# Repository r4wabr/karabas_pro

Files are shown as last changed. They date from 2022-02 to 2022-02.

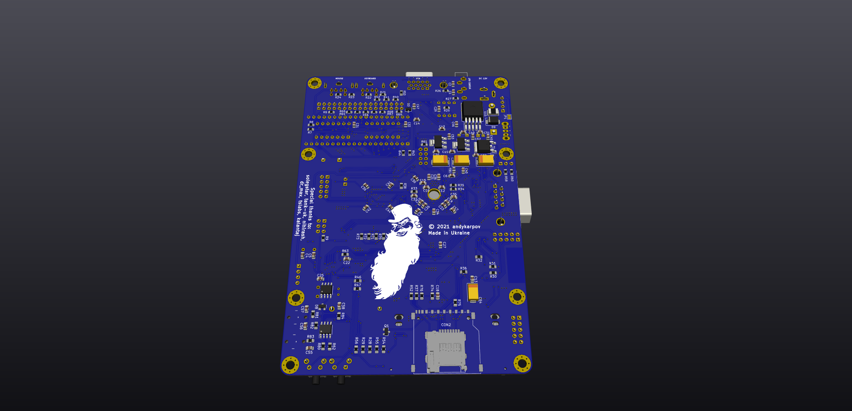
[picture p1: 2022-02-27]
docs/photos/karabas-pro-revDS-bot.png

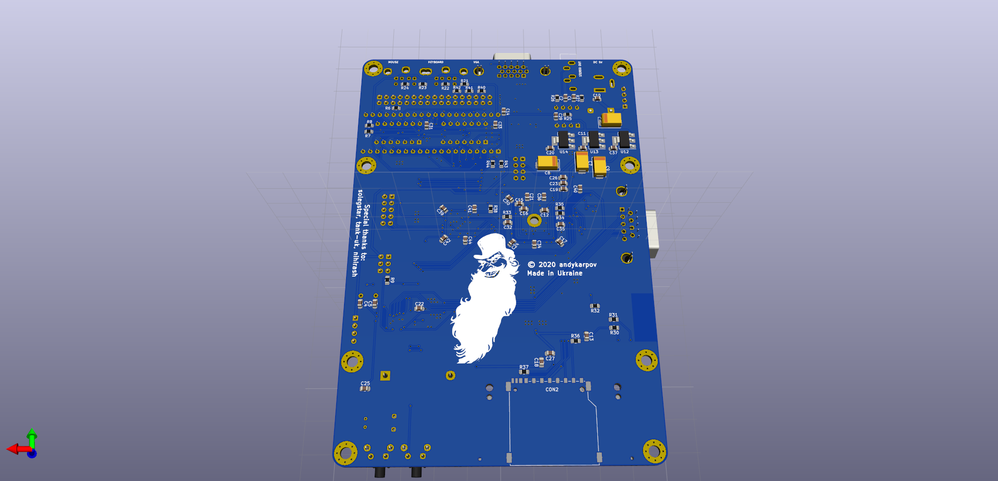
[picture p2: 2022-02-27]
docs/photos/karabas-pro-revB-bot.png

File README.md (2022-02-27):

# Karabas-Pro

**Yet another FPGA ZX Spectrum clone ;)**

## Intro

ZX Spectrum compatible machine with a soft CPU, FDD and HDD (CF card) controllers, PS/2 keyboard/mouse, ESP8266 UART, RTC, VGA output and all logic inside the Altera FPGA **EP4CE6**.

## The idea

The idea was to make a smaller Profi (Профи) ZX Spectrum clone, with real FDD and HDD controllers. The board size fits the dimensions of the real 3.5" floppy drive. 

## Firmwares

**The main firmware is finished and currently it implements:**

1) ZX Spectrum classic and profi hi-res hi-color mode (with palette) (512x240)
2) ZX Profi CMR ports for extended peripherial
3) FDD controller that works both in CP/M and classic modes
4) HDD controller (works in Profi CP/M mode and PQ-DOS mode)
5) PS/2 keyboard (XT keyboard emulation)
6) PS/2 mouse (kempston mouse and serial MS mouse emulation)
7) VGA output (requires a monitor with 50Hz support)
8) Turbosound (2 x AY-3-8912), Soundrive and SAA1099 (SAA will work only on EP4CE10 due to lack of free LEs in EP4CE6)
9) Kempston joystick support
10) SEGA joystick support
11) RTC (profi), emulated read/write support
12) SD card access via Z-Controller emulation
13) Turbo 7 MHz (and Turbo 14 Mhz on EP4CE10)
14) ZX UNO simple UART @115200 for ESP8266 module (a secondary ZX UNO UART available on uBus connector for EP4CE10)
15) An additional ROM bank with **PQ-DOS BIOS**
16) An additional ROM bank with **Flash Tool** by **Doctor Max** to upgrade the FGPA firmware and ROM banks without programmer
17) An additional ROM bank with **FDImage Tool** by **Doctor Max** to extract TRD, SCL, PRO, TD0 and FDI images on real floppies
18) OSD menu
19) OSD full-screen overlay with easy-to-change options, RTC setup, etc.

## More info

**ERRATA for PCB rev.A:** [See ERRATA Rev.A](https://github.com/r4wabr/karabas_pro/blob/master/ERRATA-REVA.md).

**ERRATA for PCB rev.B:** [See ERRATA Rev.B](https://github.com/r4wabr/karabas_pro/blob/master/ERRATA-REVB.md).

**ERRATA for PCB rev.С:** [See ERRATA Rev.С](https://github.com/r4wabr/karabas_pro/blob/master/ERRATA-REVC.md).

**Latest stable revision:** rev.DS'.

**Latest development revision:** rev.E.

**PCB changelog:** [PCB changelog](https://github.com/r4wabr/karabas_pro/blob/master/CHANGELOG-PCB.md).

**Profi firmware** [Download a Profi firmware](https://github.com/r4wabr/karabas_pro/tree/master/firmware/releases/profi).

### Pre-production renders:





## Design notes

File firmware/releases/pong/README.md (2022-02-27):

# Karabas-Pro Pong firmware

## A simple Pong game (backport from ZX EVO)

### Keyboard controls:

**Left player:**
- Q - move up
- A - move down 

**Right player:**
- P or joystick up - move up
- L or joystick down - move down

**Global keys:**
- Space or Ctrl+Alt+Del - restart game
- Menu+F11 - toggle the scanlines effect

## How to flash FPGA and CPLD things

1) Open Quartus Programmer file karabas_pro_pong.cdf
2) Check all chips you want to flash (EPM3128, EP4CE6 and it's configuration device EPCS16), then click Program button

## How to flash the AVR microcontroller:

Use any available programmer, like avrdude.

**Fusebits**

- Low: 0xFF
- High: 0xD7
- Extended: 0xFF

### Example usage:

`avrdude -c usbasp -p m328p -U flash:w:karabas_pro.hex -U lfuse:w:0xFF:m -U hfuse:w:0xD7:m`

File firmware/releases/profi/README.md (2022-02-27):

# Karabas-Pro Profi firmware

## How to flash FPGA and CPLD things

1) Open Quartus Programmer file target/karabas_pro_target_tda1543.cdf or target/karabas_pro_target_tda1543a.cdf (depends of the DAC model on your board)
2) Check all chips you want to flash (EPM3128, EP4CEXX and it's configuration device EPCS16), then click Program button

## How to flash the AVR microcontroller:

Use any available programmer, like avrdude.

Please flash the karabas_pro_revD.hex for PCB rev.D and higher, karabas_pro.hex only on PCBs rev.C or rev.A/rev.B with additional pullup resistors on SW1, SW2 buttons.
Otherwise please flash karabas_pro_revA.hex with hardware buttons disabled.

**Fusebits**

- Low: 0xFF
- High: 0xD7
- Extended: 0xFF

### Example usage:

`avrdude -c usbasp -p m328p -U flash:w:karabas_pro_revD.hex -U lfuse:w:0xFF:m -U hfuse:w:0xD7:m`

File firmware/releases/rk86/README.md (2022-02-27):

# Karabas-Pro Radio-86RK firmware

## How to flash FPGA and CPLD things

### For PCB rev.A and rev.B:

1) Open Quartus Programmer file karabas_pro_rk86_revA_tda1543.cdf or karabas_pro_rk86_revA_tda1543a.cdf (depends on the DAC model on your board)
2) Check all chips you want to flash (EPM3128, EP4CE6 and it's configuration device EPCS16), then click Program button

### For PCB rev.C and up:

1) Open Quartus Programmer file karabas_pro_rk86.cdf
2) Check all chips you want to flash (EPM3128, EP4CE6 and it's configuration device EPCS16), then click Program butt

## How to flash the AVR microcontroller:

Use any available programmer, like avrdude.

**Fusebits**

- Low: 0xFF
- High: 0xD7
- Extended: 0xFF

### Example usage:

`avrdude -c usbasp -p m328p -U flash:w:karabas_pro.hex -U lfuse:w:0xFF:m -U hfuse:w:0xD7:m`

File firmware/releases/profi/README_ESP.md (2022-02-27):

# Updating ESP8266 stock firmware

## How to update ESP8266 stock AT firmware

For some reason, a stock firmware may be outdated and incompatible with the uGoph browser by nihirash.
So, it's easy to update that module without desoldering.

### What you'll need

- The latest release of the AT firmware, better to grab it from the official espressif github repo, like https://github.com/espressif/ESP8266_NONOS_SDK/releases/tag/v3.0.4. Then download and unpack it. The desired AT firmware is under the `bin` folder
- esptool script or other esp8266 flash tool
- An USB-UART module with 3.3v levels

### Step-by-step instruction

1) Open Quartus Programmer file `karabas_pro_esp_bridge.cdf` and flash a service firmware into FPGA, power off the board
2) Connect your USB-UART module: RX pin to PIN_121, TX pin to PIN_141, GND to GND
3) Solder a bridge between GND and the esp8266 GPIO0 pin, restart the board
4) detect a flash chip size by calling the esptool like this: `esptool --port /dev/ttyUSB0 flash_id`
5) For 32Mbit flash use the following command: `esptool --port /dev/ttyUSB0 --baud 115200 write_flash -fm qio -ff 40m -fs 16m-c1 0x00000 boot_v1.7.bin 0x01000 at/1024+1024/user1.2048.new.5.bin 0x1fc000 esp_init_data_default_v08.bin 0xfe000 blank.bin 0x1fe000 blank.bin`
6) You're done. Disconnect the power, desolder a solder bridge, flash a normal karabas_pro firmware (depends on your board revision) into the FPGA
7) Now follow the instructions how to use your ESP8266 module ;)

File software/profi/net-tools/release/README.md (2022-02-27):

Сетевые утилиты для Karabas PRO
===============================

На данный момент они работают только с SD-картой, и им критично расположение в каталоге Wifi(т.е. необходимо скопировать netman.$c, ugophy.$c и player.bin в каталог wifi, находящийся в корне SD-карты).

У утилит нет зависимости от CP/M или PQ-DOS - используется загружаемый FatFS. 

Запускаются утилиты сразу из fatall'а.

Для настройки ESP и подключения к точке доступа используется netman - он проведет инициализацию чипа, получит список сетей и предложит вам выбрать нужную. 

Если там пролетит сообщение ERROR - это нормально. 

После настройки уже можно запускать ugophy и пользоваться им. Как только на экране появится приветственная страница - это означает, что вы уже онлайн(она грузится по сети).

Возможность скачивания файлов присутствует - пользуйтесь ей на здоровье.

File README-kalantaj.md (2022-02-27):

# Инструкция по прошивке Karabas-Pro для Kalantaj

## Как прошить FPGA и CPLD в карабас-про

0) Воткни USB Blaster в 10-контактный разъем
1) Открой в Quartus Programmer файл karabas_pro_tda1543.cdf или karabas_pro_tda1543a.cdf (зависит от того, какой у тебя ЦАП на плате)
2) Отметь галочками, какие чипы (все) шьешь (EPM3128, EP4CE6, EPCS16 итп), затем жмякай на Program button

## Как прошить мегу:

Воткни свой программатор в 6-контактный разъем

Шей файл karabas_pro.hex, если у тебя ревизия платы C.
Шей файл karabas_pro_revA.hex, если у тебя старая revA без доделок.
Шей файл karabas_pro_revD.hex, если у тебя новая rev.D с кучей светиков.

**Фьюзы**

(Если у тебя не дудка, а другой софт - просто выставляй фьюзы)

- Low: 0xFF
- High: 0xD7
- Extended: 0xFF

### Пример вызова дудки:

`avrdude -c usbasp -p m328p -U flash:w:karabas_pro.hex -U lfuse:w:0xFF:m -U hfuse:w:0xD7:m`

Важно: efuse можно не шить, с ним бывают траблы.
Тогда так: `avrdude -c usbasp -p m328p -U flash:w:karabas_pro.hex -U lfuse:w:0xFF:m -U hfuse:w:0xD7:m`

После шитья - передерни. питание.

Все :)

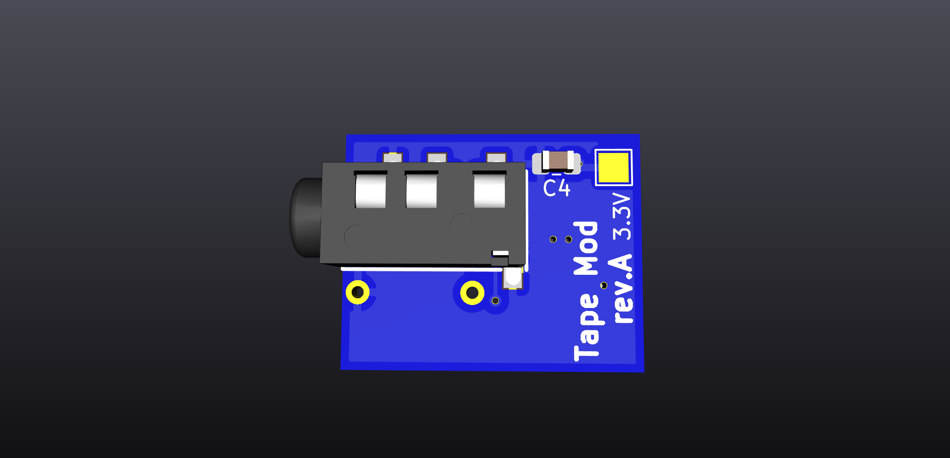
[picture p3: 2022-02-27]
docs/photos/karabas-pro-tapeMod_revA-top-3d.png

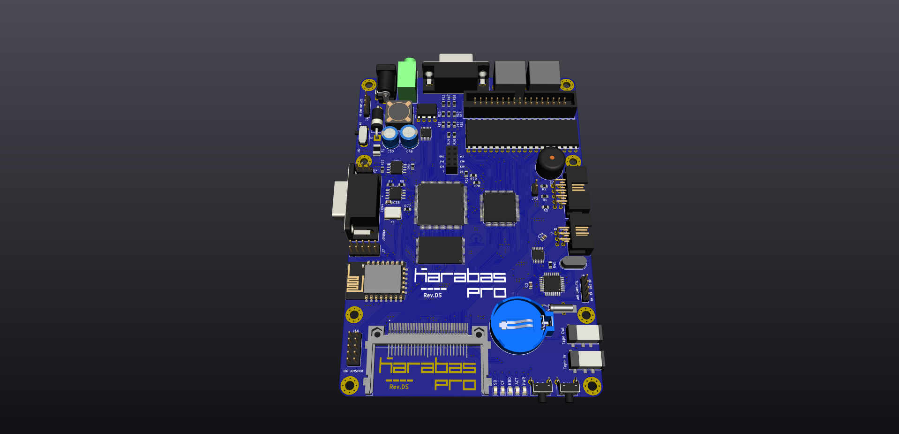
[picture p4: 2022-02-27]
docs/photos/karabas-pro-revDS-top.png

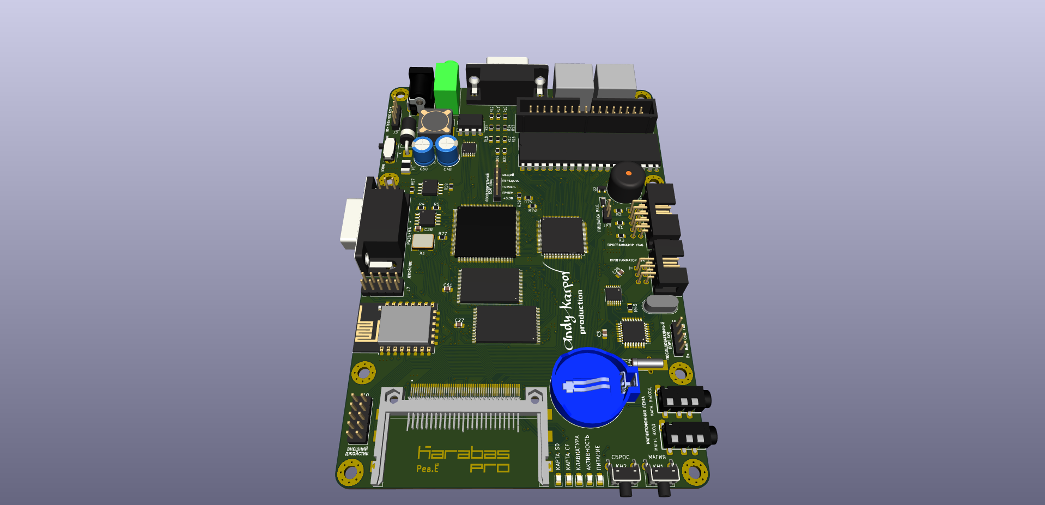
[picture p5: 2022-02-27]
docs/photos/karabas-pro-revER-top.png

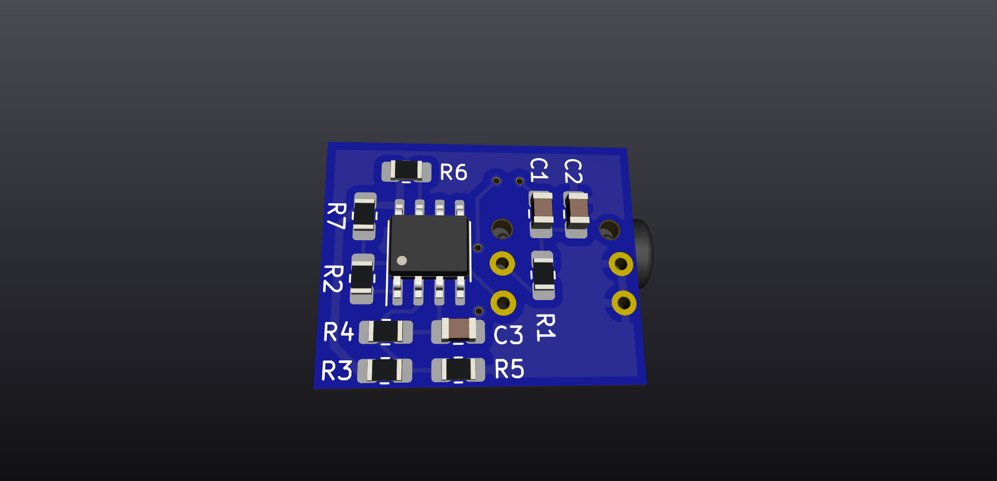
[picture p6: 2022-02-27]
docs/photos/karabas-pro-tapeMod_revA-bottom-3d.png

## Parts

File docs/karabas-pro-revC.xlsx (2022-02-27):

Ref | Q-ty | Value | Footprint
BT1, | 1 | 3V | CR2032 Battery holder
C10, C11, C12, C13, C14, C15, C16, C17, C18, C19, C20, C21, C22, C23, C24, C25, C26, C27, C28, C29, C30, C31, C32, C33, C34, C35, C36, C37, C38, C39, C40, C41, C42, C43, C44, C46, C47, | 37 | 100n | C0805
C1, C2 | 2 | 10uF | C0805
C3, | 1 | 1uF | C0805
C4, C5, | 2 | 22p | C0805
C6, C7, C8, C9, | 4 | 10uF | Tantalum D
C45, | 1 | 470uF | CP_D12.5mm_P7.50mm
CON1, | 1 | CF-CARD | TE_1734451-1
CON2, | 1 | SD | SD_TE_2041021
CON3, | 1 | VGA | DSUB-15-HD_Female
CON4, | 1 | Joystick | DSUB-9_Male
CON5, | 1 | Keyboard | MDIN06SS
CON6, | 1 | Mouse | MDIN06SS
CON7, | 1 | Audio | Jack_3.5mm_CUI_SJ1-3535NG
CON8, | 1 | 5V DC | BarrelJack_Wuerth_6941xx301002
CON9, | 1 | Micro-SD | Molex MicroSD (mirrored)
D1, | 1 | LED1 | L0805
D2, | 1 | LED2 | L0805
D3 | 1 | BAT54C | SOT-23
J1, | 1 | Floppy | IDC-Header_2x17
J2, | 1 | FPGA JTAG | IDC-Header_2x05, angled
J3, | 1 | Floppy 5V | PinHeader_1x04
J4, | 1 | uBus | PinHeader_2x04
J5, | 1 | AVR JTAG | IDC-Header_2x03, angled
J6, | 1 | AVR UART | PinHeader_1x04
R1, R2, R3, | 3 | 2k4 | R0805
R4, | 1 | 27 | R0805
R5, R9, R30, R31, R32, R33, R34, R35, R36, R37, R38, R39, R40, R41, R42, R43, R44, R45, R46, R47, R48, R49, R50, R51, R52, | 25 | 10k | R0805
R6, R11, R14, R17, | 4 | 1k | R0805
R7, R8, R21, R22, R23, R24, | 6 | 4k7 | R0805
R10, R13, R16, | 3 | 1k8 (2k) | R0805
R12, R15, R18, R28, R29, | 5 | '470 (510) | R0805
R19, R20, | 2 | 75 | R0805
R25, | 1 | 820 | R0805
R26, R27, | 2 | 750 | R0805
SW1, SW2, | 2 | SW_Push | SPST_Angled_PTS645Vx58-2LFS
SW3 | 1 | SW_DIP_x04 | SPSTx04_Piano_CTS_Series
U1, | 1 | EP4CE6E22C8N | QFP-144
U2, | 1 | CY62167EV30 (ELL) | TSOP-I-48_18.4x12mm_P0.5mm
U3, | 1 | EPCS16 | M25P16 | SOIC-8_5.23x5.23mm_P1.27mm
U4, | 1 | EPM3128ATC100 | LQFP-100_14x14mm_P0.5mm
U5, | 1 | ATMEGA328-AU | TQFP-32_7x7mm_P0.8mm
U6, | 1 | MB8877A | DIP-40_W15.24mm
U7, U8, | 2 | TXB0104PW | TSSOP-14_4.4x5mm_P0.65mm
U9, | 1 | DS1307Z+ | SOIC-8_3.9x4.9mm_P1.27mm
U10, | 1 | ESP-12E | ESP-12E
U11, | 1 | TDA1543 | DIP-8_W7.62mm
U12, | 1 | AMS1117-3.3 | SOT-223-3
U13, | 1 | AMS1117-2.5 | SOT-223-3
U14, | 1 | AMS1117-1.2 | SOT-223-3
U17, | 1 | 74LS06 | DIP-14_W7.62mm
U18, | 1 | 74LS38 | DIP-14_W7.62mm
X1, | 1 | 50MHz | SG8002CA-4Pin_7.0x5.0mm
Y1, | 1 | 32768Hz | AT310_D3.0mm_L10.0mm
Y2, | 1 | 16MHz | HC49-S

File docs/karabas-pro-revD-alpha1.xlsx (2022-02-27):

Ref | Q-ty | Value | Footprint
BT1, | 1 | 3V | CR2032 Battery holder
C11, C12, C13, C14, C15, C16, C17, C18, C19, C20, C21, C22, C23, C24, C25, C26, C27, C28, C29, C30, C31, C32, C33, C34, C35, C36, C37, C38, C39, C40, C41, C42, C43, C44, C46, C47, C49, C51, | 38 | 100n | C0805
C1, C2 | 2 | 10uF | C0805
C3, | 1 | 1uF | C0805
C4, C5, | 2 | 22p | C0805
C7, C8, C9, | 3 | 10uF | Tantalum D
C48 | 1 | 470uF | CP_Radial_D8.0mm_P3.80mm
C50 | 1 | 220uG | CP_Radial_D7.5mm_P2.50mm
CON1, | 1 | CF-CARD | TE_1734451-1
CON2, | 1 | SD | SD_TE_2041021
CON3, | 1 | VGA | DSUB-15-HD_Female
CON4, | 1 | Joystick | DSUB-9_Male
CON5, | 1 | Keyboard | MDIN06SS
CON6, | 1 | Mouse | MDIN06SS
CON7, | 1 | Audio | Jack_3.5mm_CUI_SJ1-3535NG
CON8, | 1 | 5V DC | BarrelJack_Wuerth_6941xx301002
CON9, | 1 | Micro-SD | Molex MicroSD (mirrored)
D1, D2, D4, D6, D7 | 5 | LED | L0805
D5 | 1 | 1N5820 | D_DO-201AD_P15.24mm_Horizontal
D3 | 1 | BAT54C | SOT-23
J1, | 1 | Floppy | IDC-Header_2x17
J2, | 1 | FPGA JTAG | IDC-Header_2x05, angled
J3, | 1 | Floppy 5V | PinHeader_1x04
J4, | 1 | uBus | PinHeader_2x04
J5, | 1 | AVR JTAG | IDC-Header_2x03, angled
J6, | 1 | AVR UART | PinHeader_1x04
J7, | 1 | ESP-BUS | PinHeader_2x05
JP2 | 1 | Jumper | PinHeader_1x03
L1, | 1 | 68uH | L_12x12mm
R1, R2, R3, | 3 | 2k4 | R0805
R4, R57 | 2 | 27 | R0805
R5, R9, R30, R31, R32, R33, R34, R35, R36, R37, R38, R39, R40, R41, R42, R43, R44, R45, R46, R47, R48, R49, R50, R51, R52, R58, R59, R60, | 28 | 10k | R0805
R6, R11, R14, R17, | 4 | 1k | R0805
R7, R8, R21, R22, R23, R24, | 6 | 4k7 | R0805
R10, R13, R16, | 3 | 2k | R0805
R12, R15, R18, R28, R29, R54, R55, R56, | 8 | '470 (510) | R0805
R53 | 1 | X* (see schematics) | R0805
R19, R20, | 2 | 75 | R0805
R25, | 1 | 820 | R0805
R26, R27, | 2 | 750 | R0805
R61, | 1 | 300 | R0805
SW1, SW2, | 2 | SW_Push | SPST_Angled_PTS645Vx58-2LFS
SW3 | 1 | SW_DIP_x04 | SPSTx04_Piano_CTS_Series
SW4 | 1 | SW_SPST | Slider button switch
U1, | 1 | EP4CE6E22C8N | QFP-144
U2, | 1 | CY62167EV30 (ELL) | TSOP-I-48_18.4x12mm_P0.5mm
U3, U3''1 | 2 | W25Q16 | M25P16 | SOIC-8_5.23x5.23mm_P1.27mm
U4, | 1 | EPM3128ATC100 | LQFP-100_14x14mm_P0.5mm
U5, | 1 | ATMEGA328-AU | TQFP-32_7x7mm_P0.8mm
U6, | 1 | MB8877A | DIP-40_W15.24mm
U7, U8, | 2 | TXB0104PW | TSSOP-14_4.4x5mm_P0.65mm
U9, | 1 | DS1307Z+ | SOIC-8_3.9x4.9mm_P1.27mm
U10, | 1 | ESP-12E | ESP-12E
U11, | 1 | TDA1543 | DIP-8_W7.62mm
U12, | 1 | AMS1117-3.3 | SOT-223-3
U13, | 1 | AMS1117-2.5 | SOT-223-3
U14, | 1 | AMS1117-1.2 | SOT-223-3
U15, | 1 | LM2596S-5.0 | TO-263-5
U17, | 1 | 74LS06 | DIP-14_W7.62mm
U18, | 1 | 74LS38 | DIP-14_W7.62mm
X1, | 1 | 50MHz | SG8002CA-4Pin_7.0x5.0mm
Y1, | 1 | 32768Hz | AT310_D3.0mm_L10.0mm
Y2, | 1 | 16MHz | HC49-S

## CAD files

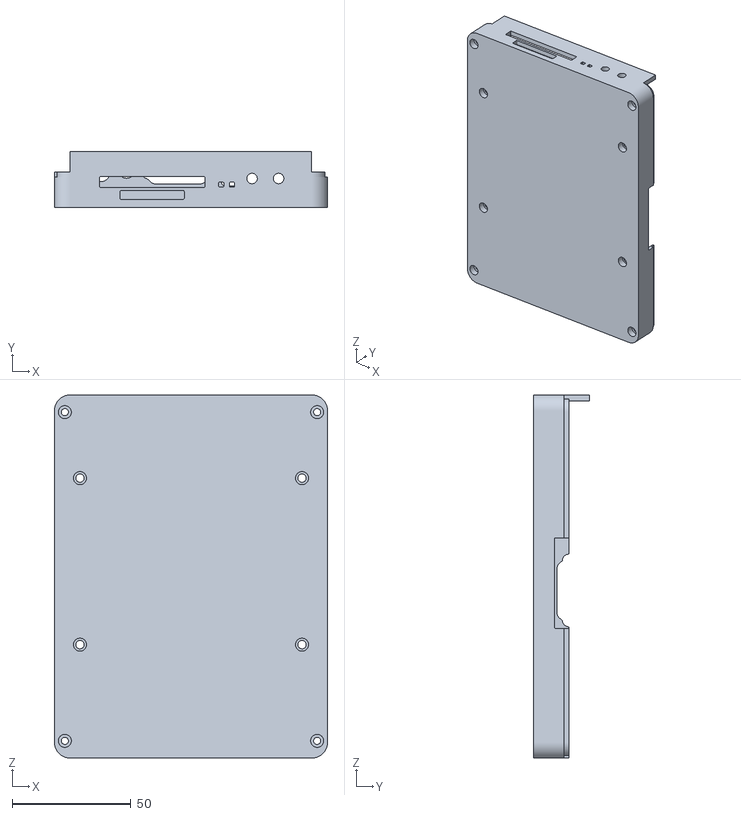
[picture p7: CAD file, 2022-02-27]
cases/revC/Karabas_case_FDD_bottom_v1.stl
115.0 x 23.5 x 152.8

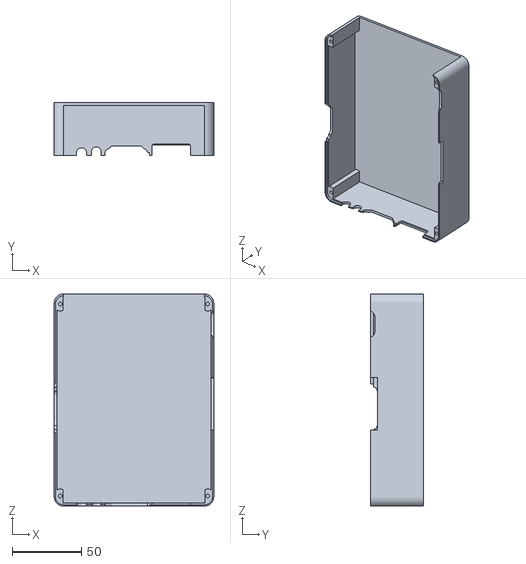
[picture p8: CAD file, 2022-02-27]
cases/revDS/KarabasDS_FDD_Logo_case_top_v1.0.stl
115.0 x 38.1 x 152.8

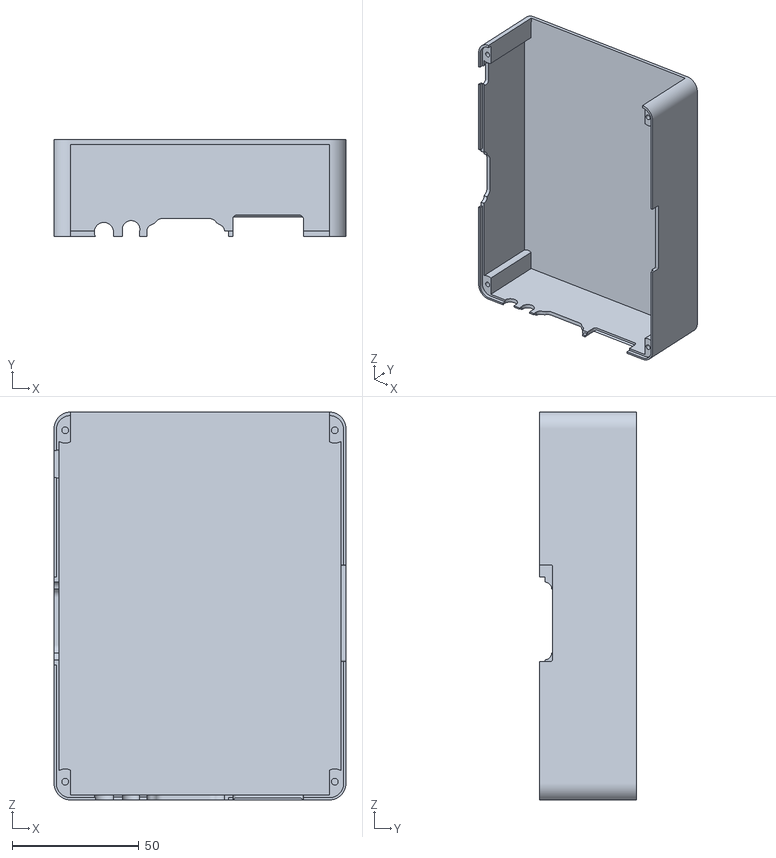
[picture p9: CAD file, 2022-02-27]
cases/revC/Karabas_case_FDD_Logo_top_v1.stl
115.0 x 38.0 x 152.8

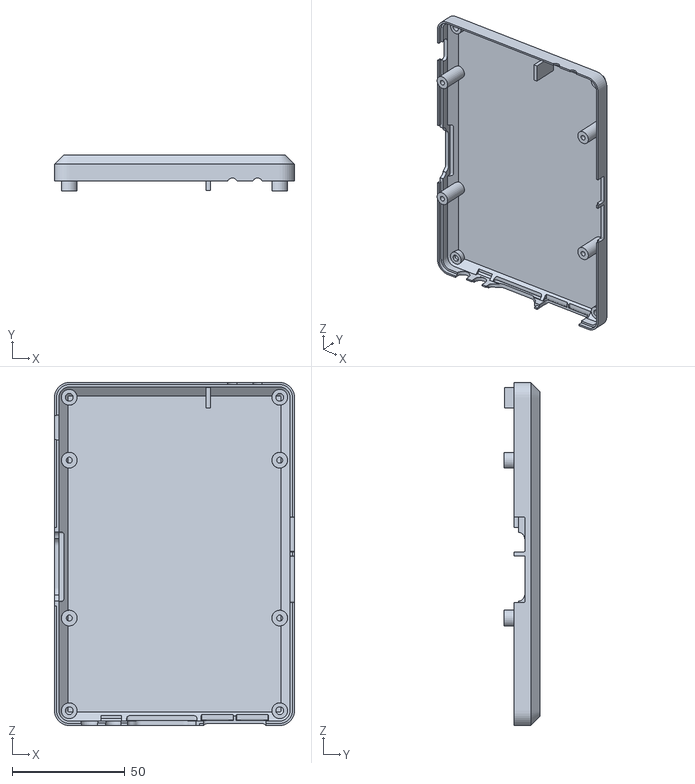
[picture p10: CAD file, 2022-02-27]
cases/revC/Karabas_case_top_v1.2.stl
106.6 x 15.8 x 152.3

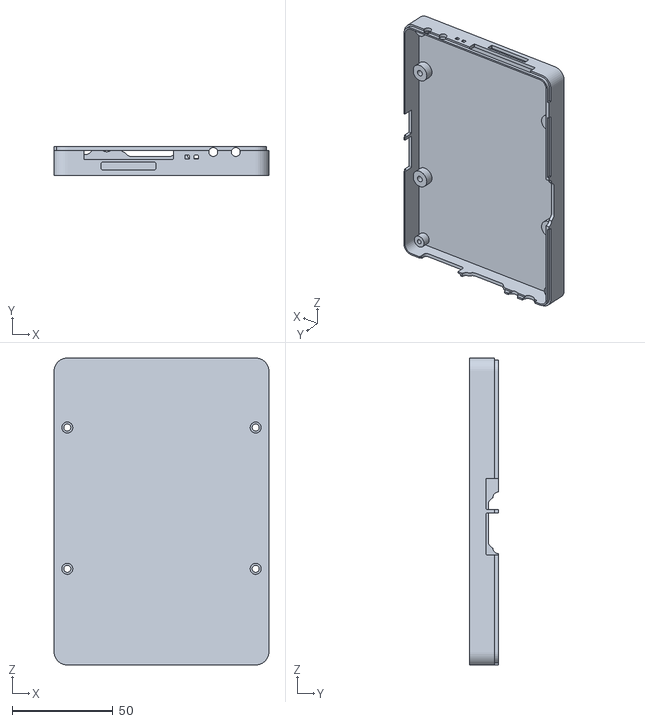
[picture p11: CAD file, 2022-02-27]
cases/revC/Karabas_case_bottom_v1.2.stl
106.6 x 14.4 x 152.3

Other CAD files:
cases/revDS/KarabasDS_FDD_case_bottom_v1.0.stl
cases/revC/Karabas_case_FDD_top_v1.stl
cases/revC/Karabas_case_FDD_bottom_Support_v1.stl

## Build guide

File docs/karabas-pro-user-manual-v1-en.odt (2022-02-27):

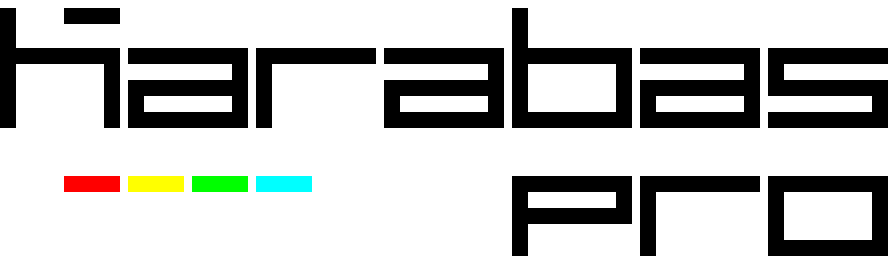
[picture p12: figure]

User’s Manual

v1.0

# Intro

Dear user! Welcome to the retro computers world!

You’re reading a Karabas-Pro development board user’s manual. You’ll be able to recreate one of the famous 8-bit computers from 199x – ZX Spectrum compatible machine named Profi2+.

The following manual will be useful for people who is making the board from scratch or for the already assembled and working board owners.

The project is open-source, licensed by the Open Source Hardware License. All the source code, including the pcb design and firmware are located in git repository - https://github.com/andykarpov/karabas-pro. Feel free to join and collaborate with the project. Let’s make it better ;)

One of the main feature of this project, that highlights it from the others FPGA-based clones is the real floppy disk drive and a hard disk drive (Compact Flash, actually) controllers, so you can use a real floppy disks or Gotek emulator with this board and all the software written for the disked ZX Spectrum and Profi CP/M (Microdos).

To start you’ll need the following:

- VGA compatible monitor with 50Hz support or TV with RGB inputs
- 12V 2A DC power supply for boards starting from Rev.D (center contact – positive) or 5V 2A DC for boards Rev.A...Rev.C.
- PS/2 keyboard and PS/2 mouse
- Sound output device (headphones or active speakers, etc.)
- Mechanical Atari-like joystick or SEGA 3/6 buttons gamepad.
- CF-card (not all vendors are good. Better to choose a Sandisk with 2-8Gb capacity)
- SD-card
- 3.5” spectrum-ready floppy disk drive or Gotek emulator with FlashFloppy firmware
- Some amount of time and patience :)

If the board is not flashed, you’ll also need:

- Altera USB Blaster, byte blaster or other compatible programmer
- AVR programmer (USBasp, TinyISP or other with 6-pin interface)
- Quartus Programmer software to flash the CPLD and FPGA
- avrdude or similar software to flash AVR chip

## Board description

Karabas-Pro PCB fits into the 3.5” floppy drive dimensions. You will be able to mount the floppy disk drive using the board’s mounting holes.

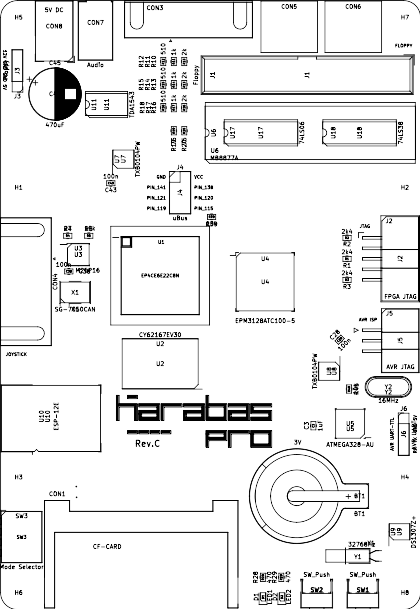
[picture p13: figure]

The PCB contains the following main components:

- FPGA Altera EP4CE10 on the latest revisions, EP4CE6 for older revisions.
- Configuration flash EPCS16 (M25P16, W25Q16, ...)
- CPLD Altera EPM3128
- Static RAM 2MB (6MB on development rev.E)
- FDD conttoller (BDI) based on the MB8877A chip
- PS/2 keyboard, mouse and RTC supported by Atmega 328P controller
- Audio DAC TDA1543 (or TDA1543A)
- SD card connector
- CF card connector
- DB9 connector for the mechanical (Atari) or SEGA joystick

## What’s the current firmware can do

The current firmware is releasing for all pcb revisions (A,B,C,D, DS, E), and is able to recreate the following hardware:

- Profi machine with all specific control ports (CMR0, CMR1)
- T80 soft processor
- 1 MB of RAM by Profi standard (port #dffd)
- RGB 15kHz or VGA 30kHz 50Hz video output
- Pentagon video mode (320 lines, 49 Hz)
- Profi video mode (512x240, 50 Hz)
- Profi 16-color palette
- Turbosound emulation (2x AY-3-8912)
- Profi covox and Soundrive emulation
- SAA1099 sound chip emulation (only available for EP4CE10 FPGA yet)
- XT keyboard emulation (via the 5th bit of the port #FE)
- Kempston mouse and serial mouse implementation (via the COM1 serial port emulation)
- RTC support
- ZXUNO based UART to access ESP8266 at 115200bps
- 4 switchable rom banks
- Turbo mode 7MHz
- Experimental support for 60Hz vertical refresh rate
- TurboWG mode (speed up the FDD head movements)
- New ports decoding scheme to support a modern PQ-DOS operating system
- OSD menu to easy setup a system parameters, including RTC chip

## How it works

After switching on a power to the board, the FPGA will read and start a configuration from the SPI flash device. Then the loader will start a logic to copy the ROMs into the upper area of RAM using a direct access to the RAM. The machine is in the reset state during this operation. After copying all the ROMs into the RAM, a forced reset signal is triggered to start the machine. Now it’s ready to work.

In parallel with the boot process the AVR micro controller initializes the keyboard, mouse and RTC chip. Also the controller will copy the contents of all registers of the RTC chip into FPGA by SPI bus (the controller is always master, FPGA side is a slave). Then the controller sends the keyboard matrix content, mouse and joystick events to the FPGA side in the infinite loop, as well as once per second it sends the RTC time registers.

The external peripherial devices (BDI, HDD) are serviced by the CPLD Altera EPM3128. All required ZX-BUS signals are transferred between FPGA and CPLD by internal parallel 16-bit controlled bus.

# PCB

The PCB is released on the two-sided FR4 1.6mm board. The dimensions are: 147 x 101 mm.

## Connectors

- CON8 – 5 x 2.1 mm DC socket to power the board (5V 2A for revisions A,B,C,C1, 12V 2A for revisions D, DS, E and higher)

- CON7 – 3.5 mm audio jack (TRS)

- CON3 – 15-pin D-SUB to connect VGA monitor or TV (via VGA-to-SCART cable)

- CON5 – Mini Din 6 to connect a PS/2 keyboard

- CON6 – Mini Din 6 to connect a PS/2 mouse

- CON4 – 9-pin D-SUB to connect a machanical Atari-like joystick

- CON1 – 50-pin slot to connect a Compact Flash memory card as HDD storage

- CON2 – an SD card slot

- J6 – 4-pin header AVR UART (5V TTL)

- J5 – 6-pin shrouded header for AVR ISP

- J2 – 10-pin shrouded header for JTAG (both FPGA and CPLD, they are chained)

- J4 – 8-pin general purpose connector (free pins from the FPGA)

- J3 – 4-pin header to power the FDD from the board

## Buttons and switches

- SW1, SW2 – general purpose tact buttons. Currently – unused for rev.A, B. For rev.C and higher – it’s a hard reset and hard reset + S buttons (to enter the internal keyboard port test).

- SW3 – debug dip switches (deprecated, on the latest revision, starting from rev.DS a tape in/out is implemented on those pins)

# Keyboard

The keyboard can work in 2 modes:

- Extended PC XT keyboard

- Classic ZX Spectrum 40-pin keyboard

The extended mode uses an additional bit of port #FE to transfer a functional and extended keys.

## Hotkeys

- Menu + F1 – switch to ROMSET 0 – a standard Profi ROM with Service 2.3 and embedded FatAll software by Savelij

- Menu + F2 – switch to ROMSET 1 – an alternative Profi ROM with PQ-DOS BIOS

- Menu + F3 – switch to ROMSET 2 - FlashTool by Doctor Max

- Menu + F4 – switch to ROMSET 3 - Diag ROM

- Menu + F5 – toggle the TurboFDC state (for boards rev.D alpha 2 and higher)

- Menu + F7 – toggle the SSG stereo mode (ABC / ACB / mono)

- Menu + F8 – toggle the emulated SSG chip type (AY / YM)

- Menu + F9 – toggle the VGA / TV modes

- Menu +F10 – toggle the vertical refresh rate – 50Hz / 60Hz

- Menu + F11 – toggle the Turbo mode 7MHz / normal 3.5MHz

- Menu + F12 – toggle the NMI event to the CPU

- PrtScr – switch the keyboard mode between a standard 40-key and the extended PC XT mode

- Pause – stops the CPU by /WAIT signal

- Ctrl+Alt+Del – throws a RESET signal

- Ctrl+Alt+Esc – throws a NMI signal

- Ctrl+Alt+Backspace – throws a RESET signal + S button to enter the internal keyboard port test service (available only in ROMSET 0)

- Menu + Tab – swaps the FDC drive letters from A<>B

- Menu + ESC – toggle the OSD menu

# Board assembly guide

In this chapter a community experience to assemble and start the machine is collected. Reading this part of manual is not guaranteed to the success, but will close it as much as possible.

## The components

It’s very important to source the electronic components from the confirmed sellers to avoid non-working or partially-working results. The author had a bad experience with many AliExpress sellers multiple times.

## Assembly

Before starting the assembly process – please carefully inspect the PCB. The factory optical and electric control is not enough. Please doublecheck the traces and pads for unwanted shorts or damages. Also please check the power lines with your multimeter if there is no shorts in between them and ground.

The next step – it’s recommended to solder all big SMD chips, like FPGA, CPLD, AVR, flash, etc. DIP components can be skipped on this step.

Then please place and solder all passive and active 2- and 3-pin SMD components (resistors, capacitors, generator, LEDs, etc).

The next step is to clean your soldering from flux by alcohol (liquid or wipes).

The final step is a soldering of all the through hole components (DIP sockets, ICs, connectors, pin headers, electrolytic capacitors, buttons, etc).

## Smoke test

Before the first run please inspect the assembled board for soldering joints quality, as well as check the power lines for shorts. Then you can power the board with the laboratory power unit with current protection at 200mA. If the protection logic is not triggered – then everything is ok and you can try to run the board from the normal power supply.

## Firmware flashing

Now you can flash the firmware. The order of flashing is not so important, but you can start from flashing an AVR controller, then CPLD with FPGA.

The pre-build releases are published on github repository as git tags (releases), as well as the latest release is always pre-compiled here: https://github.com/andykarpov/karabas-pro/tree/master/firmware/releases/profi

### AVR flashing

To flash the Atmega328P, please connect the programmer to the appropriate socket J5 (AVR ISP). Please do not power the board from the programmer. The board should be powered from the external DC supply when programming.

The example of calling avrdude from the command line to flash the AVR using UsbASP programmer:

avrdude -c usbasp -p m328p -U flash:w:karabas_pro_revD.hex -U lfuse:w:0xFF:m -U hfuse:w:0xD7:m -U efuse:w:0xFF:m

When using other programmers, please flash the karabas_pro.hex (or karabas_pro_revD.hex for rev.D and higher) with the following fuse bits:

- Low: 0xFF
- High: 0xD7
- Extended: 0xFF

P.S. Some users reported about difficults when programming the extended fuse. You can skip flashing the extended fuse at all, leaving a factory value there.

### CPLD EPM3128 and FPGA EP4CE6/EP4CE10/EP3C10 flashing

To flash the CPLD and FLGA chips, it’s enough to donwload and install a standalone version of the Quartus Programmer. It’s small enough and you don’t need to download and install a full release of the Quartus software. Version is not important, but not less than 13.0 will be enough for most cases.

Flashing steps:

Open the karabas_pro_revDS_tda1543.cdf or karabas_pro_revDS_tda1543a.cdf file in Quartus Programmer (it depends on what DAC chip is installed on your board).

Then you’ll have to tick the checkboxes Program/Configure behind the CPLD and FPGA (in all rows) and push the Start button.

After successful flashing you’ll have to re-apply the power to the board to start the core.

Attention: please use a filename karabas_pro_revE_tda1543*.cdf, for boards rev.E and karabas_pro_tda1543*.cdf for boards rev.A,B,C,D.

### First run after flashing the firmware

First, you need to connect the VGA monitor, PS/2 keyboard and mouse to the board. If everything is ok – you’ll have to see a welcome screen of the Profi service menu. Congratulations, now your karabas-pro is ready! :)

### Firmware upgrade using a Flash Tool

To upgrade your FPGA firmware without a USB Blaster – there is a special tool located in the ROMBANK2 – Flash Tool by Doctor Max. With this utility you’ll be able to upgrade your FPGA configuration from SD card (rbf-file), as well as upgrade your ROMBANKs contents.

To enter the Flash Tool please use a hotkey Menu+F3.

Please put the desired FPGA firmware rbf-file and/or bin-files of your ROMBANKs you want to upgrade on SD card.

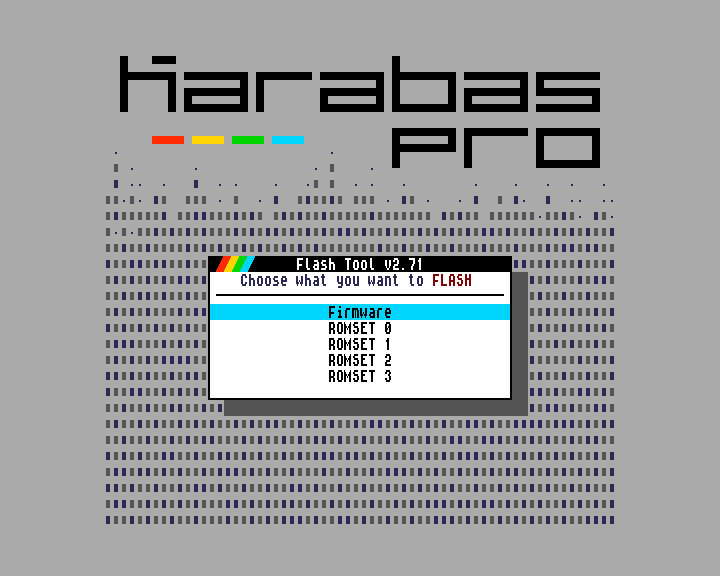
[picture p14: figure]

After choosing an action (Firmware upgrade or ROMSET upgrade), you’ll be asked to confirm the action by accepting an agreement:

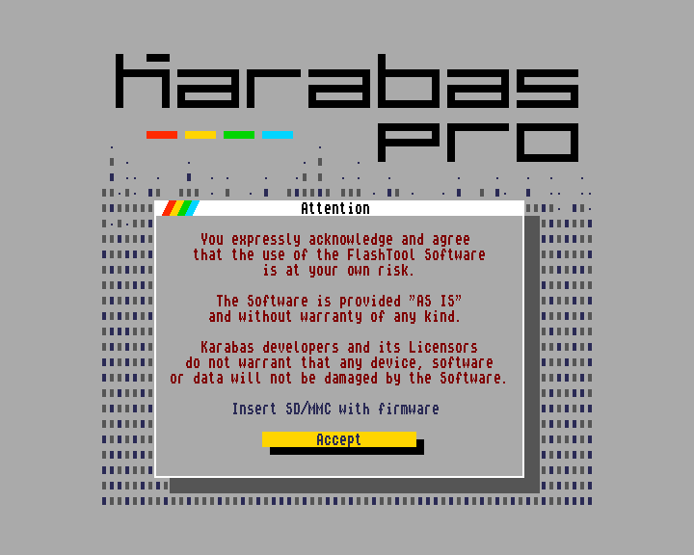
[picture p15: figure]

Then you’ll have to choose a file from SD card and then wait until the writing process is finished:

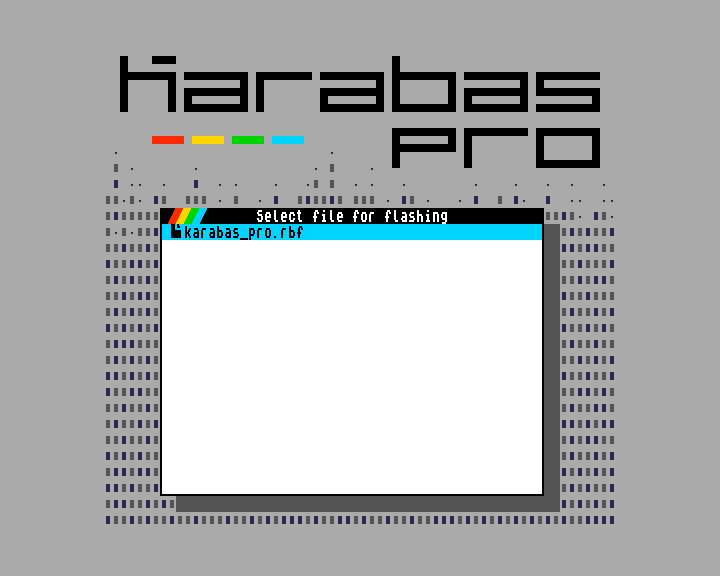
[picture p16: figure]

If you’re finished working with flash tool, please re-apply the power to the board to force the firmware to re-read the new configuration and ROM updates from the flash memory on start.

## FDImage utility

To extract an image (FDI, PRO, TRD, SCL) easily to a real floppy disk, please use a FDImage utility by Dr.Max located in the ROMBANK 3 (by Menu+F4).

With this tool you can select a floppy image from the SD or CF card and extract it on a floppy disk.

A boot screen contains an option to switch a floppy drive (A or B), the source of the file (SD or CF) and jump to a next step – choosing a floppy image. Please select a floppy image file to extract on your floppy:

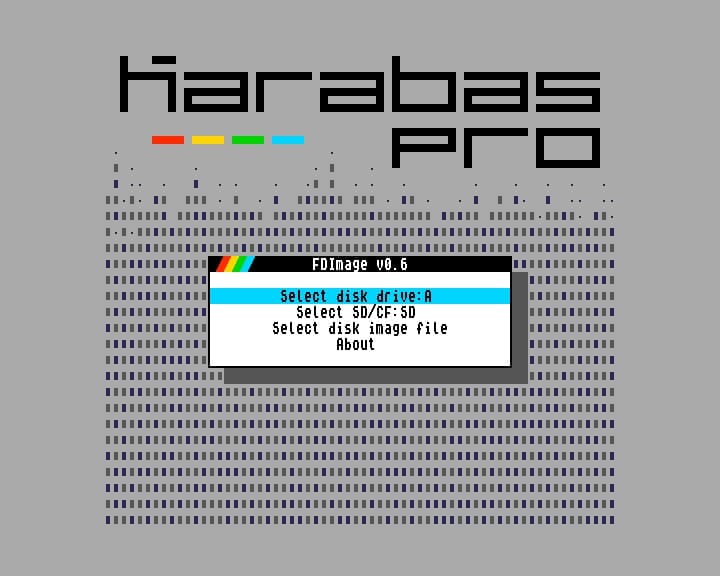
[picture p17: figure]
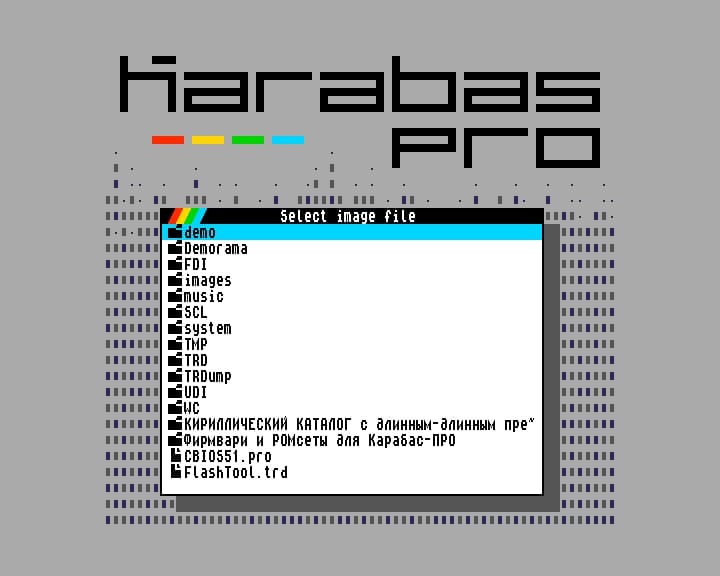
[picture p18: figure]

After that a new progress window will be available. Please do not interrupt the process.

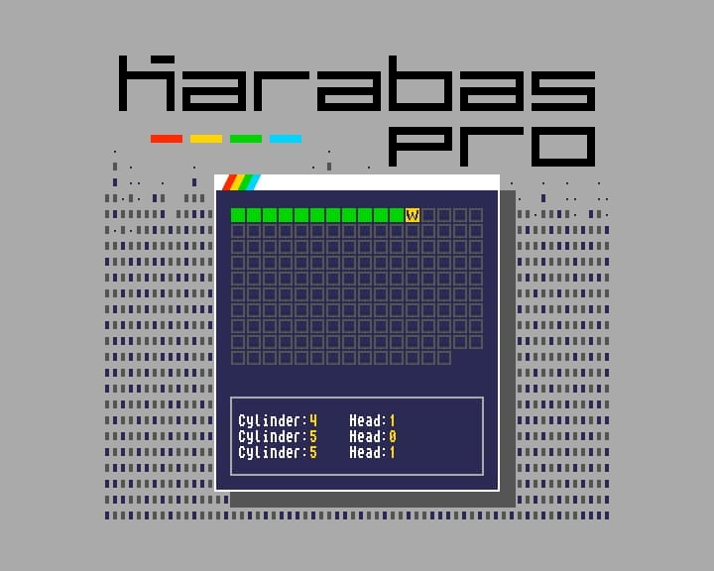
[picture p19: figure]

When the write process is finished, you’re safe to switch back to a rombank 0 or 1 (Menu+F1, Menu+F2) to use your floppy.

If the SCL image has a missing boot-file, and in the root of your SD/CF card a file boot.$B is present, the software will ask you to write that boot-file on your floppy.

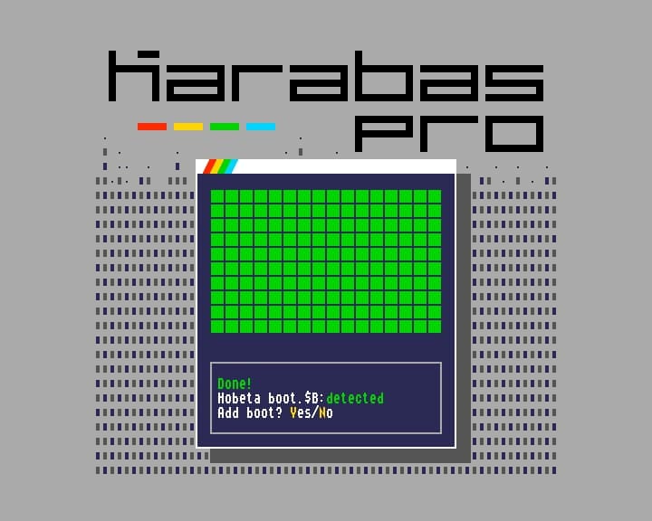
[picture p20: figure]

User’s Manual v1.0

©2021 Andy Karpov. https://github.com/andykarpov/karabas-pro

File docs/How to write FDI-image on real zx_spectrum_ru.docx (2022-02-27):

Методика подходит для записи FDI-образов на реальном ZX-Spectrum, оборудованным одним из таких устройств как - Z-Controller, NeoGS или NemoIDE. На примере компьютера Karabas-Pro.

1. Скачать утилиту Wild Disk Copier со всеми плагинами по ссылке на SD-CARD.

https://github.com/andykarpov/karabas-pro/tree/master/software/profi/tools

2. В Сервисном меню Профи выбрать пункт Fatall 0.26.

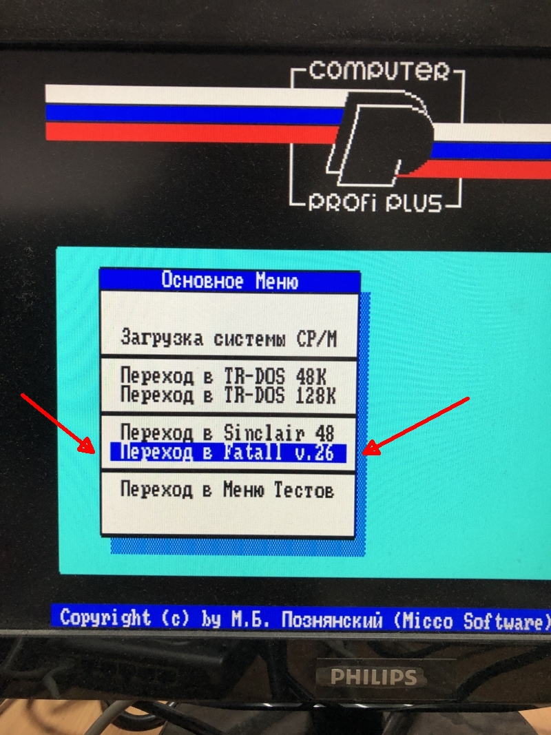
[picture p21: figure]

3. Запустить файл WDC1_26.$C, нажав на нем клавишу Enter.

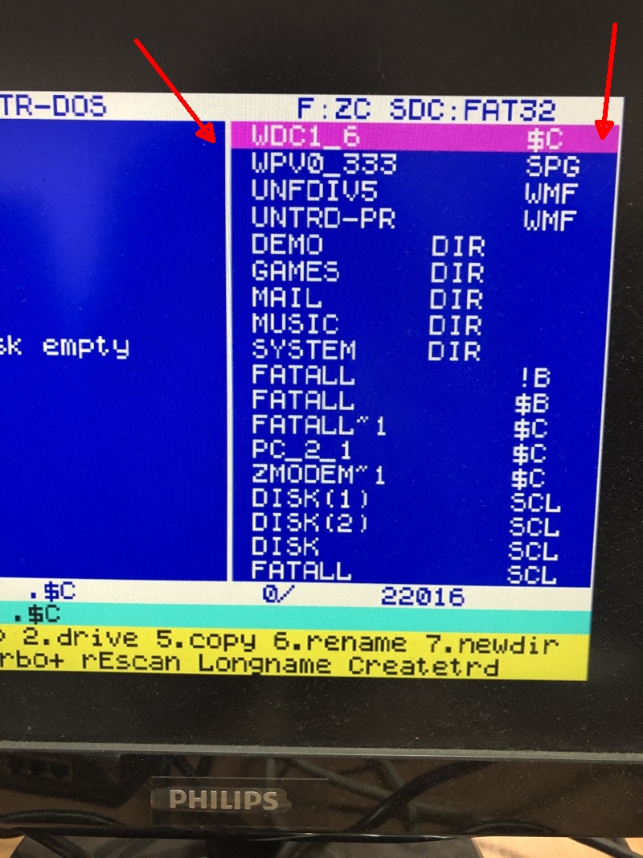
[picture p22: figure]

4. В появившемся меню «Select Driver:» нажать клавишу «3», выбрав драйвер с поддержкой SD-CARD по стандарту ZC (или устройства, которое есть в наличии).

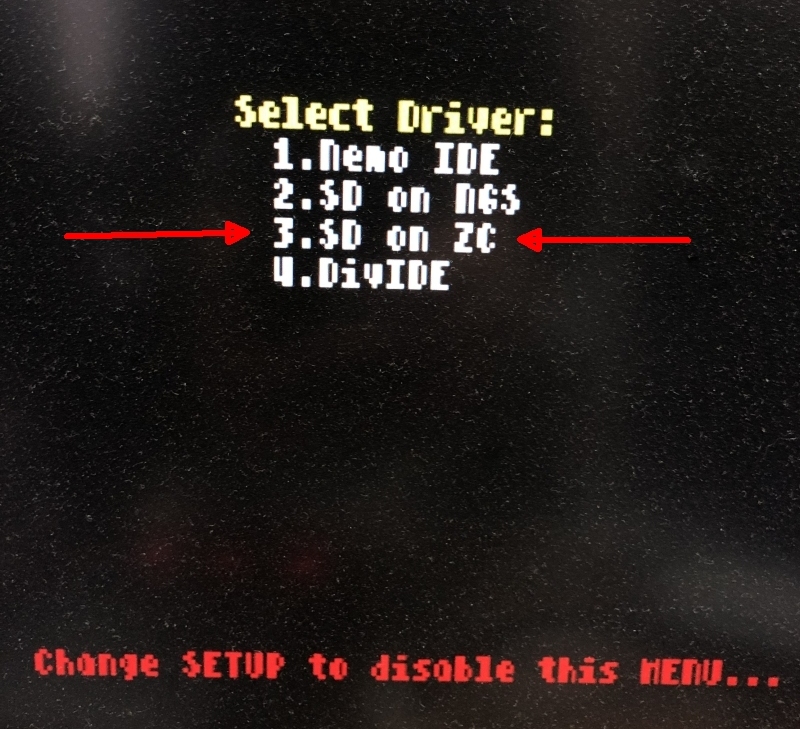
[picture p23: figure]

5. Выделить файл UNFDIV5.WMF и нажать на нем Enter.

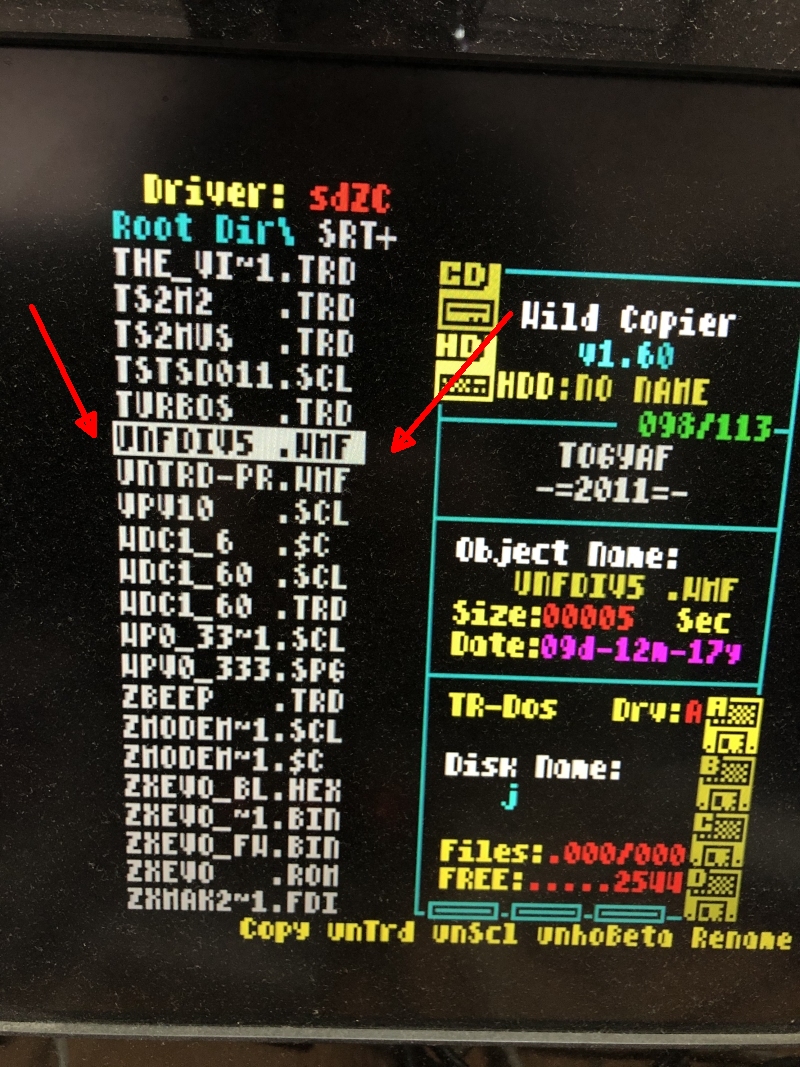
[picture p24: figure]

6. Клавишами 1-4 выбрать дисковод, на который будет записываться образ.
7. Выделить файл с образом *.FDI и нажать клавишу «F».

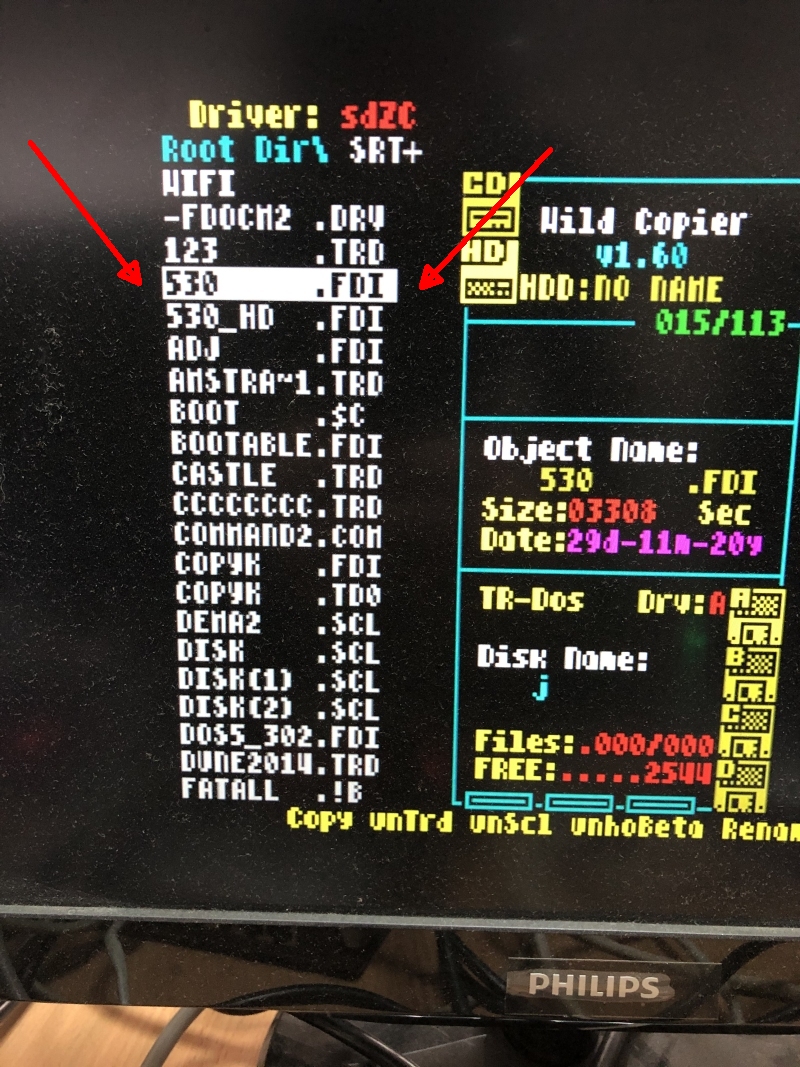
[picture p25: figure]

8. На запрос «Formatting Y/N» нажать клавишу «Y».

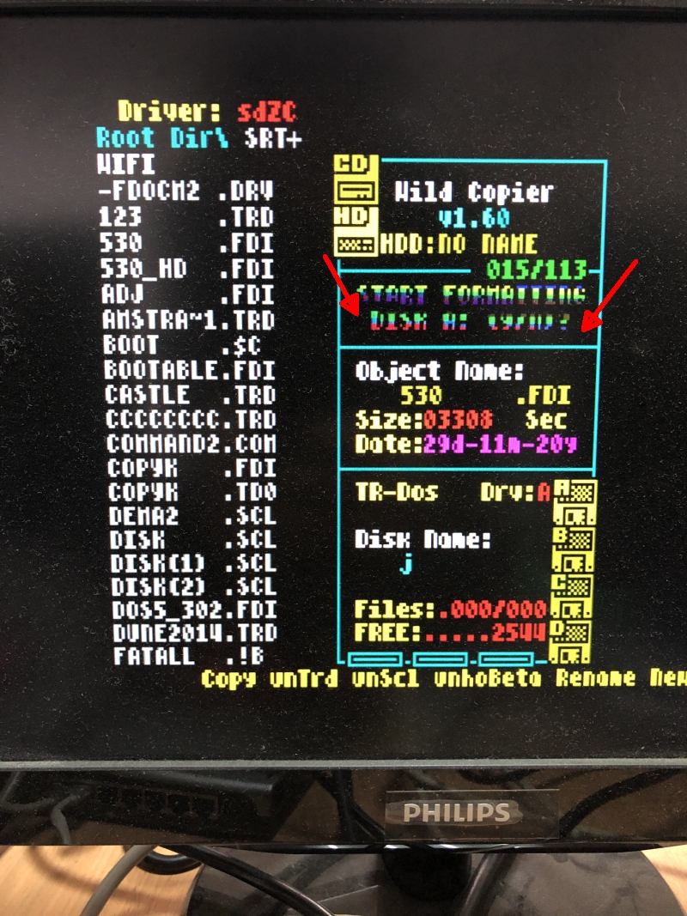
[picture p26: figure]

9. Дождаться записи образа на дискету.

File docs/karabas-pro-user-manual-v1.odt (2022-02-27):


Руководство пользователя

v1.0

# Введение

Уважаемый пользователь! Добро пожаловать в мир ретро-компьютеров!

Перед Вами – руководство по отладочной плате Karabas-Pro, на которой можно воссоздать один из очень крутых 8-битных компьютеров 90-х годов – ZX Spectrum совместимый компьютер Profi2+.

Данное руководство пригодится тем, кто собираем плату с нуля, так и тем, кто имеет уже собранную и запущенную плату.

Проект открытый, распространяется по лицензии Open Source Hardware. Все исходные коды проекта, включая дизайн печатной платы и исходные коды прошивок доступны в git-репозитарии автора – https://github.com/andykarpov/karabas-pro.

Отличительными особенностями данного проекта от других FPGA-проектов являются реальный контроллер дисковода и жесткого диска (Compact Flash), что позволяет безболезненно подключить реальный дисковод либо эмулятор Gotek к плате и пользоваться всем тем софтом, что есть под ZX Spectrum и Profi CP/M, в частности, на реальных дискетах или в виде образов дискет.

Для старта Вам потребуется:

- VGA монитор с поддержкой 50Гц либо телевизор с RGB-входом
- Блок питания 12В 2А (центральный контакт - плюс)
- PS/2 клавиатура и PS/2 мышь
- Устройство вывода звука (наушники либо активные колонки, и тп)
- Механический spectrum (atari)-совместимый либо 3/6 кнопочный SEGA джойстик
- CF-карта
- SD-карта
- 3.5” дисковод или эмулятор Gotek (FlashFloppy)
- Какое-то количество времени и терпения :)

Если плата не прошита, также потребуются:

- Программатор Altera USB Blaster, byte blaster или другой совместимый
- Программатор AVR (USBasp, TinyISP или любой другой с 6-контактным разъемом)
- ПО Quartus Programmer для прошивки CPLD и FPGA
- ПО avrdude или другое ПО для прошивки AVR

## Описание платы

Печатная плата Karabas-Pro имеет геометрические размеры 3.5” дисковода. Монтажные отверстия на плате предполагают крепление реального дисковода к плате с помощью штатных отверстий.


На плате содержится:

- FPGA Altera (EP4CE10 в последних ревизиях, начиная с rev.D, EP4CE6 в предыдущих ревизиях, также возможна установка EP3C10)
- Конфигурационное устройство EPCS16 (M25P16, W25Q16, ...)
- CPLD Altera EPM3128
- Статическая память 2Mb (в ревизии Rev.E - 6Mb)
- Контроллер дисковода (BDI) на базе MB8877A
- Контроллер PS/2 клавиатуры, мыши и часов реального времени на базе Atmega 328P
- ЦАП TDA1543 (или TDA1543A)
- Разъем для карт памяти SD
- Разъем для карт памяти Compact Flash
- Разъем DB9 для подключения механического джойстика ZX Spectrum

## Что умеет прошивка

Текущая прошивка выпускается под все ревизии плат (A,B,C,D,DS,E), и позволяет реализовать такое железо:

- Конфигурация Profi со всеми специфическими портами управления конфигурацией (CMR0, CMR1)
- Софт-процессор T80
- 1 Мб памяти по стандарту Profi
- Режим видео-выхода VGA 50Гц (скандаблер) и режим выхода на ТВ
- Видео-режим ZX Spectrum Pentagon (320 строк, 49 Гц)
- Видео-режим расширенного экрана профи (512x240, 50 Гц)
- Поддержка палитры Profi
- Эмуляция Turbosound (2xAY)
- Эмуляция profi covox
- Эмуляция чипа SAA1099 (только для прошивок EP4CE10, EP3C10)
- Эмуляция XT клавиатуры (через 5й бит порта #FE)
- Эмуляция Kempston мыши и Serial мыши (через эмуляцию штатного порта COM1)
- Эмуляция часов реального времени (ВИ1)
- UART по стандарту ZX UNO для доступа к модулю ESP8266 на скорости 115200bps
- 4 переключаемые банка ПЗУ (для плат rev.C)
- Турбо-режим 7МГц
- Экспериментальный режим развертки 60Гц
- Режим “Туро ВГ”
- Новая дешифрация портов для возможности запуска PQ-DOS
- OSD-меню для удобства настройки параметров и часов реального времени

## Принцип работы

После подачи питания FPGA считывает и стартует конфигурацию из конфигурационной SPI flash-ки. Далее конфигурация FPGA (модуль loader) запускает механизм копирования образов ПЗУ в верхнюю область ОЗУ с помощью прямого обращения к ОЗУ. Компьютер в этот момент находится в сброшенном состоянии. По окончании копирования образов ПЗУ в ОЗУ происходит принудительный сброс конфигурации и компьютер готов к работе.

Параллельно с этим процессом происходит инициализация контроллера клавиатуры, мыши и часов реального времени. В момент старта контроллер также передает состояние всех регистров часов реального времени в FPGA по шине SPI (мастером выступает контроллер). Далее контроллер в бесконечном цикле по SPI передает состояние матрицы клавиатуры ZX Spectrum, раз в секунду передает на сторону FPGA только регистры времени, а по событиям мыши и джойстика – также их состояние.

Внешняя периферия (контроллер BDI, HDD) реализована в CPLD Altera EPM3128, в которую по 8-битной параллельной шине пробрасываются выходные сигналы ZX-шины (ША, ШД, состояние сигналов процессора /WR, /RD, /IORQ, /MREQ, /M1 и другие). В ответ модуль периферии по параллельной 8-битной шине отдает ШД в FPGA.

# Плата

Печатная плата выполнена на фольгированном двустороннем стеклотекстолите марки FR4 толщиной 1.6мм. Геометрические размеры платы: 147 x 101 мм.

## Назначение разъемов

- CON8 – 5 x 2.1 мм разъем для питания платы от БП (5В 2А для ревизий A,B,C,C1, 12В 2А для ревизий D,DS,E и выше)

- CON7 – 3.5 мм аудио разъем (TRS)

- CON3 – 15-контактный D-SUB для подключения VGA монитора или ТВ

- CON5 – Mini Din 6 для подключения PS/2 клавиатуры

- CON6 – Mini Din 6 для подключения PS/2 мыши

- CON4 – 9-контактный D-SUB для подключения механического джойстика

- CON1 – 50-контактный разъем для подключения карт памяти типа Compact Flash

- CON2 – разъем для подключения SD карты

- J6 – 4-контактная гребенка AVR UART (5В TTL)

- J5 – 6-контактный IDC разъем AVR ISP

- J2 – 10-контактный IDC разъем JTAG

- J4 – 8-контактный разъем общего назначения (свободные пины FPGA)

- J3 – 4-контактная гребенка для подачи 5В для питания дисковода

## Кнопки и переключатели

- SW1, SW2 – кнопки общего назначения. На данный момент – незадействованы для ревизий A,B. Для плат ревизии C – это сброс и сброс с зажатой кнопкой S для перехода во встроенное меню тестов порта клавиатуры.

- SW3 – отладочный dip-переключатель (в последних ревизиях отсутствует. Вместо него разведен узел чтения-записи на ленту)

# Клавиатура

Клавиатура умеет работать в 2 режимах:

- Эмуляция расширенной XT клавиатуры

- Эмуляция стандартной 40-кнопочной клавиатуры

В любом из этих режимов от контроллера клавиатуры в FPGA передается матрица состояний ZX-клавиатуры + 5й бит порта #FE для эмуляции расширенной XT клавиатуры.

## Горячие клавиши

- Menu + F1 – переключает ROMSET 0 - стандартная ПЗУ Профи с Service 2.3 и FatAll от Savelij

- Menu + F2 – переключает ROMSET 1 – альтернативная ПЗУ Профи с биосом PQ-DOS

- Menu + F3 – переключает ROMSET 2 - FlashTool by Doctor Max

- Menu + F4 – переключает ROMSET 3 – FDImage by Doctor Max

- Menu + F5 – включает и выключает режим TurboFDC (для ревизий плат D2 и выше, для младших ревизий необходима доработка платы)

- Menu + F7 – переключает режим стерео для SSG звука (ABC / ACB)

- Menu + F8 – переключает режим SSG (AY / YM)

- Menu + F9 – переключает режим VGA / ТВ развертки

- Menu +F10 – переключает режим развертки между стандартным (50Гц) и экспериментальным (60Гц)

- Menu + F11 – переключает Turbo режим 7МГц, 14МГц (для плат с EP4CE10, EP3C10) либо стандартный 3.5МГц

- Menu + F12 – генерирует событие NMI

- PrtScr – переключает режим работы клавиатуры XT / стандартная 40-кнопочная клавиатура

- Pause – останавливает процессор сигналом /WAIT

- Ctrl+Alt+Del – сигнал RESET

- Ctrl+Alt+Esc – сигнал NMI

- Ctrl+Alt+Backspace – сигнал RESET + удерживание кнопки S для попадания во встроенное меню тестов порта клавиатуры (в ROMSET 0)

- Menu + Tab – меняет буквы дисководов A<>B

- Menu + J – переключает режим джойстика Kempston Atari<>SEGA

- Menu + ESC – откроет / спрячет OSD меню

# Порядок сборки и запуска платы

В данном разделе собран коллективный опыт по монтажу и запуску платы. Чтение данной части руководства не гарантирует успех, но приближает его многократно.

## Комплектующие

Очень важно покупать комплектующие у проверенных продавцов, особенно если комплектующие закупаются на сомнительных площадках, типа AliExpress. Автор неоднократно сталкивался с недобросовестными продаванами, которые впаривали перемаркированные и нерабочие детали под видом новых.

## Монтаж

Прежде чем приступать к монтажу – следует внимательно изучить саму печатную плату на предмет заводского брака. Иногда даже известные фабрики допускают брак в виде недотравов или пропущенных переходных отверстий. Важно также проверить с помощью мультиметра, нет ли КЗ по линиям питания (внешним и внутренним).

Далее, автор рекомендует запаять все большие микросхемы поверхностного монтажа – FPGA, CPLD, затем микросхемы поменьше – Atmega328, M25P16 и другие. DIP-компоненты на этом шаге пока не запаиваем.

Далее необходимо запаять все пассивные и актвные 2 и 3-выводные smd-компоненты (резисторы, конденсаторы, генератор, светодиоды).

После того, как все SMD-компоненты запаяны - плату желательно отмыть от остатков флюса. После чего можно приступать к запаиванию выводных компонентов – разъемов, кнопок, штырьков, держателей и тп.

## Первое включение непрошитой платы

Перед первым включением желательно провести оптичкий контроль качества пайки, а также прозвонить линии питания на предмет КЗ. Бывает так, что из-за брака smd-конденсаторов они уже изначально пробиты. Далее желательно подать питание (в зависимости от ревизии платы – 5В либо 12В) от ЛБП с защитой, выставив ток на 200мА. Если защита не сработала – значит можно подключать штатный БП :)

## Прошивка

Теперь можно приступать к прошивке. Порядок прошивки особо не важен, но желательно первым прошить контроллер клавиатуры, а затем CPLD с FPGA.

Для прошивки платы воспользуйтесь заранее собранным релизом, который можно найти на github’е по адресу: https://github.com/andykarpov/karabas-pro/releases

### Прошивка AVR-микроконтроллера

Для прошивки Atmega328, подключите программатор в соответствующий разъем J5 (AVR ISP). Если программатор не обеспечивает подачу 5В собственными средствами, запитайте плату штатным БП.

Пример вызова avrdude из командной строки для прошивки контроллера:

avrdude -c usbasp -p m328p -U flash:w:karabas_pro_revD.hex -U lfuse:w:0xFF:m -U hfuse:w:0xD7:m -U efuse:w:0xFF:m

При использовании других программаторов, прошивайте файл karabas_pro_revD.hex с такими фьюзами:

- Low: 0xFF
- High: 0xD7
- Extended: 0xFF

У некоторых пользователей возникают трудности с прошивкой extended fuse, и его прошивку можно опустить, так как значение efuse влияет только на brown out detection level.

Для более старых плат есть прошивки с именами karabas_pro_revA.hex для плат Rev.A, karabas_pro.hex – для плат до Rev.C включительно (с двумя светодиодами).

### Прошивка CPLD EPM3128 и FPGA EP4CE6

Для прошивки CPLD и FPGA достаточно скачать и установить standalone-версию Quartus Programmer. Она достаточно небольшая и нет необходимости скачивать и устанавливать многогигабайтный дистрибутив Quartus. Версия Quartus Programmer, в принципе, не важна. Можно брать любую последнюю – должно работать.

Порядок прошивки:

Откройте в Quartus Programmer файл karabas_pro_revDS_tda1543.cdf или karabas_pro_revDS_tda1543a.cdf (в зависимости от того, какой тип ЦАП установлен на плате).

Далее необходимо выставить галочки Program/Configure напротив CPLD и FPGA (во всех строчках) и нажать на кнопку Start.

После успешного программирования необходимо отключить от платы питание.

Важно: для плат revE используйте файлы karabas_pro_revE_tda1543*.cdf, для плат ревизий A,B,C,D – используйте файл karabas_pro_tda1543*.cdf.

### Первое включение после прошивки

После того, как плата собрана и прошита – к ней можно подключить клавиатуру, мышь, VGA монитор, блок питания и включить. Если все ок, на плате нет непропаев и залипонов – плата в настройке не нуждается и через 1-2с после подачи питания на экране должна появиться заставка меню тестов Profi.

### Обновление прошивки – Flash Tool

Для обновления прошивки FPGA без использования USB Blaster’а в одном из банков ПЗУ расположена утилита Flash Tool от Doctor Max. С помощью данной утилиты можно обновлять конфигурацию FPGA и заменять содержимое ромсетов с SD-карты, без использования USB Blaster’а.

Для перехода в ромбанк Flash Tool можно воспользоваться комбинацией Menu+F3.

На SD карту неоходимо предварительно положить rbf-файл прошивки FPGA и/или образы ромсетов ПЗУ (rom или bin файлов).


После выбора действия (прошиваем Firmware или один из 4х ROMSET’ов), необходимо подвердить свои намерения принятием соглашения:


Далее необходимо выбрать файл прошивки и дождаться завершения процесса записи:


После того, как все необходимые манипуляции с flash-памятью завершены – необходимо передернуть питание платы, чтобы изменения вступили в силу: данные из flash-памяти считались в ОЗУ при старте.

## Утилита FDImage

Для быстрого и удобного развертывания образов FDI, PRO, TRD, SCL на реальные дискеты по хоткею Menu+F4 доступна утилита FDImage от Doctor Max.

С помощью данной утилиты можно с SD или CF карты выбрать файл образа дискеты и распаковать его на дискету.

На стартовом экране утилита предлагает выбрать дисковод (A или B), источник поиска файлов (SD или CF карта) и перейти на следующий шаг – выбора образа диска.Далее необходимо выбрать нужный образ для распаковки:


После чего откроется диалог записи образа на дискету.


По окончании процесса можно переключиться в нужный (0-й или 1-й) ромсет для использования записанной дискеты.


Однако, если при распаковке SCL образа в нем отсутствовал boot-файл, но в корне карты-источника присутствует boot.$B, то утилита спросит, добавить ли найденный boot на дискету.

Руководство пользователя v1.0

©2021 Andy Karpov. https://github.com/andykarpov/karabas-pro

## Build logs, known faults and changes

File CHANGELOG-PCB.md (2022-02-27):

# Karabas-Pro PCB changelog:

## Rev.ER:
- Added russian labels on the board
- Changed TRRS footprints to a universal SMT/THT
- Added a standalone 3.3V LDO for ESP-8266
- Changed uSD footprint

## Rev.E:
- Added 2 more SRAM chips, up to 6 MB SRAM total, 4 MB available as host RAM, 1-2 MB as host ROM
- Changed uBus with 5-pin header for secondary UART
- Minimum Cyclone chip is EP4CE10 since this revision

## Rev.DS':
- Fixed Q2 footprint 
- Updated R nominals for buzzer and tape in for better compatibility

## Rev.DS:

- Removed DIP switches from the design
- Added an expansion connector for external joystick
- Added support for SEGA 3-button joysticks (mapped vcc and select pins to atmega)
- Added (optional) tape in/out connectors and logic
- Added on-board buzzer with jumper to disable it
- Increased pads length for so-8 flash ics (to support both W25Q16 and M25P16)
- Added free fpga pins 7,25 to the uBus connector
- Increased an fpga pin_145 (thermal pad) diameter from 3mm to 5mm

## Rev.D:

- Added ICs to source the board from 12V power supply instead of 5V
- Added a slide switch to power on/off the board
- Added fuses and supressor to protect the 5V rail from the accidental incorrect power source
- Added more LEDs on the board
- CF card LED mapped to a dedicated CD card "busy" pin
- SD card LED mapped to a /SD_CS signal
- Added a secondary flash chip and jumper
- Added optional 300 Ohm terminators for the FDD
- Added a ferrite filter for the 2.5V rail
- Added more powerful LDO on the 3.3V rail
- Added TurboFDC support
- Added connector with free ESP-12 module pins
- Added a diode assembly to power the RTC chip without battery
- Added a series of additional resistors on CF card /WR, /RD, /CS0, /CS1 pins

## Rev.C1:

- SD CMD pin rerouted to a dedicated FPGA pin 115
- CF card now uses 3.3v rails instead of 5v
- CF card pin 44 (/REG) pulled up to 3.3v

## Rev.C:

- Added 10k pull-up on /AVR_CS line
- Added 10k pull-ups on BTN1, BTN2 lines
- Changed footprint for DB9 connector
- Added DIP-switches on free FPGA lines

## Rev.B:

- Added missing 10k pull-ups on FDC_RDATA,FDC_WPRT, FDC_TR00, FDC_INTRQ, FDC_DRQ
- Changed R25 to 820 Ohm
- Changed R26,R27 to 750 Ohm
- Changed C1,C2 to 10uF
- Moved sound jack a bit left
- Added a restricted zone under the ESP-12 antenna

## Rev.A: 

- Initial revision

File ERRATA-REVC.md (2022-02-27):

# ERRATA rev.C

1) Some SD cards seems conflicts with SPI flash.
Solution: cut a wire from SD card pin 2 (CMD) to ASDO, reroute that SD card pin 2 (CMD) to the FPGA PIN_115.
2) CF card power supply should be changed to 3.3V by cutting 5V track and reroute it to the 3.3V rail.
3) CF card pin 44 (/REG) should be pulled up to 3.3V.

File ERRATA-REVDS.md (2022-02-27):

# ERRATA rev.DS

1) Transistor Q2 has incorrect footprint 
2) R48 value should be 15k...100k

To avoid issuues with buzzer please use the following hotfixes:
- add 100nF capacitor instead of diode D10
- remove R48
- short transistor from base to emitter with 0 Ohm 0603 resistor
- use a piezzo buzzer instead of electromechanical one

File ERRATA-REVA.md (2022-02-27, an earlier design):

# ERRATA rev.A

1) missing 10k pullups for FDC_RDATA,FDC_WPRT, FDC_TR00, FDC_INTRQ, FDC_DRQ
2) R25 should be 820 Ohm
3) R26,27 should be 750 Ohm
4) C1,C2 should be 10uF
5) Sound connector is too close to the VGA
6) ESP-12 module needs a restrict zone under antenna
7) CF-card has incorrect holes layout, doesn't fit the connector
8) On-board power switch is required
9) w25q32 does not work, better to use EPCS16 or M25P16
10) Board required more labels, marks, etc
11) Missing 10k pull-up on the /AVR_CS line
12) Missing 10k pull-ups on the BTN1, BTN2 lines

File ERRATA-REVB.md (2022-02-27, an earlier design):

# ERRATA rev.B

1) Missing 10k pull-up on the /AVR_CS line. Without that pull-up you'll be unable to flash AVR properly on-board.
2) Missing 10k pupp-ups on the BTN1, BTN1 lines.

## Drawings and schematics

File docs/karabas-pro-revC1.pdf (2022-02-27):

VCC C³ 1uF | GND | GND
10k VCC³_3 R³⁶ ¹⁰k | GND

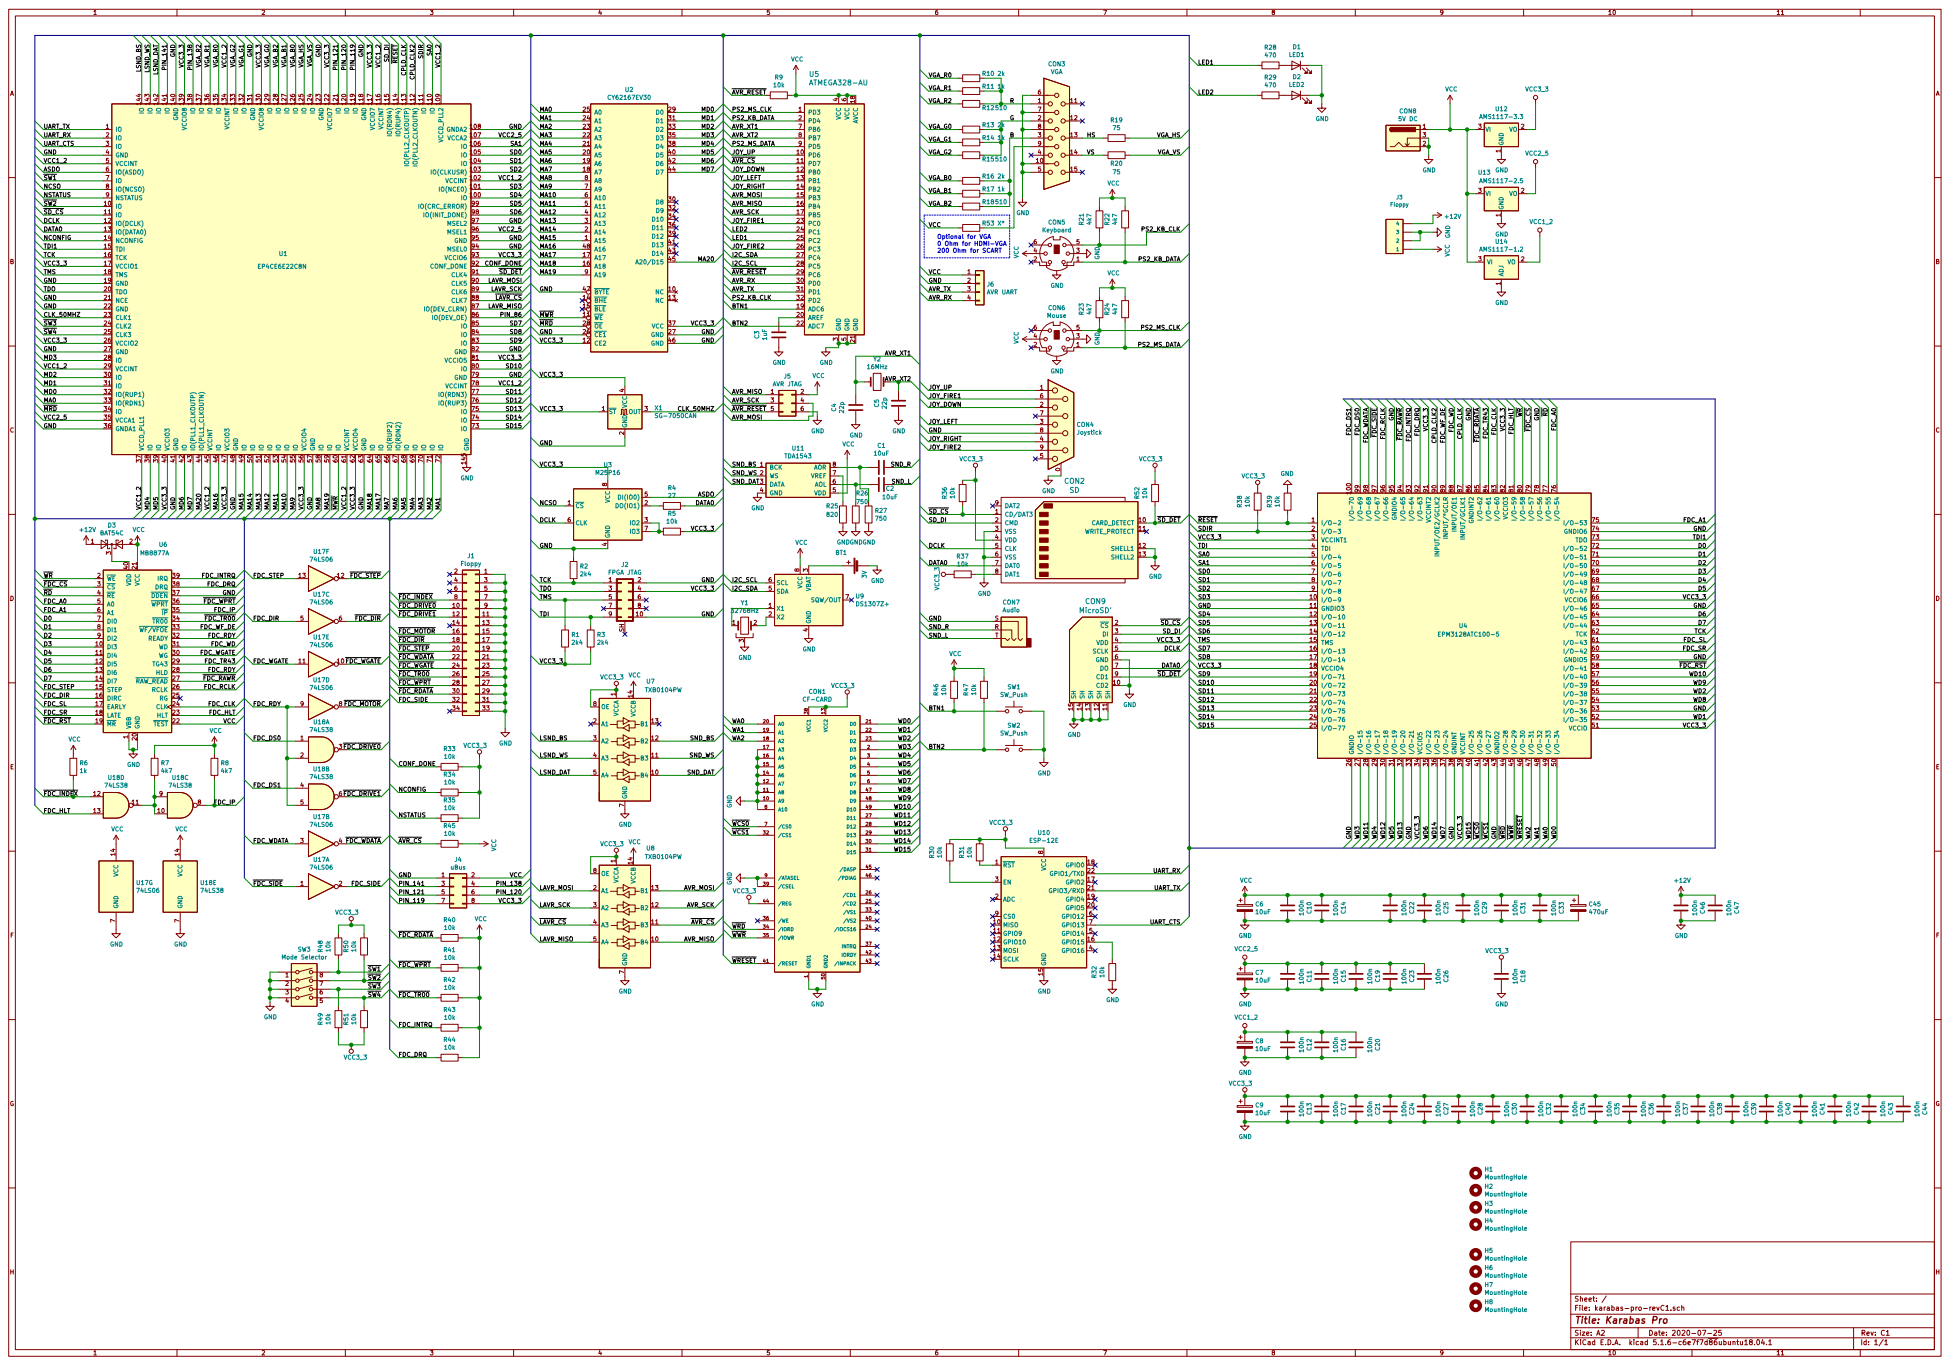
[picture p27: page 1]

6 PB6 7 PB7 8 PD5 9 PD6 10 AREF 20 PD0 30 PD7 11 GND 21 PD1 31 PB0 12 ADC7 22 PD2 32 PB1 13 PC0 23 PB2 14 PC1 24 PB3 15 PC2 25 PB4 16 PC3 26 PB5 17 PC4 27 AVCC 18 PC5 28 ADC6 19 PC6 29 U5ATMEGA328-AU
JOY_LEFT AVR_RESET

IO 2 TDO 20 NCE 21 GND 22 CLK1 23 CLK2 24 CLK3 25 VCCIO2 26 GND 27

Optional for VGA
0 Ohm for HDMI-VGA
200 Ohm for SCART

TDI 15 TCK 16 VCCIO1 17 TMS 18 GND 19

4 SDA 5 SCL 6 SQW/OUT 7 VCC

IP 35 WPRT 36 DDEN 37 DRQ 38

VCC3_3 GND GND WD10 TCK GND

VCC R⁴⁶ ¹⁰k VCC

File: karabas-pro-revC1.sch Sheet: /
Id: 1/1 Title: Karabas Pro

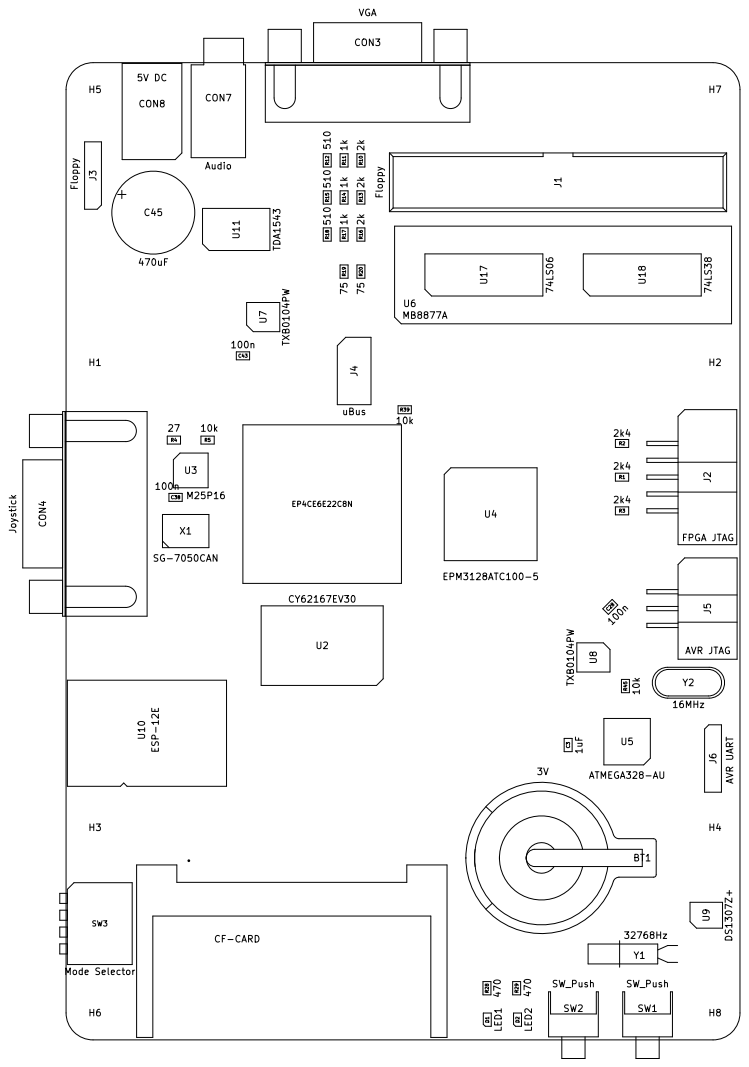
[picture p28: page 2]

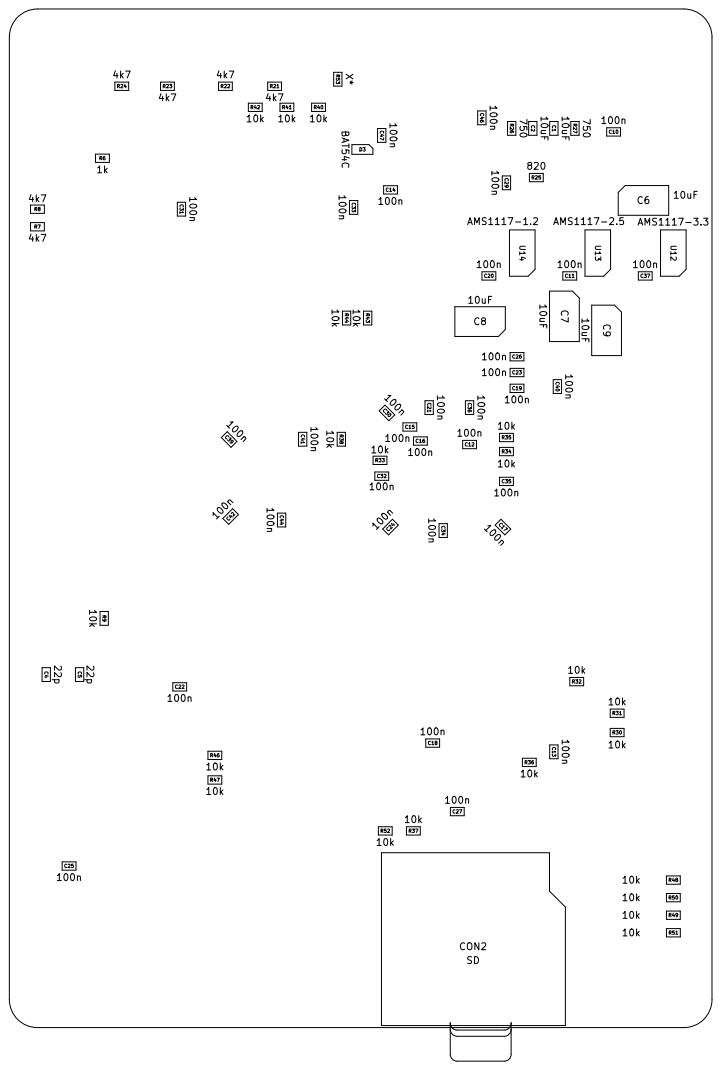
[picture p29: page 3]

# karabas-pro-revC1

Ref | Q-ty | Value | Footprint
BT1, | 1 3V | | CR2032 Battery holder
C10, C11, C12, C13, C14, C15, C16, C17, C18, C19, C20, C21, C22, C23, C24, C25, C26, C27, C28, C29, C30, C31, C32, C33, C34, C35, C36, C37, C38, C39, C40, C41, C42, C43, C44, C46, C47, | 37 100n | | C0805
C1, C2 | 2 10uF | | C0805
C3, | 1 1uF | | C0805
C4, C5, | 2 22p | | C0805
C6, C7, C8, C9, | 4 10uF | | Tantalum D
C45, | 1 470uF | | CP_D12.5mm_P7.50mm
CON1, | 1 CF-CARD | | TE_1734451-1
CON2, | 1 SD | | SD_TE_2041021
CON3, | 1 VGA | | DSUB-15-HD_Female
CON4, | 1 Joystick | | DSUB-9_Male
CON5, | 1 Keyboard | | MDIN06SS
CON6, | 1 Mouse | | MDIN06SS
CON7, | 1 Audio | | Jack_3.5mm_CUI_SJ1-3535NG
CON8, | 1 5V DC | | BarrelJack_Wuerth_6941xx301002
CON9, | 1 Micro-SD | | Molex MicroSD (mirrored)
D1, | 1 LED1 | | L0805
D2, | 1 LED2 | | L0805
D3 | 1 BAT54C | | SOT-23
J1, | 1 Floppy | | IDC-Header_2x17
J2, | 1 FPGA JTAG | | IDC-Header_2x05, angled
J3, | 1 Floppy 5V | | PinHeader_1x04
J4, | 1 uBus | | PinHeader_2x04
J5, | 1 AVR JTAG | | IDC-Header_2x03, angled
J6, | 1 AVR UART | | PinHeader_1x04
R1, R2, R3, | 3 2k4 | | R0805
R4, | 1 27 | | R0805
R5, R9, R30, R31, R32, R33, R34, R35, R36, R37, R38, R39, R40, R41, R42, R43, R44, R45, R46, R47, R48, R49, R50, R51, R52, | 25 10k | | R0805
R6, R11, R14, R17, | 4 1k | | R0805
R7, R8, R21, R22, R23, R24, | 6 4k7 | | R0805
R10, R13, R16, | 3 1k8 (2k) | | R0805
R12, R15, R18, R28, R29, | 5 '470 (510) | | R0805
R19, R20, | 2 75 | | R0805
R25, | 1 820 | | R0805
R26, R27, | 2 750 | | R0805
SW1, SW2, | 2 SW_Push | | SPST_Angled_PTS645Vx58-2LFS
SW3 | 1 SW_DIP_x04 | | SPSTx04_Piano_CTS_Series
U1, | 1 EP4CE6E22C8N | | QFP-144
U2, | 1 CY62167EV30 (ELL) | | TSOP-I-48_18.4x12mm_P0.5mm
U3, | 1 W25Q16 | M25P16 | | SOIC-8_5.23x5.23mm_P1.27mm
U4, | 1 EPM3128ATC100 | | LQFP-100_14x14mm_P0.5mm
U5, | 1 ATMEGA328-AU | | TQFP-32_7x7mm_P0.8mm
U6, | 1 MB8877A | | DIP-40_W15.24mm
U7, U8, | 2 TXB0104PW | | TSSOP-14_4.4x5mm_P0.65mm

# karabas-pro-revC1

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

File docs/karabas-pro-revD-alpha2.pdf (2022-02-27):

# R16 2k GND GND

# R10 2k R11 1k R12 510 R13 2k R14 1k R15 510 GND

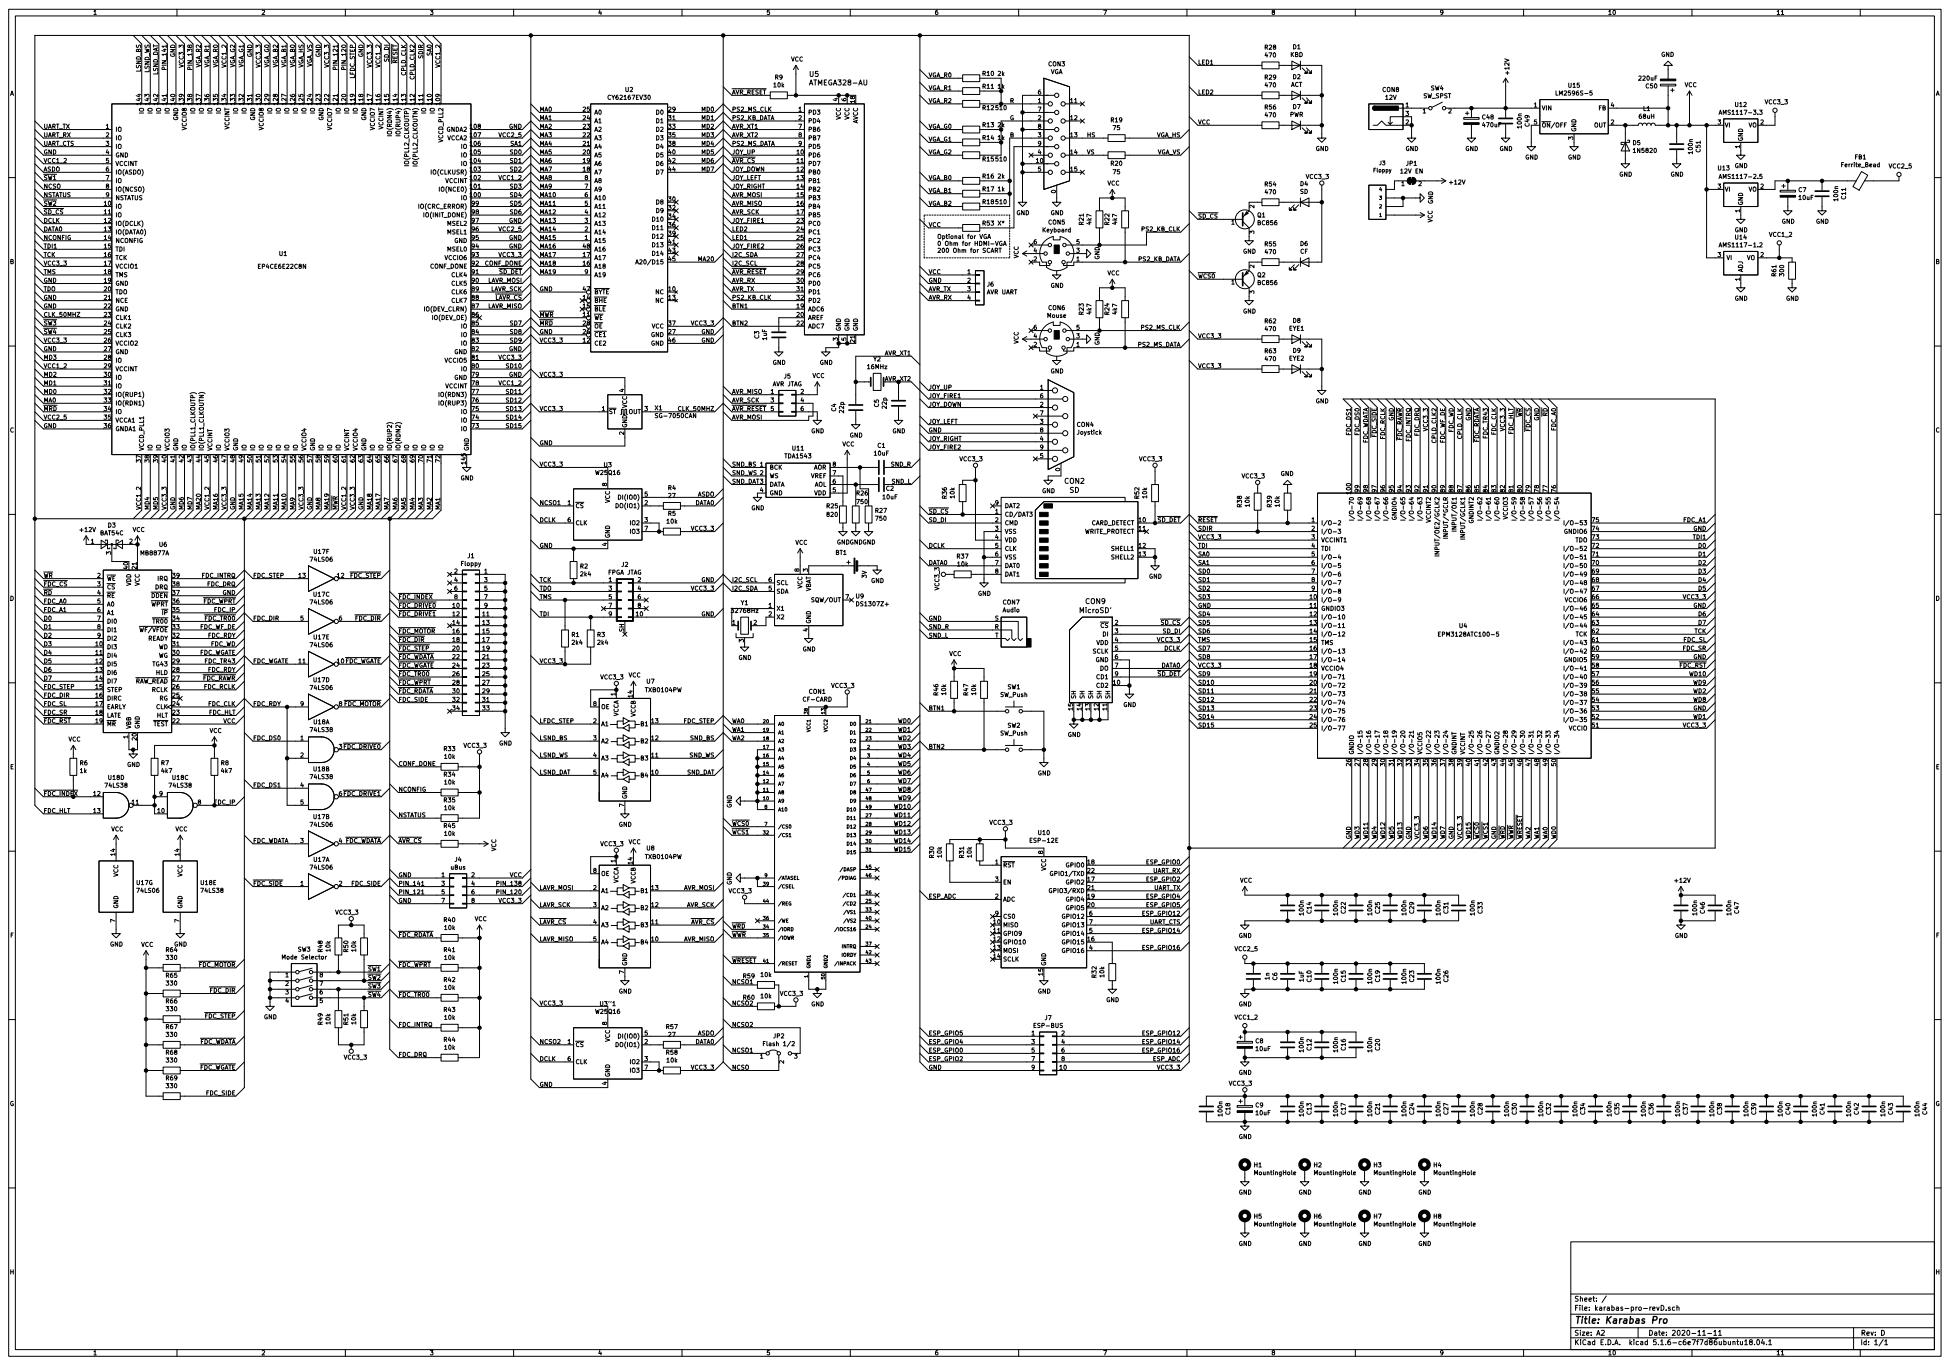
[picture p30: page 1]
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

TDI 15 TCK 16 VCCIO1 17 TMS 18 GND 19

0 Ohm for HDMI-VGA
200 Ohm for SCART

VCC3_3 TDI1 VCC³_3 GND
VCC3_3 MA¹⁵ MA¹⁴ MA¹³ MA¹² MA¹¹ MA¹⁰

4 SDA 5 SCL 6 SQW/OUT 7 VCC

IP 35 WPRT 36 DDEN 37 DRQ 38

File: karabas-pro-revD.sch Sheet: / ¹⁰⁰n C¹⁸

Id: 1/1 Title: Karabas Pro

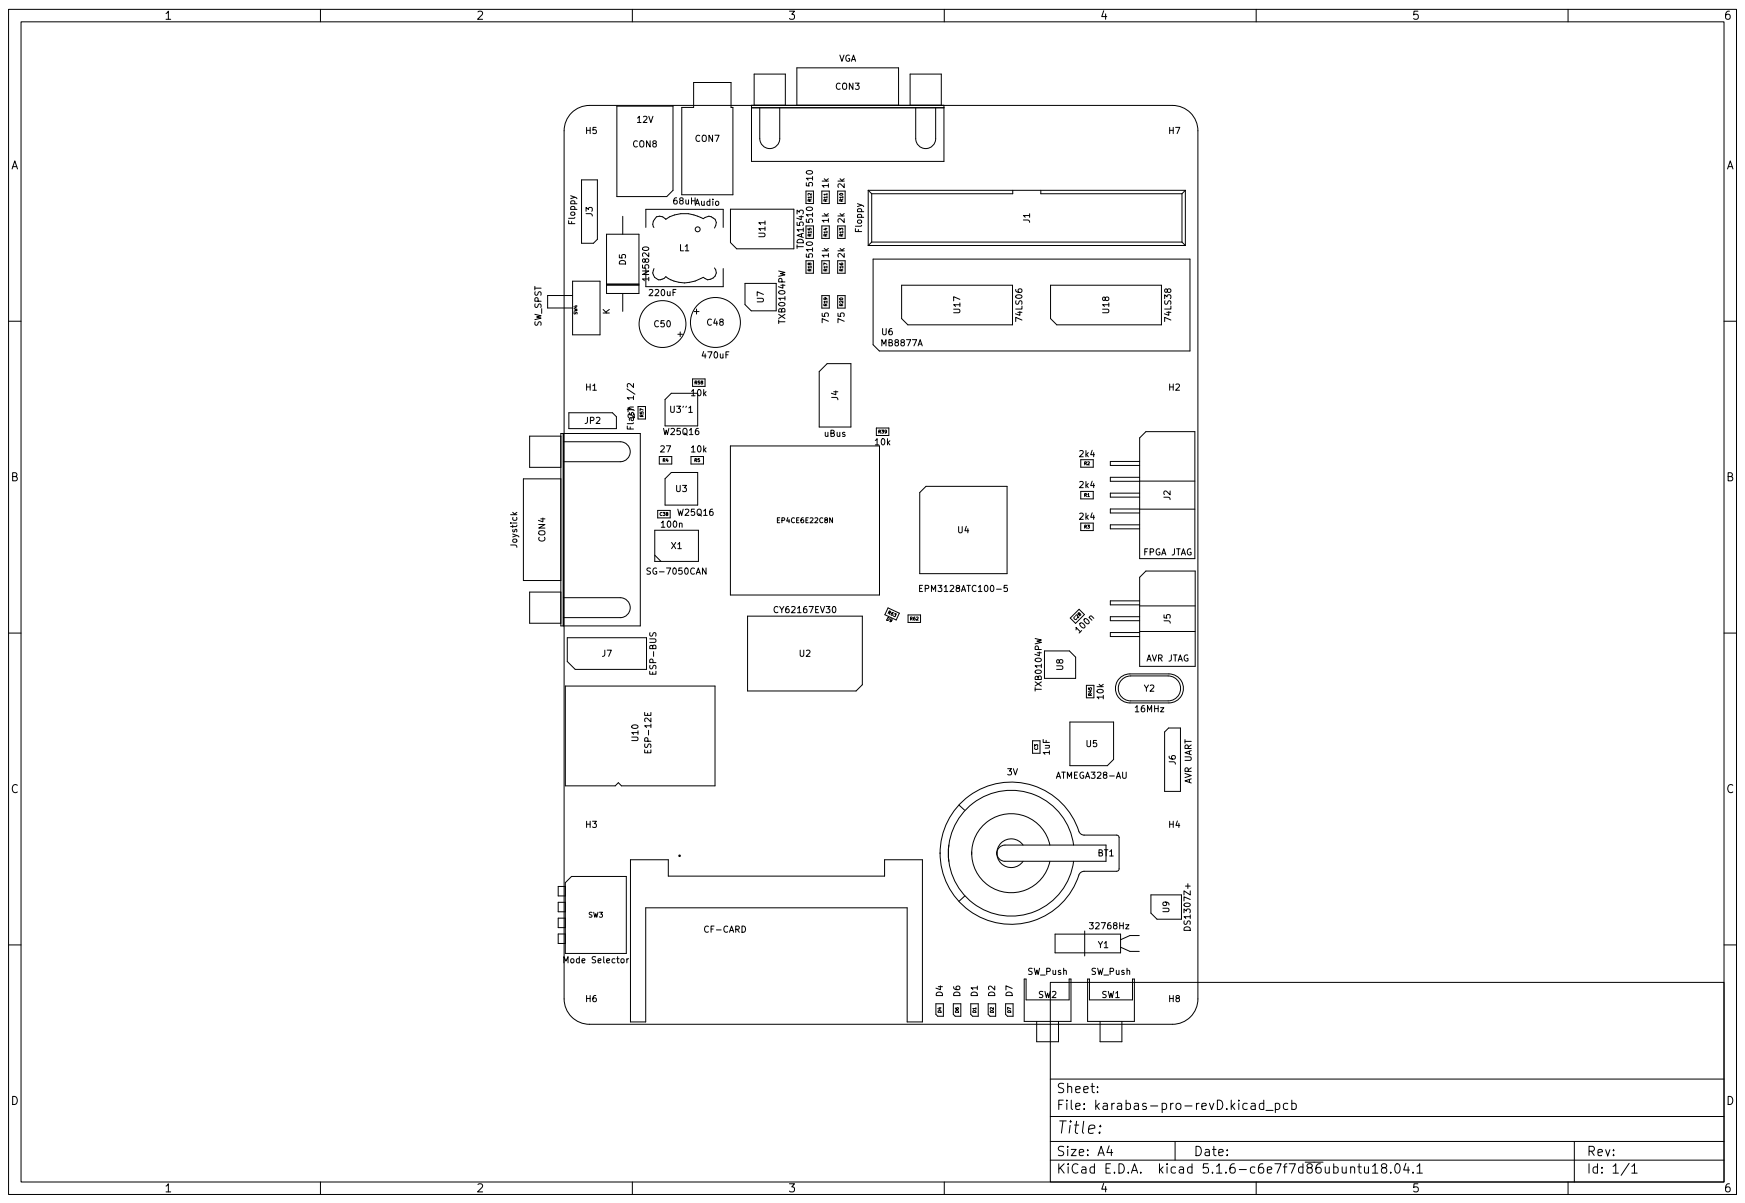
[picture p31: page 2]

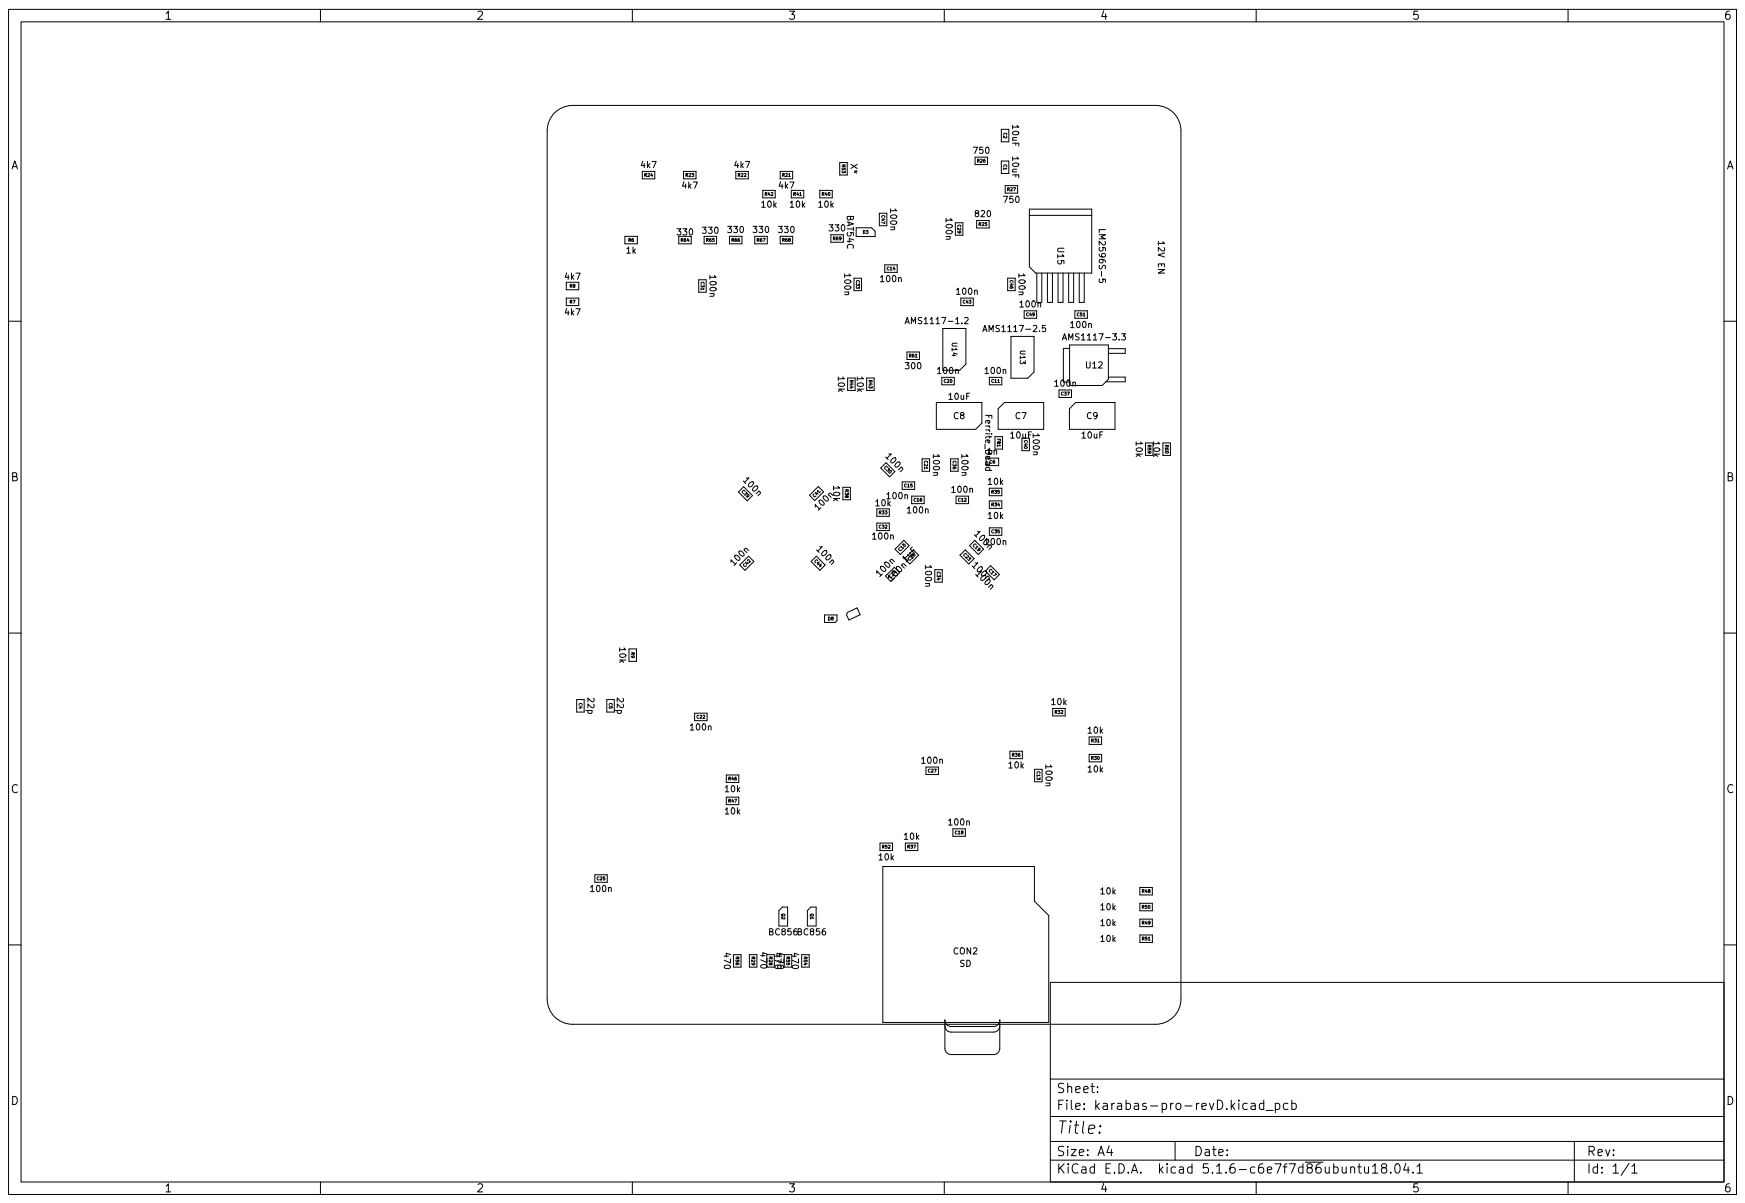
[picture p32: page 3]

# karabas-pro-revD

Ref | Q-ty | Value | Footprint
BT1, | 1 3V | | CR2032 Battery holder
| 38 100n | | C0805
C1, C2 | 2 10uF | | C0805
C3, 10 | 2 1uF | | C0805
C4, C5, | 2 22p | | C0805
C6 | 1 1nF | | C0805
C7, C8, C9, | 3 10uF | | Tantalum D
C48 | 1 470uF | | CP_Radial_D8.0mm_P3.80mm
C50 | 1 220uG | | CP_Radial_D7.5mm_P2.50mm
CON1, | 1 CF-CARD | | TE_1734451-1
CON2, | 1 SD | | SD_TE_2041021
CON3, | 1 VGA | | DSUB-15-HD_Female
CON4, | 1 Joystick | | DSUB-9_Male
CON5, | 1 Keyboard | | MDIN06SS
CON6, | 1 Mouse | | MDIN06SS
CON7, | 1 Audio | | Jack_3.5mm_CUI_SJ1-3535NG
CON8, | 1 5V DC | | BarrelJack_Wuerth_6941xx301002
CON9, | 1 Micro-SD | | Molex MicroSD (mirrored)
D1, D2, D4, D6, D7,D8, D9 | 7 LED | | L0805
| 1 BAT54C 1 Ferrite Bead
D5 | 1 1N5820 | D_DO-201AD_P15.24mm_Horizontal
D3 | | SOT-23
FB1 | | F0805
J1, | 1 Floppy | IDC-Header_2x17
J2, | 1 FPGA JTAG | IDC-Header_2x05, angled
J3, | 1 Floppy 5V | PinHeader_1x04
J4, | 1 uBus | PinHeader_2x04
J5, | 1 AVR JTAG | IDC-Header_2x03, angled
J6, | 1 AVR UART | PinHeader_1x04
J7, | 1 ESP-BUS | PinHeader_2x05
JP2 | 1 Jumper | PinHeader_1x03
L1, | 1 33uH – 68uH | L_12x12mm
R1, R2, R3, | 3 2k4 | R0805
Q1, Q2, | 1 BC856 | SOT-23
R4, R57 | 2 27 | R0805
| 28 10k | R0805
R6, R11, R14, R17, | 4 1k | R0805
R7, R8, R21, R22, R23, R24, | 6 4k7 | R0805
R10, R13, R16, | 3 2k | R0805
R12, R15, R18, R28, R29, R54, R55, R56, R62, R63 | 10 '470 (510) | R0805
R61, R64, R65, R66, R67, R68, R69, | 7 330 | R0805
R53 | 1 X* (see schematics) | R0805
R19, R20, | 2 75 | R0805
R25, | 1 820 | R0805

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

# karabas-pro-revD

R26, R27, | 2 750 | R0805
SW1, SW2, | 2 SW_Push | SPST_Angled_PTS645Vx58-2LFS
SW3 | 1 SW_DIP_x04 1 SW_SPST | SPSTx04_Piano_CTS_Series
SW4 | | Slider button switch
U1, | 1 EP4CE6E22C8N | QFP-144
U2, | 1 CY62167EV30 (ELL) | TSOP-I-48_18.4x12mm_P0.5mm
U3, U3''1 | 2 W25Q16 | M25P16 | SOIC-8_5.23x5.23mm_P1.27mm
U4, | 1 EPM3128ATC100 | LQFP-100_14x14mm_P0.5mm
U5, | 1 ATMEGA328-AU | TQFP-32_7x7mm_P0.8mm
U6, | 1 MB8877A | DIP-40_W15.24mm
U7, U8, | 2 TXB0104PW | TSSOP-14_4.4x5mm_P0.65mm
U9, | 1 DS1307Z+ | SOIC-8_3.9x4.9mm_P1.27mm
U10, | 1 ESP-12E | ESP-12E
U11, | 1 TDA1543 (A) | DIP-8_W7.62mm
U12, | 1 1117-3.3 | DPAK
U13, | 1 1117-2.5 | SOT-223-3
U14, | 1 1117-1.2 | SOT-223-3
U15, | 1 LM2596S-5.0 | TO-263-5
U17, | 1 74LS06 | DIP-14_W7.62mm
U18, | 1 74LS38 | DIP-14_W7.62mm
X1, | 1 50MHz | SG8002CA-4Pin_7.0x5.0mm
Y1, | 1 32768Hz | AT310_D3.0mm_L10.0mm
Y2, | 1 16MHz | HC49-S

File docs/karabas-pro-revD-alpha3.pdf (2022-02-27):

# R10 2k R11 1k R12 510 R13 2k R14 1k R15 510 R16 2k R17 1k GND

75 R20

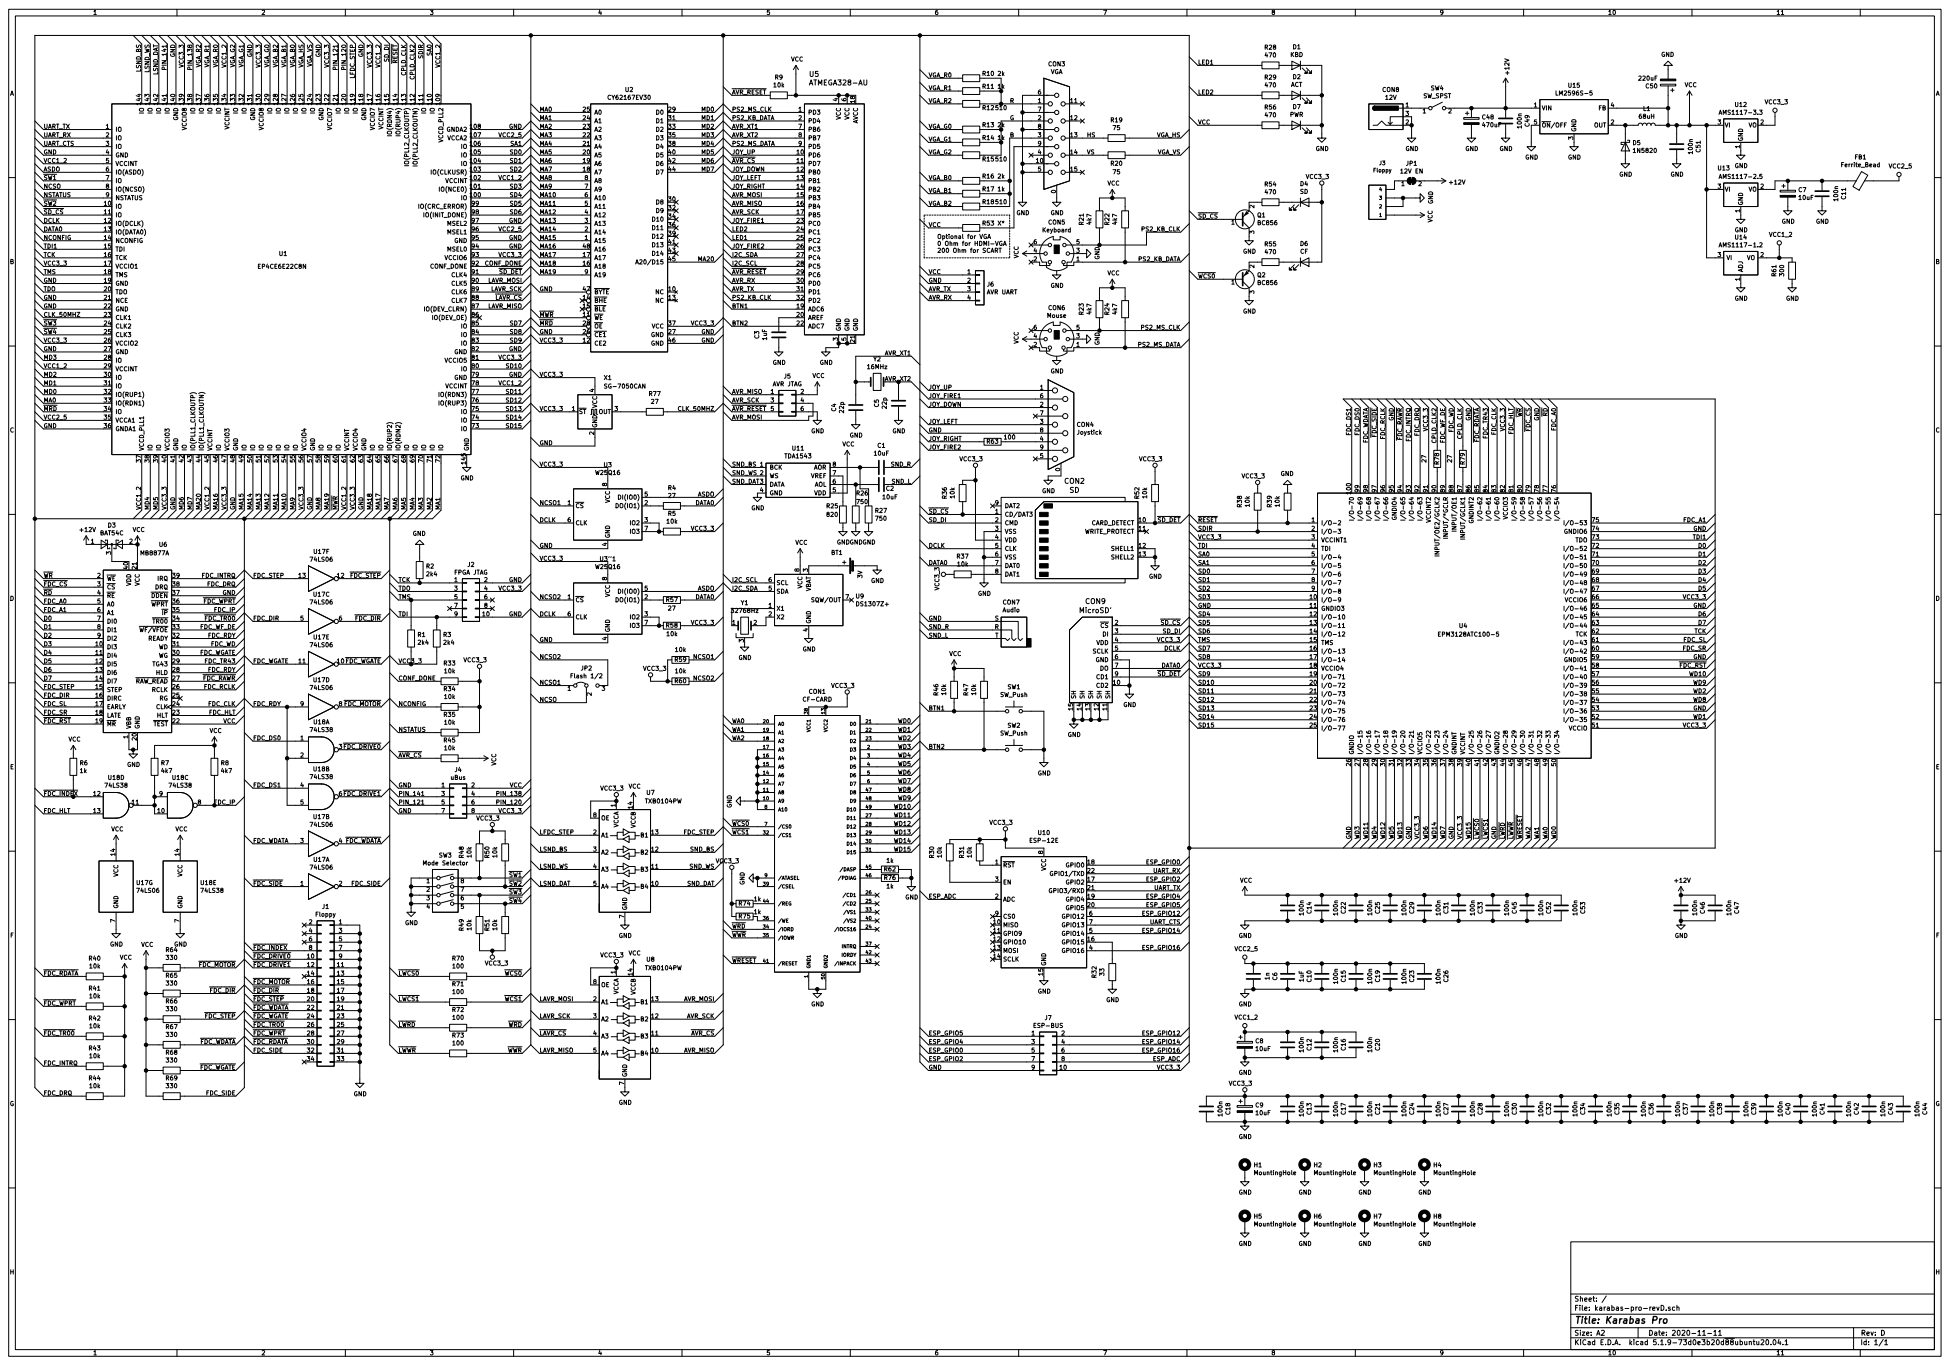
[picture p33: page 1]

6 PB6 7 PB7 8 PD5 9 PD6 10 AREF 20 PD0 30 PD7 11 GND 21 PD1 31 PB0 12 ADC7 22 PD2 32 PB1 13 PC0 23 PB2 14 PC1 24 PB3 15 PC2 25 PB4 16 PC3 26 PB5 17 PC4 27 AVCC 18 PC5 28 ADC6 19 PC6 29 U5ATMEGA328-AU

IO 2 TDO 20 NCE 21 GND 22 CLK1 23 CLK2 24 CLK3 25 VCCIO2 26 GND 27

VCC
Optional for VGA
0 Ohm for HDMI-VGA
200 Ohm for SCART

TDI 15 TCK 16 VCCIO1 17 TMS 18 GND 19

File: karabas-pro-revD.sch Sheet: / ¹⁰⁰n C³¹ VCC³_3 R³⁶ ¹⁰k

ESP_GPIO14 MA⁵ MA⁴ MA³ MA² FDC_MOTOR

4 SDA 5 SCL 6 SQW/OUT 7 VCC

IP 35 WPRT 36 DDEN 37 DRQ 38

Id: 1/1 Title: Karabas Pro

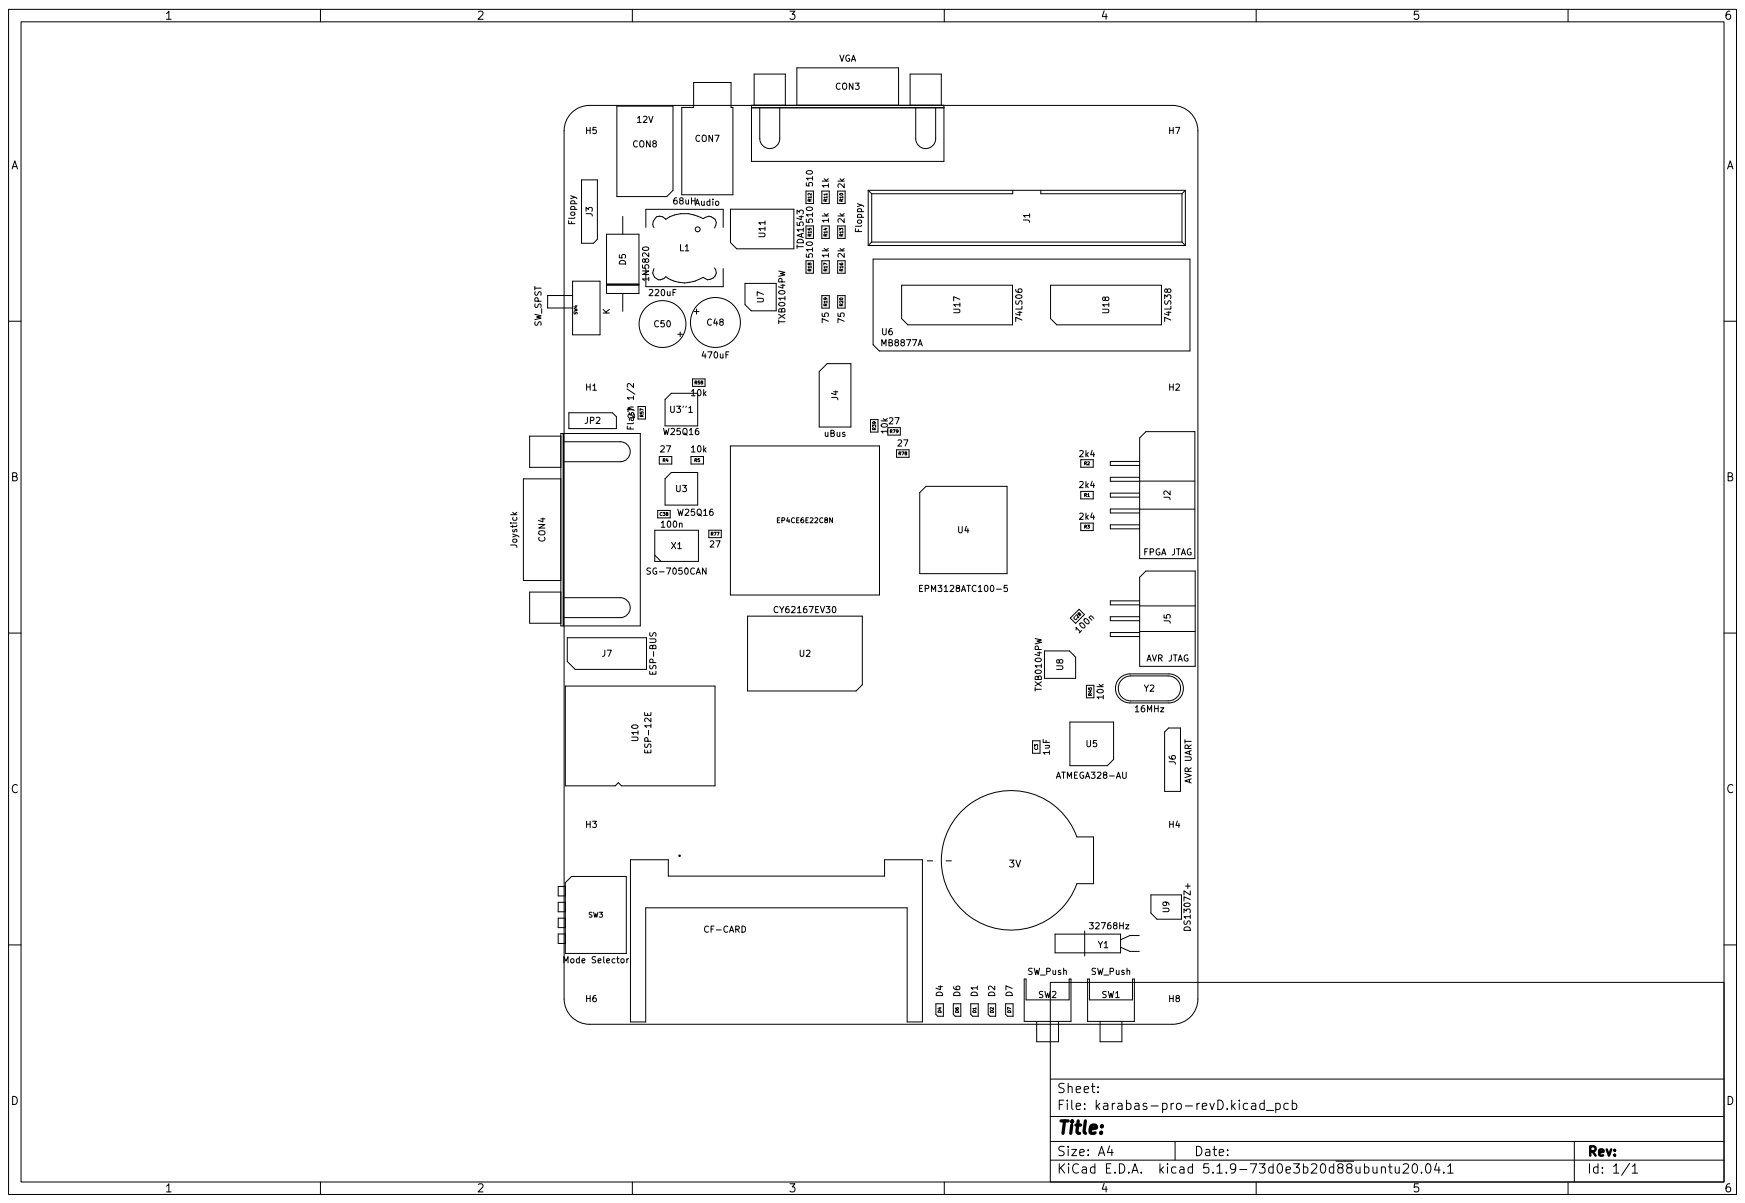
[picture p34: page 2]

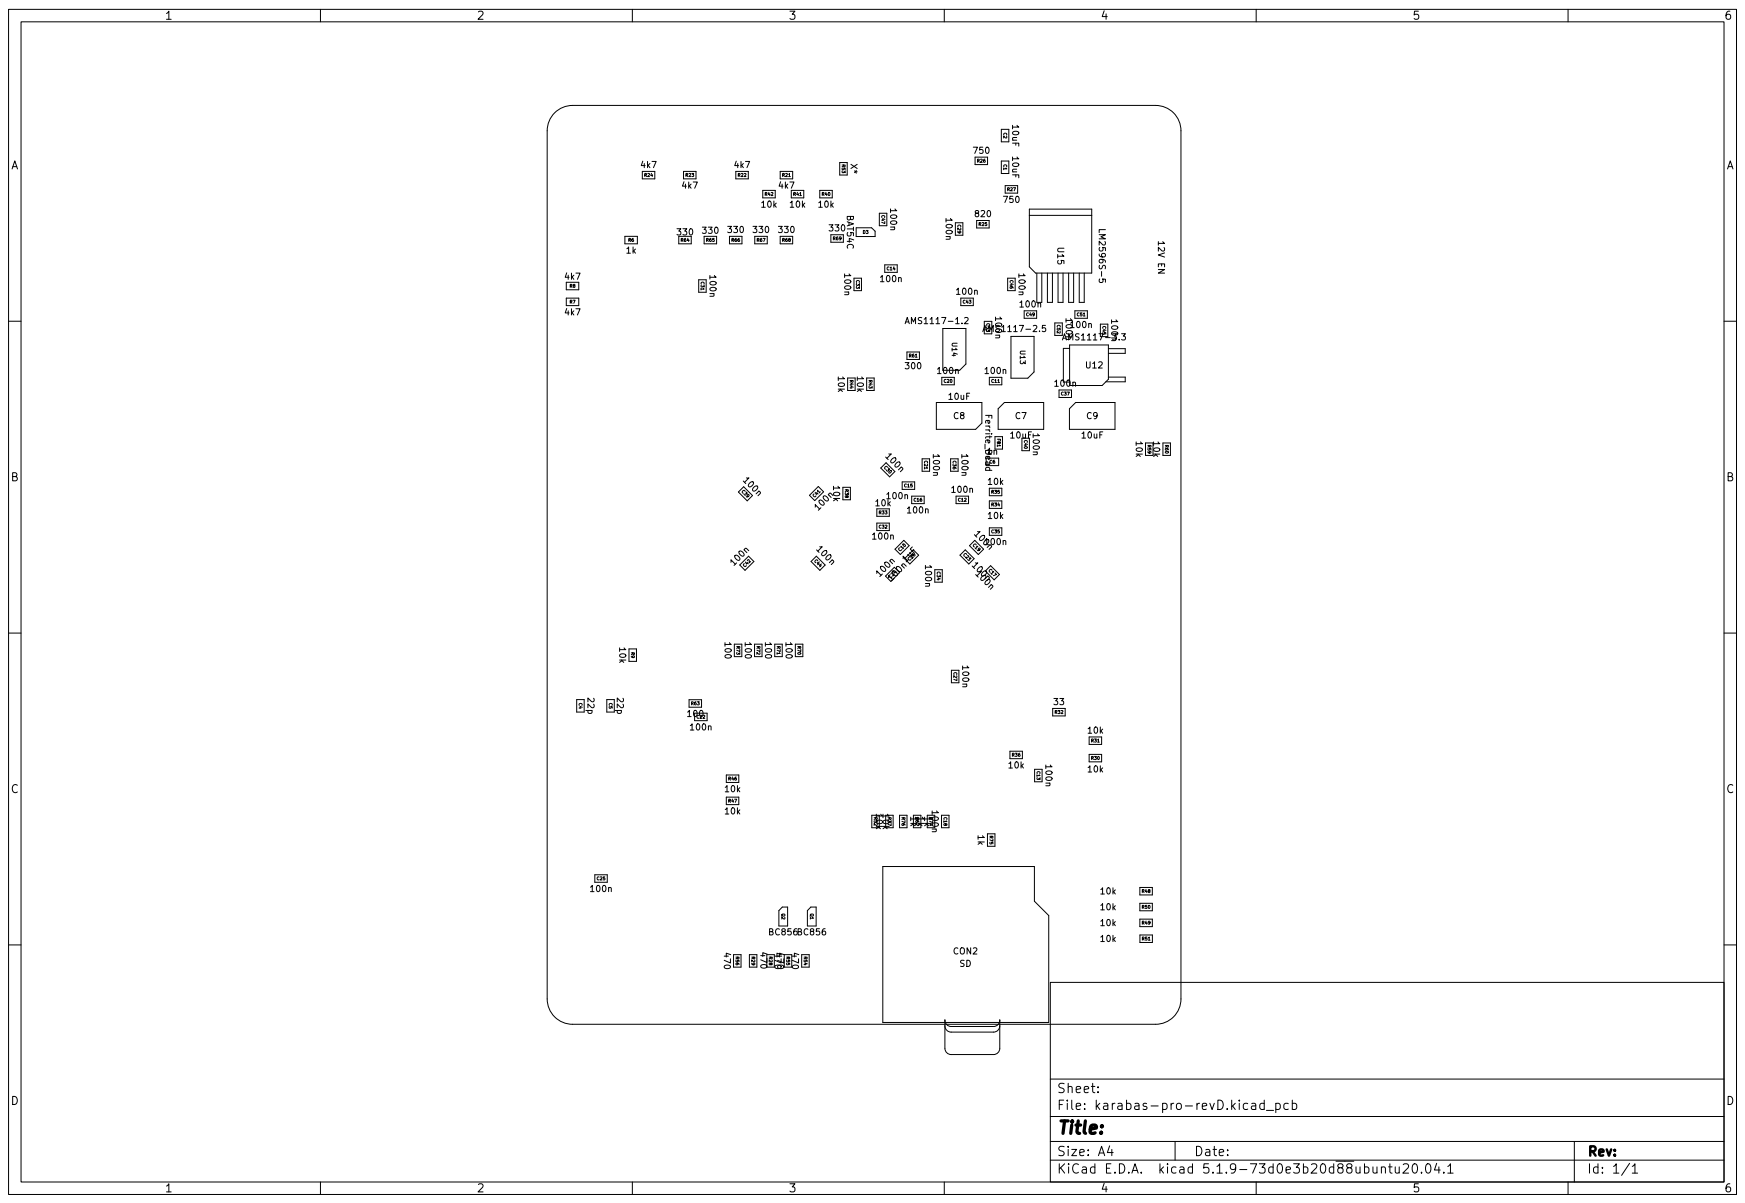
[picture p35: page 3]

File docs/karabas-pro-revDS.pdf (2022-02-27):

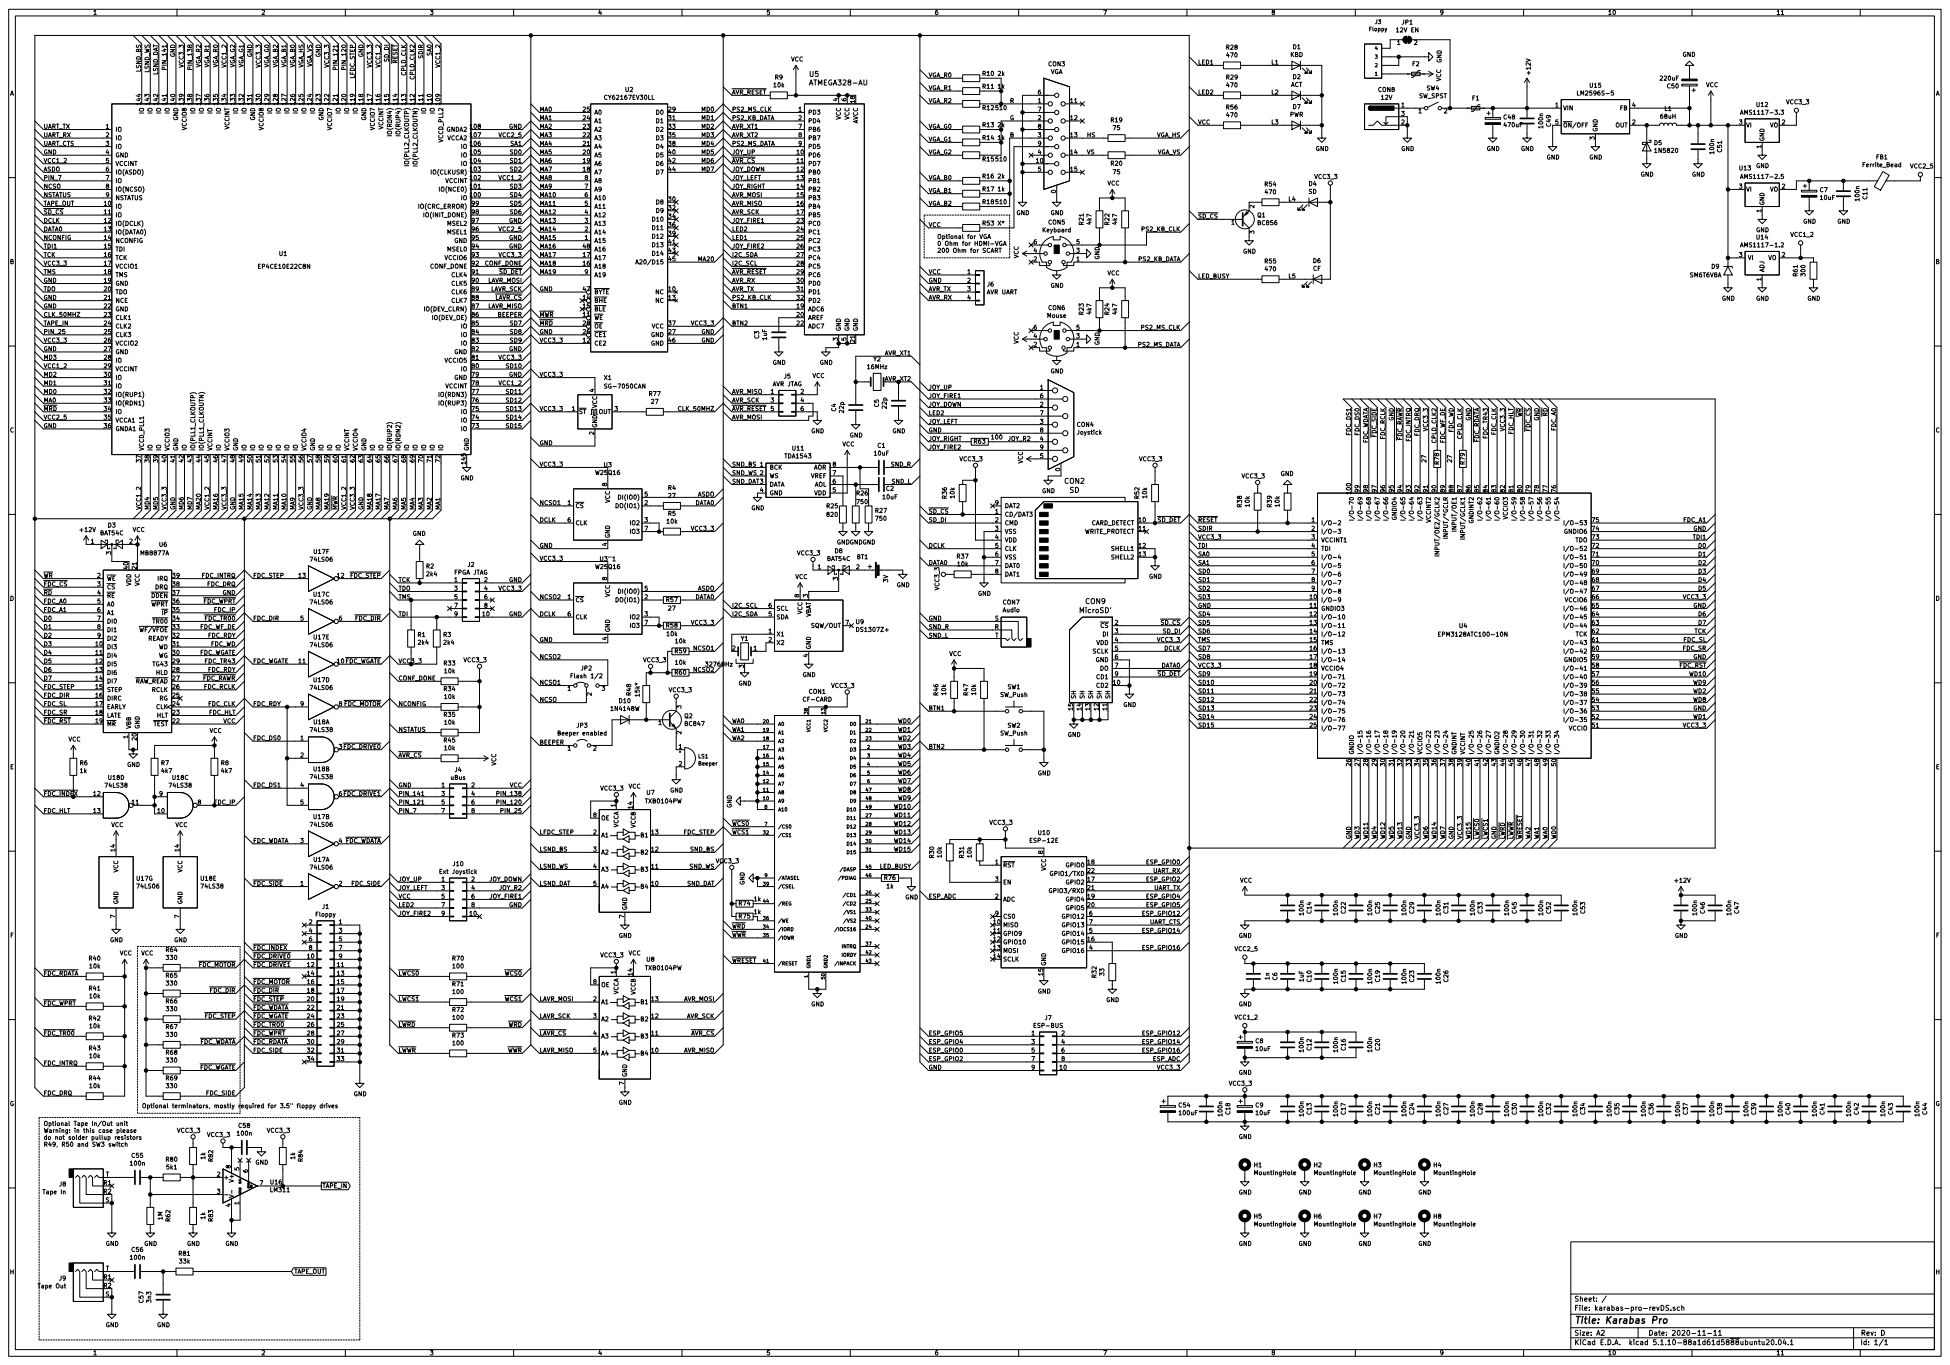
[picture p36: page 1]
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

Optional for VGA
0 Ohm for HDMI-VGA
200 Ohm for SCART

File: karabas-pro-revDS.sch Sheet: / R78 27

IP 35 WPRT 36 DDEN 37 DRQ 38

4 SDA 5 SCL 6 SQW/OUT 7 VCC

H7MountingHole H3MountingHole H2MountingHole VBB
WD9 WD8 WD7 WD6 WD5 WD4 WD3 WD2 WD1 WD0 WRESET WWR Optional terminators, mostly required for 3.5" floppy drives

Optional Tape In/Out unit
Warning: in this case please
do not solder pullup resistors R49, R50 and SW3 switch

Id: 1/1 Title: Karabas Pro

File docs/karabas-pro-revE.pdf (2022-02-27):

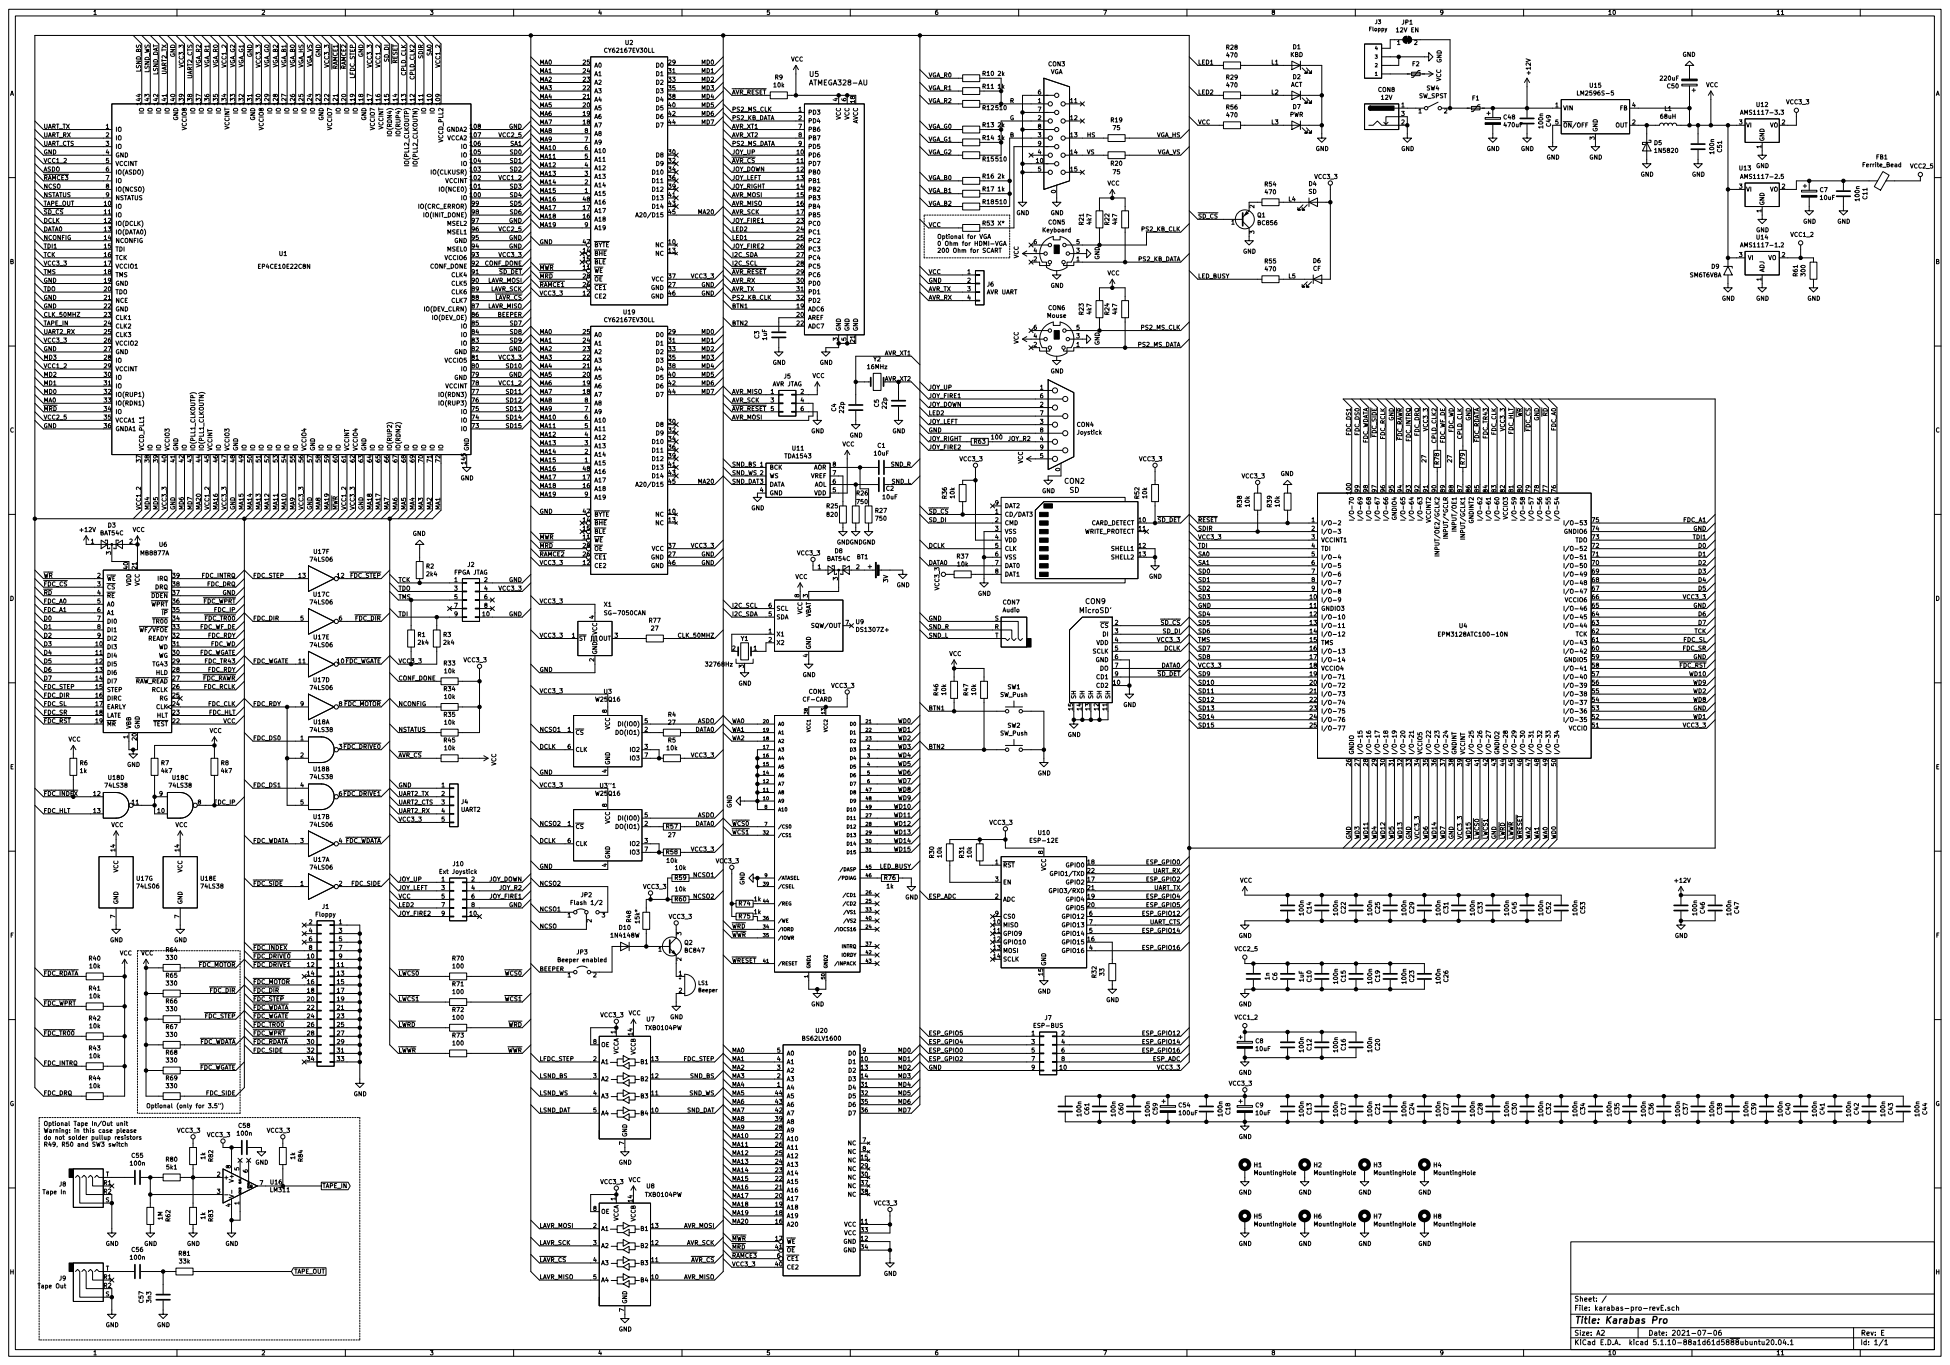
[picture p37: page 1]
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

Optional for VGA
0 Ohm for HDMI-VGA
200 Ohm for SCART

TDI 15 TCK 16 VCCIO1 17 TMS 18 GND 19

2 3 Q2BC847 VCC3_3 GND R48 15k* A15 1 NC 10 WE 11 CE2 12 NC 13 BHE 14 BLE 15 A18 16 A17 17 A7 18 A6 19 A14 2 A5 20 A4 21 A3 22 A2 23 A1 24 A0 25 CE1 26 GND 27 OE 28 D0 29 A13 3 D8 30 D1 31 D9 32 D2 33 D10 34 D3 35 D11 36 VCC 37 D4 38 D12 39 A12 4 D5 40 D13 41 D6 42 D14 43 D7 44 A20/D15 45 GND 46 BYTE 47 A16 48 A11 5 A10 6 A9 7 A8 8 A19 9 U19 CY62167EV30LL

VCC3_3 GND GND MWR MRD

IP 35 WPRT 36 DDEN 37 DRQ 38

4 SDA 5 SCL 6 SQW/OUT 7 VCC

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

Id: 1/1 Title: Karabas Pro

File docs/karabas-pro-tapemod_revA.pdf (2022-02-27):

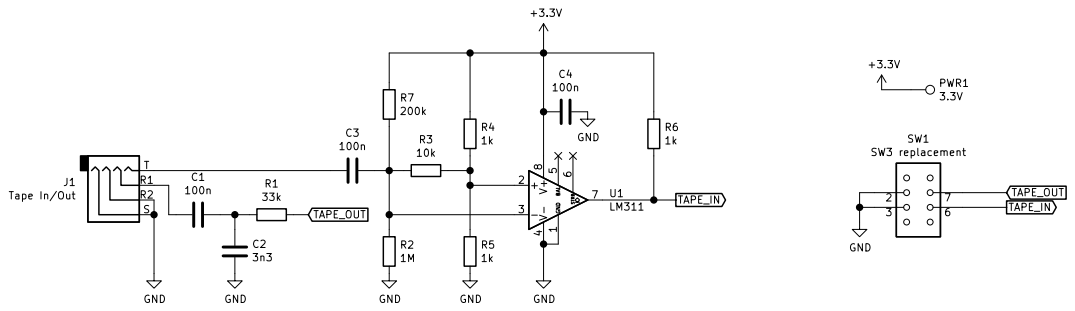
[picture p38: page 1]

File: karabas-pro-tapeMod_revA.sch Sheet: /
Id: 1/1 Title:

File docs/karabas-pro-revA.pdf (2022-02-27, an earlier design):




### karabas-pro-revA

Ref | Q-ty | Value | Footprint
BT1, | 1 3V | | Battery
C10, C11, C12, C13, C14, C15, C16, C17, C18, C19, C20, C21, C22, C23, C24, C25, C26, C27, C28, C29, C30, C31, C32, C33, C34, C35, C36, C37, C38, C39, C40, C41, C42, C43, C44, | 35 100n | | C0805
C1, C2 | 2 10uF | | C0805
C3, | 1 1uF | | C0805
C4, C5, | 2 22p | | C0805
C6, C7, C8, C9, | 4 10uF | | Tantalum D
C45, | 1 470uF | | CP_D12.5mm_P7.50mm
CON1, | 1 CF-CARD | | TE_1734451-1
CON2, | 1 SD | | SD_TE_2041021
CON3, | 1 VGA | | DSUB-15-HD_Female
CON4, | 1 Joystick | | DSUB-9_Male
CON5, | 1 Keyboard | | MDIN06SS
CON6, | 1 Mouse | | MDIN06SS
CON7, | 1 Audio | | Jack_3.5mm_CUI_SJ1-3535NG
CON8, | 1 5V DC | | BarrelJack_Wuerth_6941xx301002
D1, | 1 LED1 | | L0805
D2, | 1 LED2 | | L0805
J1, | 1 Floppy | | IDC-Header_2x17
J2, | 1 FPGA JTAG | | IDC-Header_2x05
J3, | 1 Floppy 5V | | PinHeader_1x04
J4, | 1 uBus | | PinHeader_2x04
J5, | 1 AVR JTAG | | IDC-Header_2x03
J6, | 1 AVR UART | | PinHeader_1x04
R1, R2, R3, | 3 2k4 | | R0805
R4, | 1 27 | | R0805
R5, R9, R30, R31, R32, R33, R34, R35, R36, R37, R38, R39, | 12 10k | | R0805
R6, R11, R14, R17, | 4 1k | | R0805
R7, R8, R21, R22, R23, R24, | 6 4k7 | | R0805
R10, R13, R16, | 3 1k8 | | R0805
R12, R15, R18, R28, R29, | 5 470 | | R0805
R19, R20, | 2 75 | | R0805
R25, | 1 820 | | R0805
R26, R27, | 2 750 | | R0805
SW1, SW2, | 2 SW_Push | | SPST_Angled_PTS645Vx58-2LFS
U1, | 1 EP4CE6E22C8N | | QFP-144
U2, | 1 CY62167EV30 | | TSOP-I-48_18.4x12mm_P0.5mm
U3, | 1 EPCS16 | M25P16 | | SOIC-8_5.23x5.23mm_P1.27mm
U4, | 1 EPM3128ATC100 | | LQFP-100_14x14mm_P0.5mm
U5, | 1 ATMEGA328-AU | | TQFP-32_7x7mm_P0.8mm
U6, | 1 MB8877A | | DIP-40_W15.24mm
U7, U8, | 2 TXB0104PW | | TSSOP-14_4.4x5mm_P0.65mm
U9, | 1 DS1307Z+ | | SOIC-8_3.9x4.9mm_P1.27mm
U10, | 1 ESP-12E | | ESP-12E
U11, | 1 TDA1543 | | DIP-8_W7.62mm
U12, | 1 AMS1117-3.3 | | SOT-223-3
U13, | 1 AMS1117-2.5 | | SOT-223-3

### karabas-pro-revA

U14, | 1 AMS1117-1.2 | SOT-223-3
U17, | 1 74LS06 | DIP-14_W7.62mm
U18, | 1 74LS38 | DIP-14_W7.62mm
X1, | 1 SG-7050CAN | SG8002CA-4Pin_7.0x5.0mm
Y1, | 1 32768Hz | AT310_D3.0mm_L10.0mm
Y2, | 1 16MHz | HC49-S

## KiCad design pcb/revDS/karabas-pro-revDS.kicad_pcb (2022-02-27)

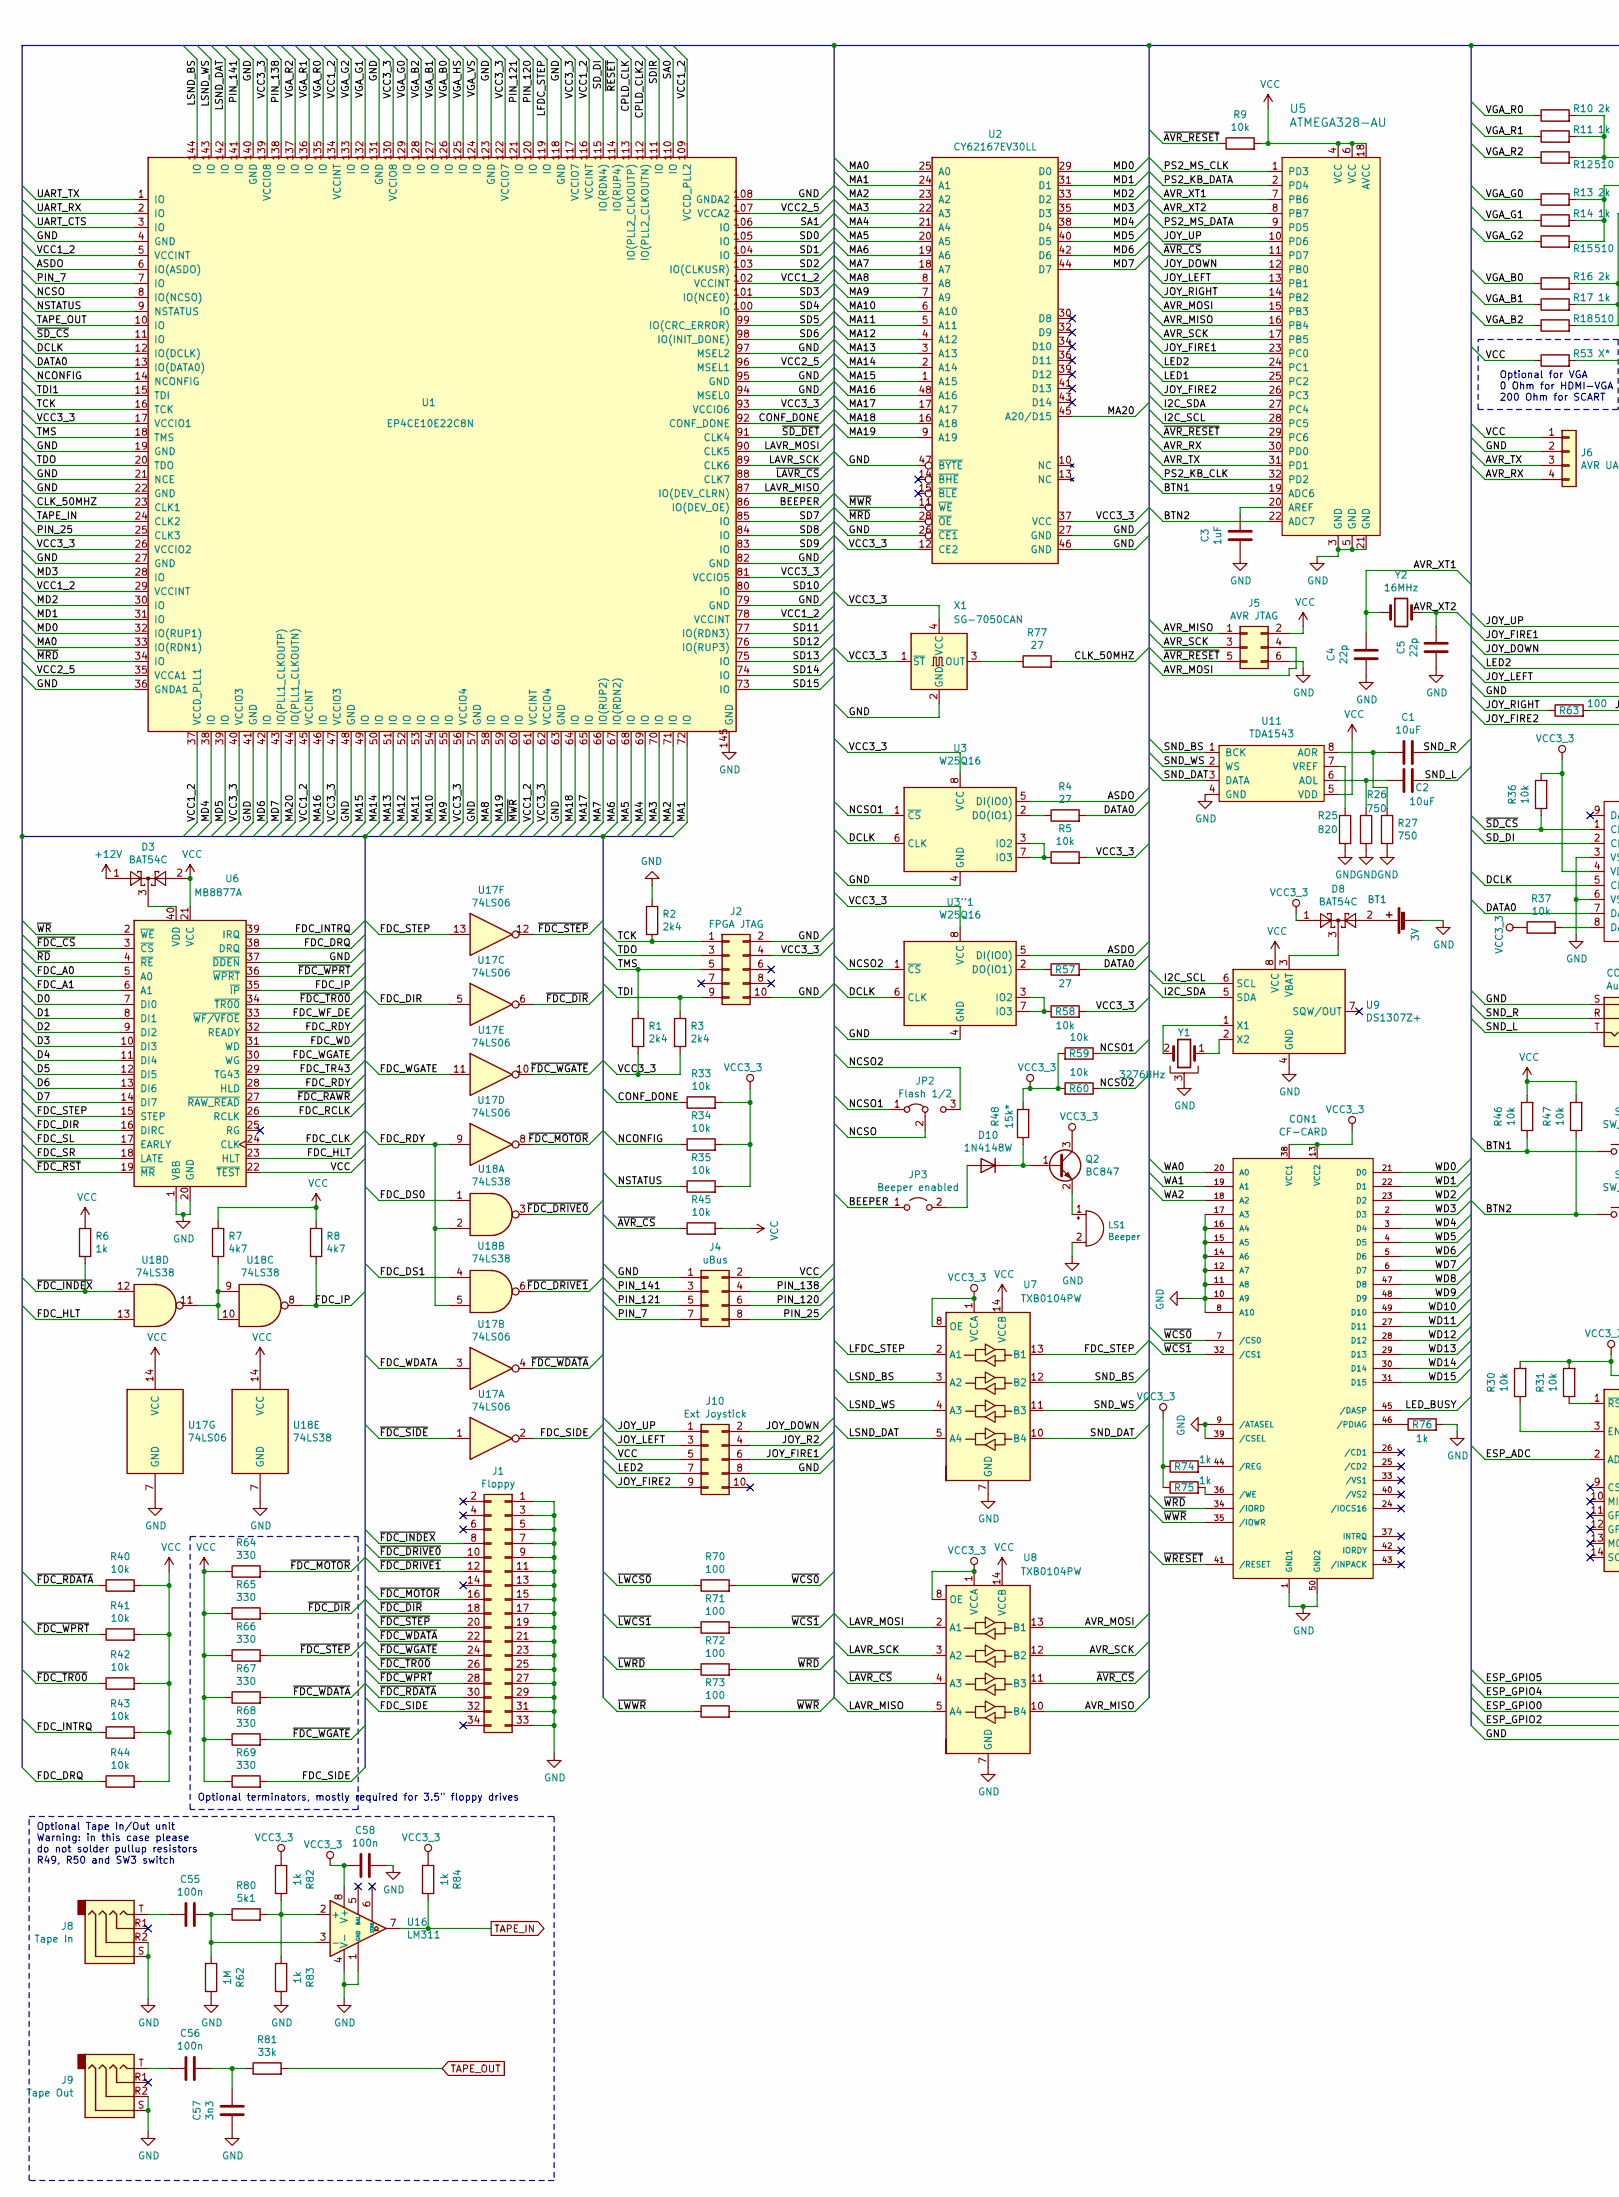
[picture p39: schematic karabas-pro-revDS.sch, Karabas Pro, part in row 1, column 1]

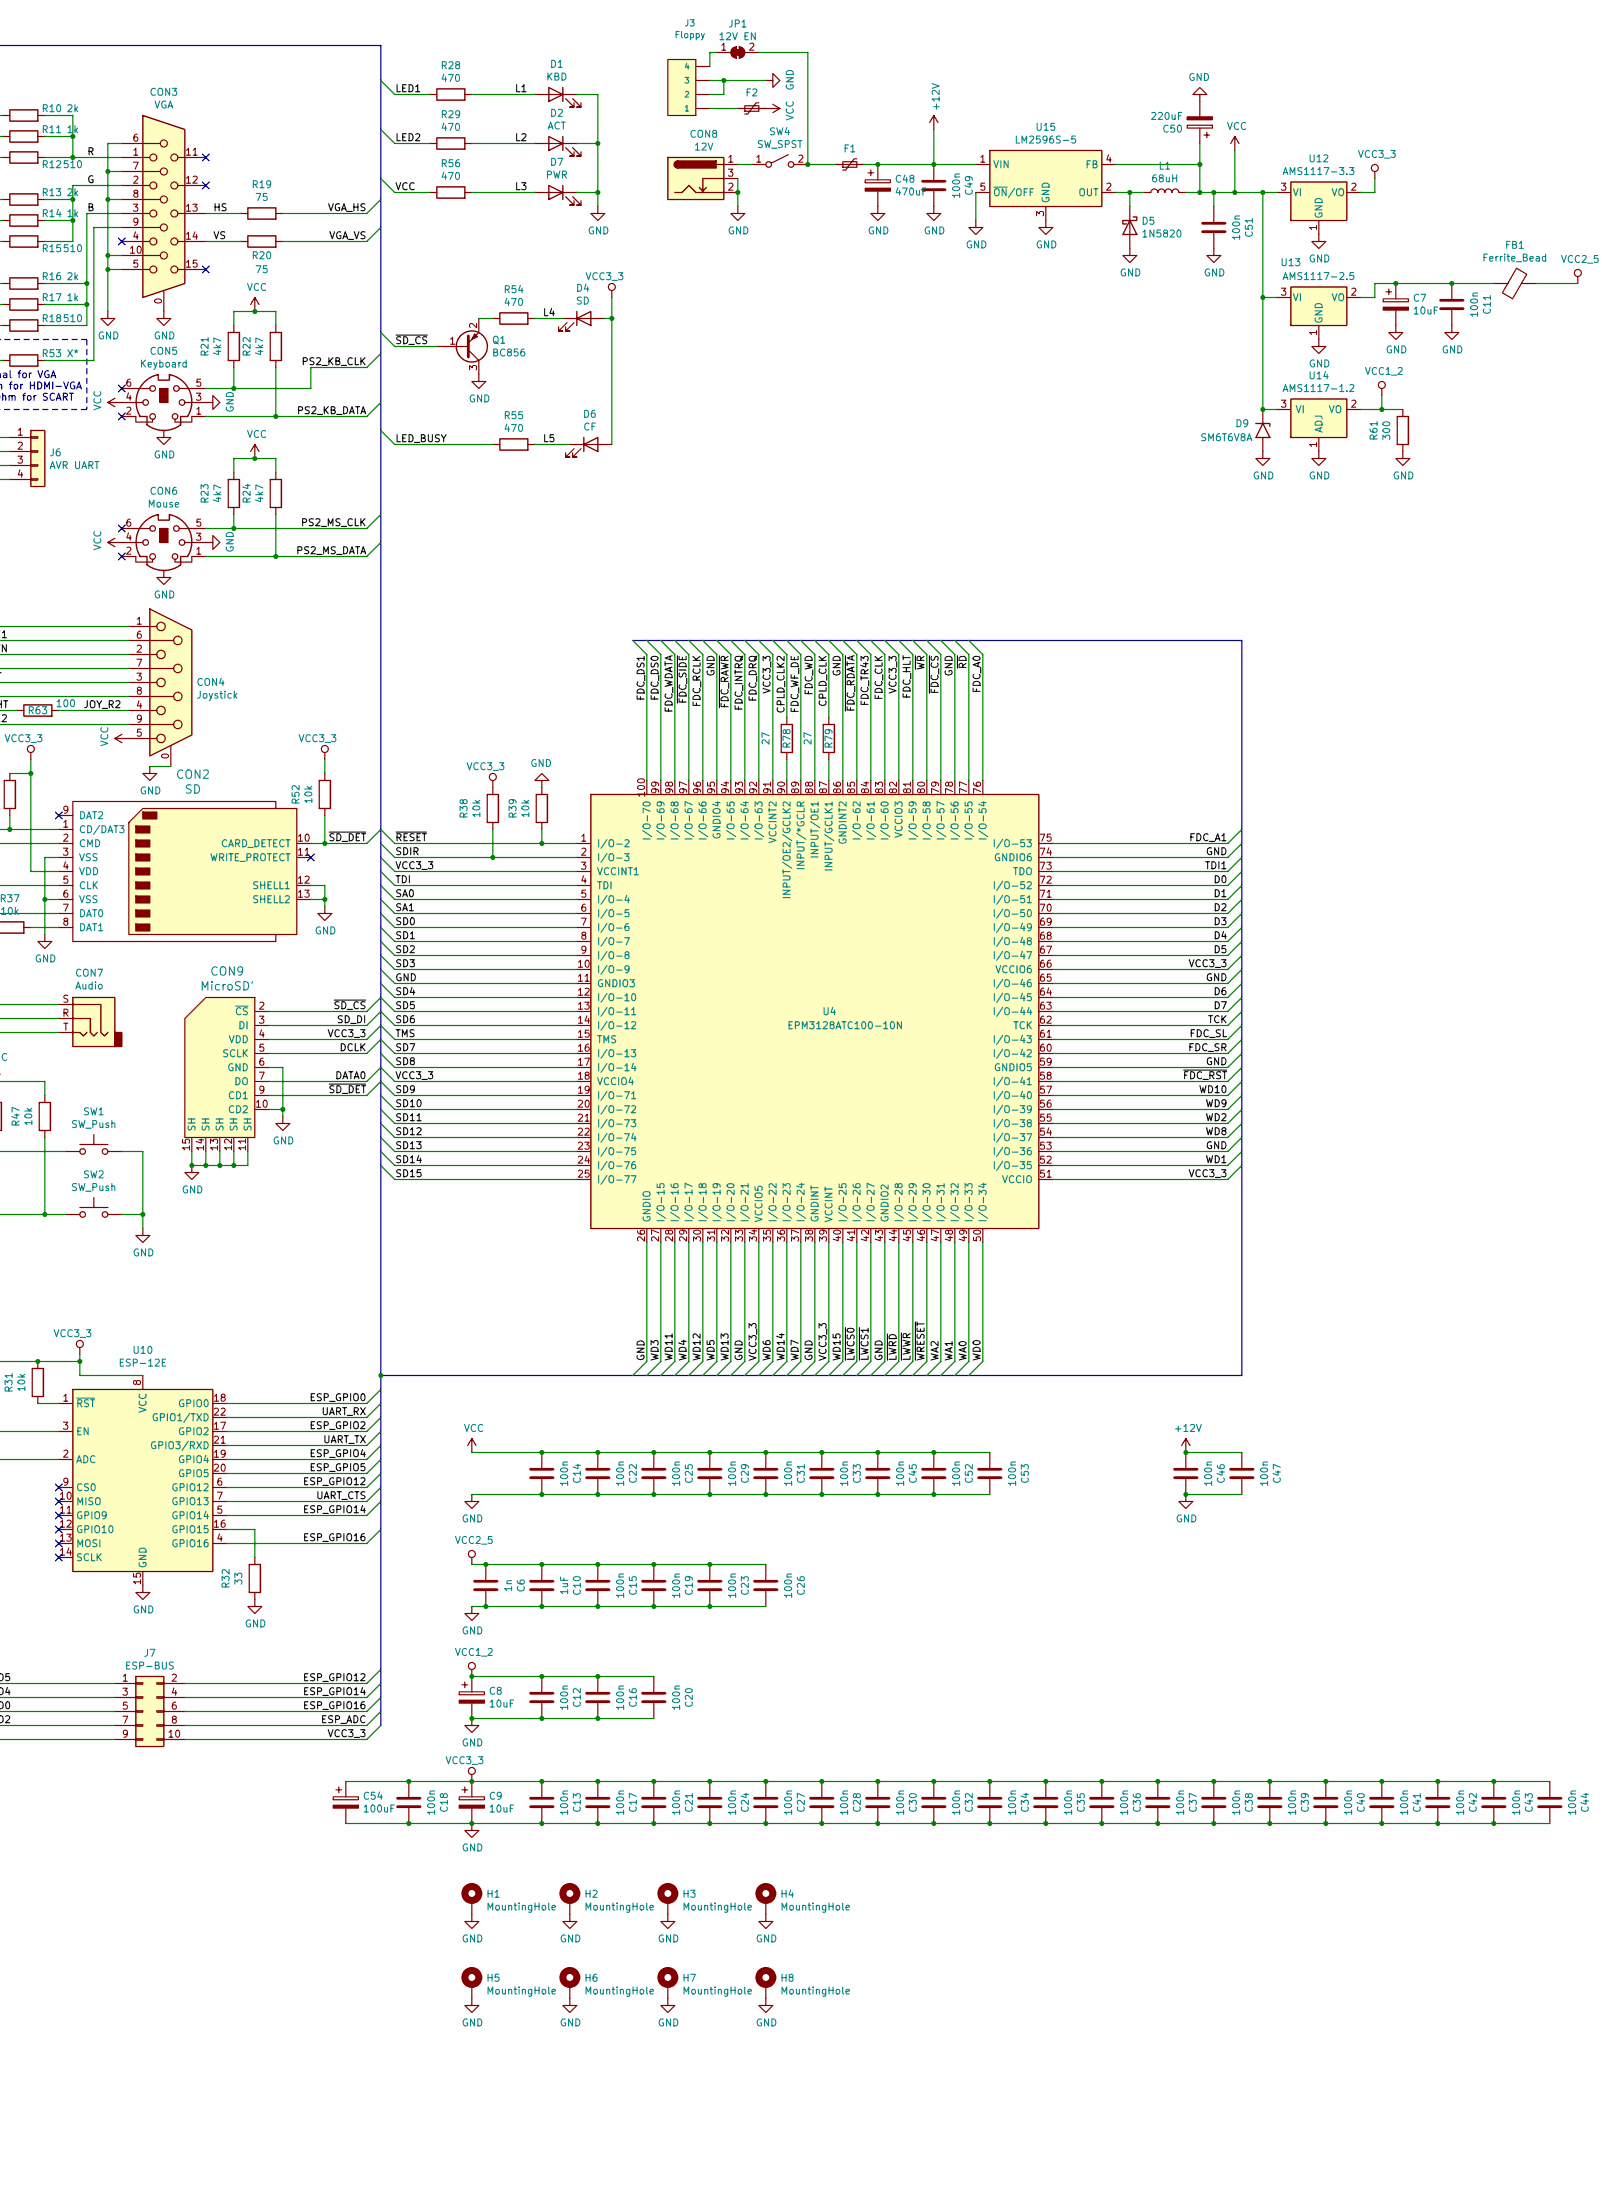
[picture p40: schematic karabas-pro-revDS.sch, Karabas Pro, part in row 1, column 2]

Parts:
BT1: 3V; BAT_BS-7-BLUE
C1, C2: 10uF; C_0805_2012Metric_Pad1.15x1.40mm_HandSolder
C3, C10: 1uF; C_0805_2012Metric_Pad1.15x1.40mm_HandSolder
C4, C5: 22p; C_0805_2012Metric_Pad1.15x1.40mm_HandSolder
C6: 1n; C_0805_2012Metric_Pad1.15x1.40mm_HandSolder
C7, C8, C9: 10uF; CP_EIA-7343-31_Kemet-D-uni
C11, C12, C13, C14, C15, C16, C17, C18, C19, C20, C21, C22, C23, C24, C25, C26, C27, C28, C29, C30, C31, C32, C33, C34, C35, C36, C37, C38, C39, C40, C41, C42, C43, C44, C45, C46, C47, C49, C51, C52, C53: 100n; C_0805_2012Metric_Pad1.15x1.40mm_HandSolder
C48: 470uF; CP_Radial_D8.0mm_P3.80mm
C50: 220uF; CP_Radial_D7.5mm_P2.50mm
C54: 100uF; CP_EIA-7343-31_Kemet-D-uni
C55, C56, C58: 100n; C_0805_2012Metric_Pad1.18x1.45mm_HandSolder
C57: 3n3; C_0805_2012Metric_Pad1.18x1.45mm_HandSolder
CON1: CF-CARD; TE_1734451-1-LONG
CON2: SD; SD_TE_2041021-mod
CON3: VGA; DSUB-15-HD_Female_Horizontal_P2.29x1.98mm_EdgePinOffset3.03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
CON4: Joystick; DSUB-9_Male_Horizontal_P2.77x2.84mm_EdgePinOffset7.70mm_Hou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
CON5: Keyboard; MINI_DIN_6_33PRIMARY
CON6: Mouse; MINI_DIN_6_33PRIMARY
CON7: Audio; Jack_3.5mm_CUI_SJ1-3535NG_Horizontal
CON8: 12V; BarrelJack_Wuerth_6941xx301002
CON9: MicroSD'; MICRO_SD_MOLEX
D1: KBD; LED_0805_2012Metric_Pad1.15x1.40mm_HandSolder
D2: ACT; LED_0805_2012Metric_Pad1.15x1.40mm_HandSolder
D3, D8: BAT54C; SOT-23
D4: SD; LED_0805_2012Metric_Pad1.15x1.40mm_HandSolder
D5: 1N5820; D_DO-201AD_P15.24mm_Horizontal
D6: CF; LED_0805_2012Metric_Pad1.15x1.40mm_HandSolder
D7: PWR; LED_0805_2012Metric_Pad1.15x1.40mm_HandSolder
D9: SM6T6V8A; D_SMB
D10: 1N4148W; D_SOD-123
F1, F2: Polyfuse_Small; Fuse_1812_4532Metric_Castellated
FB1: Ferrite_Bead; L_0805_2012Metric_Pad1.15x1.40mm_HandSolder
H1, H2, H3, H4, H5, H6, H7, H8: MountingHole; MountingHole_3.5mm_Pad_Via
J1: Floppy; IDC-Header_2x17_P2.54mm_Vertical
J2: FPGA JTAG; IDC-Header_2x05_P2.54mm_Horizontal
J3: Floppy; PinHeader_1x04_P2.54mm_Vertical
J4: uBus; PinHeader_2x04_P2.54mm_Vertical
J5: AVR JTAG; IDC-Header_2x03_P2.54mm_Horizontal
J6: AVR UART; PinHeader_1x04_P2.54mm_Vertical
J7: ESP-BUS; PinHeader_2x05_P2.54mm_Vertical
J8: Tape In; AUDIO_JACK_3.5MM_SMD_TRRS
J9: Tape Out; AUDIO_JACK_3.5MM_SMD_TRRS
J10: Ext Joystick; PinHeader_2x05_P2.54mm_Vertical
JP1: 12V EN; SolderJumper-2_P1.3mm_Bridged_Pad1.0x1.5mm
JP2: Flash 1/2; PinHeader_1x03_P2.54mm_Vertical
JP3: Beeper enabled; PinHeader_1x02_P2.54mm_Vertical
L1: 68uH; L_12x12mm_H6mm
LS1: Beeper; Buzzer_12x9.5RM7.6
Q1: BC856; SOT-23
Q2: BC847; SOT-23
R1, R2, R3: 2k4; R_0805_2012Metric_Pad1.15x1.40mm_HandSolder
R4, R57, R77, R78, R79: 27; R_0805_2012Metric_Pad1.15x1.40mm_HandSolder
R5, R9, R30, R31, R33, R34, R35, R36, R37, R38, R39, R40, R41, R42, R43, R44, R45, R46, R47, R52, R58, R59, R60: 10k; R_0805_2012Metric_Pad1.15x1.40mm_HandSolder
R6, R11, R14, R17, R74, R75, R76: 1k; R_0805_2012Metric_Pad1.15x1.40mm_HandSolder
R7, R8, R21, R22, R23, R24: 4k7; R_0805_2012Metric_Pad1.15x1.40mm_HandSolder
R10, R13, R16: 2k; R_0805_2012Metric_Pad1.15x1.40mm_HandSolder
R12, R15, R18: 510; R_0805_2012Metric_Pad1.15x1.40mm_HandSolder
R19, R20: 75; R_0805_2012Metric_Pad1.15x1.40mm_HandSolder
R25: 820; R_0805_2012Metric_Pad1.15x1.40mm_HandSolder
R26, R27: 750; R_0805_2012Metric_Pad1.15x1.40mm_HandSolder
R28, R29, R54, R55, R56: 470; R_0805_2012Metric_Pad1.15x1.40mm_HandSolder
R32: 33; R_0805_2012Metric_Pad1.15x1.40mm_HandSolder
R48: 15k*; R_0805_2012Metric_Pad1.20x1.40mm_HandSolder
R53: X*; R_0805_2012Metric_Pad1.15x1.40mm_HandSolder
R61: 300; R_0805_2012Metric_Pad1.15x1.40mm_HandSolder
R62: 1M; R_0805_2012Metric_Pad1.20x1.40mm_HandSolder
R63, R70, R71, R72, R73: 100; R_0805_2012Metric_Pad1.15x1.40mm_HandSolder
R64, R65, R66, R67, R68, R69: 330; R_0805_2012Metric_Pad1.15x1.40mm_HandSolder
R80: 5k1; R_0805_2012Metric_Pad1.20x1.40mm_HandSolder
R81: 33k; R_0805_2012Metric_Pad1.20x1.40mm_HandSolder
R82, R83, R84: 1k; R_0805_2012Metric_Pad1.20x1.40mm_HandSolder
SW1, SW2: SW_Push; SW_Tactile_SPST_Angled_PTS645Vx58-2LFS
SW4: SW_SPST; SW_CuK_OS102011MA1QN1_SPDT_Angled
U1: EP4CE10E22C8N; ALTERA-QFP-145
U2: CY62167EV30LL; TSOP-I-48_18.4x12mm_P0.5mm
U3, U3''1: W25Q16; SOIC-8_5.23x5.23mm_P1.27mm-LONG
U4: EPM3128ATC100-10N; LQFP-100_14x14mm_P0.5mm
U5: ATMEGA328-AU; TQFP-32_7x7mm_P0.8mm; MPN ATMEGA328-AU; Digi-Key_PN ATMEGA328-AU-ND
U6: MB8877A; DIP-40_W15.24mm
U7, U8: TXB0104PW; TSSOP-14_4.4x5mm_P0.65mm
U9: DS1307Z+; SOIC-8_3.9x4.9mm_P1.27mm
U10: ESP-12E
U11: TDA1543; DIP-8_W7.62mm
U12: AMS1117-3.3; TO-252-2
U13: AMS1117-2.5; SOT-223-3_TabPin2
U14: AMS1117-1.2; SOT-223-3_TabPin2
U15: LM2596S-5; TO-263-5_TabPin3
U16: LM311; SO-8_3.9x4.9mm_P1.27mm
U17: 74LS06; DIP-14_W7.62mm
U18: 74LS38; DIP-14_W7.62mm
X1: SG-7050CAN; Oscillator_SMD_SeikoEpson_SG8002CA-4Pin_7.0x5.0mm
Y1: 32768Hz; Crystal_AT310_D3.0mm_L10.0mm_Horizontal_1EP_style2
Y2: 16MHz; Crystal_HC49-U_Vertical

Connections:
+12V: C46.1, C47.1, C48.1, C49.1, D3.1, F1.2, U15.1 (VIN)
/ASDO: U1.6 (IO(ASDO)), U3.5 (DI(IO0)), U3''1.5 (DI(IO0))
/AVR_MISO: J5.1, U5.16 (PB4), U8.10 (B4)
/AVR_MOSI: J5.4, U5.15 (PB3), U8.13 (B1)
/AVR_RX: J6.4, U5.30 (PD0)
/AVR_SCK: J5.3, U5.17 (PB5), U8.12 (B2)
/AVR_TX: J6.3, U5.31 (PD1)
/AVR_XT1: C4.2, U5.7 (PB6), Y2.1
/AVR_XT2: C5.2, U5.8 (PB7), Y2.2
/B: CON3.3, R16.2, R17.2, R18.2
/BEEPER: JP3.1 (A), U1.86 (IO(DEV_OE))
/BTN1: R46.1, SW1.1, U5.19 (ADC6)
/BTN2: R47.1, SW2.1, U5.22 (ADC7)
/CLK_50MHZ: R77.2, U1.23 (CLK1)
/CONF_DONE: R33.1, U1.92 (CONF_DONE)
/CPLD_CLK: R79.2, U1.113 (IO(PLL2_CLKOUTP))
/CPLD_CLK2: R78.2, U1.112 (IO(PLL2_CLKOUTN))
/D0: U4.72 (I/O-52), U6.7 (DI0)
/D1: U4.71 (I/O-51), U6.8 (DI1)
/D2: U4.70 (I/O-50), U6.9 (DI2)
/D3: U4.69 (I/O-49), U6.10 (DI3)
/D4: U4.68 (I/O-48), U6.11 (DI4)
/D5: U4.67 (I/O-47), U6.12 (DI5)
/D6: U4.64 (I/O-45), U6.13 (DI6)
/D7: U4.63 (I/O-44), U6.14 (DI7)
/DATA0: CON2.7 (DAT0), CON9.7 (DO), R4.2, R57.2, U1.13 (IO(DATA0))
/DCLK: CON2.5 (CLK), CON9.5 (SCLK), U1.12 (IO(DCLK)), U3.6 (CLK), U3''1.6 (CLK)
/ESP_ADC: J7.8, U10.2 (ADC)
/ESP_GPIO0: J7.5, U10.18 (GPIO0)
/ESP_GPIO2: J7.7, U10.17 (GPIO2)
/ESP_GPIO4: J7.3, U10.19 (GPIO4)
/ESP_GPIO5: J7.1, U10.20 (GPIO5)
/ESP_GPIO12: J7.2, U10.6 (GPIO12)
/ESP_GPIO14: J7.4, U10.5 (GPIO14)
/ESP_GPIO16: J7.6, U10.4 (GPIO16)
/FDC_A0: U4.76 (I/O-54), U6.5 (A0)
/FDC_A1: U4.75 (I/O-53), U6.6 (A1)
/FDC_CLK: U4.83 (I/O-60), U6.24 (CLK)
/FDC_DIR: U6.16 (DIRC), U17.5
/FDC_DRQ: R44.1, U4.92 (I/O-63), U6.38 (DRQ)
/FDC_DS0: U4.99 (I/O-69), U18.1
/FDC_DS1: U4.100 (I/O-70), U18.4
/FDC_HLT: U4.81 (I/O-59), U6.23 (HLT), U18.13
/FDC_INTRQ: R43.1, U4.93 (I/O-64), U6.39 (IRQ)
/FDC_IP: R8.2, U6.35 (~IP), U18.8
/FDC_RCLK: U4.96 (I/O-66), U6.26 (RCLK)
/FDC_RDY: U6.28 (HLD), U6.32 (READY), U17.9, U18.2, U18.5
/FDC_SIDE: J1.32, R69.2, U17.2
/FDC_SL: U4.61 (I/O-43), U6.17 (EARLY)
/FDC_SR: U4.60 (I/O-42), U6.18 (LATE)
/FDC_STEP: U6.15 (STEP), U7.13 (B1), U17.13
/FDC_TR43: U4.84 (I/O-61), U6.29 (TG43)
/FDC_WD: U4.88 (INPUT/OE1), U6.31 (WD)
/FDC_WDATA: U4.98 (I/O-68), U17.3
/FDC_WF_DE: U4.89 (INPUT/*GCLR), U6.33 (~WF/VFOE~)
/FDC_WGATE: U6.30 (WG), U17.11
/G: CON3.2, R13.2, R14.2, R15.2
/HS: CON3.13, R19.1
/I2C_SCL: U5.28 (PC5), U9.6 (SCL)
/I2C_SDA: U5.27 (PC4), U9.5 (SDA)
/JOY_DOWN: CON4.2, J10.2, U5.12 (PB0)
/JOY_FIRE1: CON4.6, J10.6, U5.23 (PC0)
/JOY_FIRE2: CON4.9, J10.9, U5.26 (PC3)
/JOY_LEFT: CON4.3, J10.3, U5.13 (PB1)
/JOY_R2: CON4.4, J10.4, R63.2
/JOY_RIGHT: R63.1, U5.14 (PB2)
/JOY_UP: CON4.1, J10.1, U5.10 (PD6)
/L1: D1.2 (A), R28.2
/L2: D2.2 (A), R29.2
/L3: D7.2 (A), R56.2
/L4: D4.1 (K), R54.2
/L5: D6.1 (K), R55.2
/LAVR_MISO: U1.87 (IO(DEV_CLRN)), U8.5 (A4)
/LAVR_MOSI: U1.90 (CLK5), U8.2 (A1)
/LAVR_SCK: U1.89 (CLK6), U8.3 (A2)
/LED1: R28.1, U5.25 (PC2)
/LED2: CON4.7, J10.7, R29.1, U5.24 (PC1)
/LED_BUSY: CON1.45 (/DASP), R55.1
/LFDC_STEP: U1.119 (IO), U7.2 (A1)
/LSND_BS: U1.144 (IO), U7.3 (A2)
/LSND_DAT: U1.142 (IO), U7.5 (A4)
/LSND_WS: U1.143 (IO), U7.4 (A3)
/MA0: U1.33 (IO(RDN1)), U2.25 (A0)
/MA1: U1.72 (IO), U2.24 (A1)
/MA2: U1.71 (IO), U2.23 (A2)
/MA3: U1.70 (IO), U2.22 (A3)
/MA4: U1.69 (IO), U2.21 (A4)
/MA5: U1.68 (IO), U2.20 (A5)
/MA6: U1.67 (IO(RDN2)), U2.19 (A6)
/MA7: U1.66 (IO(RUP2)), U2.18 (A7)
/MA8: U1.58 (IO), U2.8 (A8)
/MA9: U1.55 (IO), U2.7 (A9)
/MA10: U1.54 (IO), U2.6 (A10)
/MA11: U1.53 (IO), U2.5 (A11)
/MA12: U1.52 (IO), U2.4 (A12)
/MA13: U1.51 (IO), U2.3 (A13)
/MA14: U1.50 (IO), U2.2 (A14)
/MA15: U1.49 (IO), U2.1 (A15)
/MA16: U1.46 (IO), U2.48 (A16)
/MA17: U1.65 (IO), U2.17 (A17)
/MA18: U1.64 (IO), U2.16 (A18)
/MA19: U1.59 (IO), U2.9 (A19)
/MA20: U1.44 (IO(PLL1_CLKOUTN)), U2.45 (A20/D15)
/MD0: U1.32 (IO(RUP1)), U2.29 (D0)
/MD1: U1.31 (IO), U2.31 (D1)
/MD2: U1.30 (IO), U2.33 (D2)
/MD3: U1.28 (IO), U2.35 (D3)
/MD4: U1.38 (IO), U2.38 (D4)
/MD5: U1.39 (IO), U2.40 (D5)
/MD6: U1.42 (IO), U2.42 (D6)
/MD7: U1.43 (IO(PLL1_CLKOUTP)), U2.44 (D7)
/NCONFIG: R34.1, U1.14 (NCONFIG)
/NCSO: JP2.2 (C), U1.8 (IO(NCSO))
/NCSO1: JP2.1 (A), R59.1, U3.1 (~CS)
/NCSO2: JP2.3 (B), R60.1, U3''1.1 (~CS)
/NSTATUS: R35.1, U1.9 (NSTATUS)
/PIN_7: J4.7, U1.7 (IO)
/PIN_25: J4.8, U1.25 (CLK3)
/PIN_120: J4.6, U1.120 (IO)
/PIN_121: J4.5, U1.121 (IO)
/PIN_138: J4.4, U1.138 (IO)
/PIN_141: J4.3, U1.141 (IO)
/PS2_KB_CLK: CON5.5, R21.1, U5.32 (PD2)
/PS2_KB_DATA: CON5.1, R22.1, U5.2 (PD4)
/PS2_MS_CLK: CON6.5, R23.1, U5.1 (PD3)
/PS2_MS_DATA: CON6.1, R24.1, U5.9 (PD5)
/R: CON3.1, R10.2, R11.2, R12.2
/SA0: U1.110 (IO), U4.5 (I/O-4)
/SA1: U1.106 (IO), U4.6 (I/O-5)
/SD0: U1.105 (IO), U4.7 (I/O-6)
/SD1: U1.104 (IO), U4.8 (I/O-7)
/SD2: U1.103 (IO(CLKUSR)), U4.9 (I/O-8)
/SD3: U1.101 (IO(NCE0)), U4.10 (I/O-9)
/SD4: U1.100 (IO), U4.12 (I/O-10)
/SD5: U1.99 (IO(CRC_ERROR)), U4.13 (I/O-11)
/SD6: U1.98 (IO(INIT_DONE)), U4.14 (I/O-12)
/SD7: U1.85 (IO), U4.16 (I/O-13)
/SD8: U1.84 (IO), U4.17 (I/O-14)
/SD9: U1.83 (IO), U4.19 (I/O-71)
/SD10: U1.80 (IO), U4.20 (I/O-72)
/SD11: U1.77 (IO(RDN3)), U4.21 (I/O-73)
/SD12: U1.76 (IO(RUP3)), U4.22 (I/O-74)
/SD13: U1.75 (IO), U4.23 (I/O-75)
/SD14: U1.74 (IO), U4.24 (I/O-76)
/SD15: U1.73 (IO), U4.25 (I/O-77)
/SDIR: R38.1, U1.111 (IO), U4.2 (I/O-3)
/SD_DI: CON2.2 (CMD), CON9.3 (DI), U1.115 (IO(RDN4))
/SND_BS: U7.12 (B2), U11.1 (BCK)
/SND_DAT: U7.10 (B4), U11.3 (DATA)
/SND_L: C2.2, CON7.T
/SND_R: C1.2, CON7.R
/SND_WS: U7.11 (B3), U11.2 (WS)
/TCK: J2.1, R2.2, U1.16 (TCK), U4.62 (TCK)
/TDI: J2.9, R3.1, U4.4 (TDI)
/TDI1: U1.15 (TDI), U4.73 (TDO)
/TDO: J2.3, U1.20 (TDO)
/TMS: J2.5, R1.1, U1.18 (TMS), U4.15 (TMS)
/UART_CTS: U1.3 (IO), U10.7 (GPIO13)
/UART_RX: U1.2 (IO), U10.22 (GPIO1/TXD)
/UART_TX: U1.1 (IO), U10.21 (GPIO3/RXD)
/VGA_B0: R16.1, U1.126 (IO)
/VGA_B1: R17.1, U1.127 (IO)
/VGA_B2: R18.1, U1.128 (IO)
/VGA_G0: R13.1, U1.129 (IO)
/VGA_G1: R14.1, U1.132 (IO)
/VGA_G2: R15.1, U1.133 (IO)
/VGA_HS: R19.2, U1.125 (IO)
/VGA_R0: R10.1, U1.135 (IO)
/VGA_R1: R11.1, U1.136 (IO)
/VGA_R2: R12.1, U1.137 (IO)
/VGA_VS: R20.2, U1.124 (IO)
/VS: CON3.14, R20.1
/WA0: CON1.20 (A0), U4.49 (I/O-33)
/WA1: CON1.19 (A1), U4.48 (I/O-32)
/WA2: CON1.18 (A2), U4.47 (I/O-31)
/WD0: CON1.21 (D0), U4.50 (I/O-34)
/WD1: CON1.22 (D1), U4.52 (I/O-35)
/WD2: CON1.23 (D2), U4.55 (I/O-38)
/WD3: CON1.2 (D3), U4.27 (I/O-15)
/WD4: CON1.3 (D4), U4.29 (I/O-17)
/WD5: CON1.4 (D5), U4.31 (I/O-19)
/WD6: CON1.5 (D6), U4.35 (I/O-22)
/WD7: CON1.6 (D7), U4.37 (I/O-24)
/WD8: CON1.47 (D8), U4.54 (I/O-37)
/WD9: CON1.48 (D9), U4.56 (I/O-39)
/WD10: CON1.49 (D10), U4.57 (I/O-40)
/WD11: CON1.27 (D11), U4.28 (I/O-16)
/WD12: CON1.28 (D12), U4.30 (I/O-18)
/WD13: CON1.29 (D13), U4.32 (I/O-20)
/WD14: CON1.30 (D14), U4.36 (I/O-23)
/WD15: CON1.31 (D15), U4.40 (I/O-25)
/~AVR_CS: R45.1, U5.11 (PD7), U8.11 (B3)
/~AVR_RESET: J5.5, R9.1, U5.29 (PC6)
/~FDC_CS: U4.79 (I/O-57), U6.3 (~CS)
/~FDC_DIR: J1.18, R65.2, U17.6
/~FDC_DRIVE0: J1.10, U18.3
/~FDC_DRIVE1: J1.12, U18.6
/~FDC_INDEX: J1.8, R6.2, U18.12
/~FDC_MOTOR: J1.16, R64.2, U17.8
/~FDC_RAWR: U4.94 (I/O-65), U6.27 (~RAW_READ)
/~FDC_RDATA: J1.30, R40.1, U4.85 (I/O-62)
/~FDC_RST: U4.58 (I/O-41), U6.19 (~MR)
/~FDC_SIDE: U4.97 (I/O-67), U17.1
/~FDC_STEP: J1.20, R66.2, U17.12
/~FDC_TR00: J1.26, R42.1, U6.34 (~TR00)
/~FDC_WDATA: J1.22, R67.2, U17.4
/~FDC_WGATE: J1.24, R68.2, U17.10
/~FDC_WPRT: J1.28, R41.1, U6.36 (~WPRT)
/~LAVR_CS: U1.88 (CLK7), U8.4 (A3)
/~LWCS0: R70.1, U4.41 (I/O-26)
/~LWCS1: R71.1, U4.42 (I/O-27)
/~LWRD: R72.1, U4.44 (I/O-28)
/~LWWR: R73.1, U4.45 (I/O-29)
/~MRD: U1.34 (IO), U2.28 (~OE)
/~MWR: U1.60 (IO), U2.11 (~WE)
/~RD: U4.77 (I/O-55), U6.4 (~RE)
/~RESET: R39.1, U1.114 (IO(RUP4)), U4.1 (I/O-2)
/~SD_CS: CON2.1 (CD/DAT3), CON9.2 (~CS), Q1.1 (B), R36.1, U1.11 (IO)
/~SD_DET: CON2.10 (CARD_DETECT), CON9.9 (CD1), R52.1, U1.91 (CLK4)
/~WCS0: CON1.7 (/CS0), R70.2
/~WCS1: CON1.32 (/CS1), R71.2
/~WR: U4.80 (I/O-58), U6.2 (~WE)
/~WRD: CON1.34 (/IORD), R72.2
/~WRESET: CON1.41 (/RESET), U4.46 (I/O-30)
/~WWR: CON1.35 (/IOWR), R73.2
GND: BT1.2 (-), C3.1, C4.1, C5.1, C6.2, C7.2, C8.2, C9.2, C10.2, C11.2, C12.2, C13.2, C14.2, C15.2, C16.2, C17.2, C18.2, C19.2, C20.2, C21.2, C22.2, C23.2, C24.2, C25.2, C26.2, C27.2, C28.2, C29.2, C30.2, C31.2, C32.2, C33.2, C34.2, C35.2, C36.2, C37.2, C38.2, C39.2, C40.2, C41.2, C42.2, C43.2, C44.2, C45.2, C46.2, C47.2, C48.2, C49.2, C50.2, C51.2, C52.2, C53.2, C54.2, C57.1, C58.2, CON1.1 (GND1), CON1.8 (A10), CON1.9 (/ATASEL), CON1.10 (A9), CON1.11 (A8), CON1.12 (A7), CON1.14 (A6), CON1.15 (A5), CON1.16 (A4), CON1.17 (A3), CON1.39 (/CSEL), CON1.50 (GND2), CON2.3 (VSS), CON2.6 (VSS), CON2.12 (SHELL1), CON2.13 (SHELL2), CON3.0, CON3.5, CON3.6, CON3.7, CON3.8, CON3.10, CON4.0 (PAD), CON4.8, CON5.3, CON5.GND, CON6.3, CON6.GND, CON7.S, CON8.2, CON8.3, CON9.6 (GND), CON9.10 (CD2), CON9.11 (SH), CON9.12 (SH), CON9.13 (SH), CON9.14 (SH), CON9.15 (SH), D1.1 (K), D2.1 (K), D5.2 (A), D7.1 (K), D9.2 (A2), H1.1, H2.1, H3.1, H4.1, H5.1, H6.1, H7.1, H8.1, J1.1, J1.3, J1.5, J1.7, J1.9, J1.11, J1.13, J1.15, J1.17, J1.19, J1.21, J1.23, J1.25, J1.27, J1.29, J1.31, J1.33, J2.2, J2.10, J3.2, J3.3, J4.1, J5.6, J6.2, J7.9, J8.R2, J8.S, J9.R2, J9.S, J10.8, LS1.2 (+), Q1.3 (C), R2.1, R25.2, R26.2, R27.2, R32.1, R39.2, R61.1, R62.2, R76.2, R83.2, SW1.2, SW2.2, U1.4 (GND), U1.19 (GND), U1.21 (NCE), U1.22 (GND), U1.27 (GND), U1.36 (GNDA1), U1.41 (GND), U1.48 (GND), U1.57 (GND), U1.63 (GND), U1.79 (GND), U1.82 (GND), U1.94 (MSEL0), U1.95 (GND), U1.97 (MSEL2), U1.108 (GNDA2), U1.118 (GND), U1.123 (GND), U1.131 (GND), U1.140 (GND), U1.145 (GND), U2.26 (~CE1), U2.27 (GND), U2.46 (GND), U2.47 (~BYTE), U3.4 (GND), U3''1.4 (GND), U4.11 (GNDIO3), U4.26 (GNDIO), U4.33 (I/O-21), U4.38 (GNDINT), U4.43 (GNDIO2), U4.53 (I/O-36), U4.59 (GNDIO5), U4.65 (I/O-46), U4.74 (GNDIO6), U4.78 (I/O-56), U4.86 (GNDINT2), U4.95 (GNDIO4), U5.3 (GND), U5.5 (GND), U5.21 (GND), U6.1 (VBB), U6.20 (GND), U6.37 (~DDEN), U7.7 (GND), U8.7 (GND), U9.4 (GND), U10.15 (GND), U11.4 (GND), U12.1 (GND), U13.1 (GND), U14.1 (ADJ), U15.3 (GND), U15.5 (~ON~/OFF), U16.1 (GND), U16.4 (V-), U17.7 (GND), U18.7 (GND), X1.2 (GND), Y1.3
unnamed: BT1.1 (+), D8.2
unnamed: C1.1, R27.1, U11.8 (AOR)
unnamed: C2.1, R26.1, U11.6 (AOL)
unnamed: C3.2, U5.20 (AREF)
unnamed: C7.1, C11.1, FB1.1, U13.2 (VO)
unnamed: C55.1, J8.T
unnamed: C55.2, R62.1, R80.1, U16.3 (-)
unnamed: C56.1, J9.T
unnamed: C56.2, C57.2, R81.1
unnamed: CON1.36 (/WE), R75.2
unnamed: CON1.44 (/REG), R74.2
unnamed: CON1.46 (/PDIAG), R76.1
unnamed: CON2.8 (DAT1), R37.2
unnamed: CON3.9, R53.2
unnamed: CON8.1, SW4.1 (A)
unnamed: D3.3, U6.40 (VDD)
unnamed: D5.1 (K), L1.1, U15.2 (OUT)
unnamed: D8.3, U9.3 (VBAT)
unnamed: D10.1 (K), Q2.1 (B), R48.1
unnamed: D10.2 (A), JP3.2 (B)
unnamed: F1.1, JP1.2 (B), SW4.2 (B)
unnamed: F2.1, J3.1
unnamed: J3.4, JP1.1 (A)
unnamed: LS1.1 (-), Q2.2 (E)
unnamed: Q1.2 (E), R54.1
unnamed: R4.1, U3.2 (DO(IO1))
unnamed: R5.1, U3.3 (IO2), U3.7 (IO3)
unnamed: R7.2, U18.9, U18.10, U18.11
unnamed: R25.1, U11.7 (VREF)
unnamed: R30.1, U10.3 (EN)
unnamed: R31.1, U10.1 (~RST)
unnamed: R32.2, U10.16 (GPIO15)
unnamed: R57.1, U3''1.2 (DO(IO1))
unnamed: R58.1, U3''1.3 (IO2), U3''1.7 (IO3)
unnamed: R77.1, X1.3 (OUT)
unnamed: R78.1, U4.90 (INPUT/OE2/GCLK2)
unnamed: R79.1, U4.87 (INPUT/GCLK1)
unnamed: R80.2, R82.2, R83.1, U16.2 (+)
unnamed: U9.1 (X1), Y1.2
unnamed: U9.2 (X2), Y1.1
TAPE_IN: R84.2, U1.24 (CLK2), U16.7
TAPE_OUT: R81.2, U1.10 (IO)
VCC: C14.1, C22.1, C25.1, C29.1, C31.1, C33.1, C45.1, C50.1, C51.1, C52.1, C53.1, CON4.5, CON5.4, CON6.4, D3.2, D9.1 (A1), F2.2, J4.2, J5.2, J6.1, J10.5, L1.2, R6.1, R7.1, R8.1, R9.2, R21.2, R22.2, R23.2, R24.2, R40.2, R41.2, R42.2, R43.2, R44.2, R45.2, R46.2, R47.2, R53.1, R56.1, R64.1, R65.1, R66.1, R67.1, R68.1, R69.1, U5.4 (VCC), U5.6 (VCC), U5.18 (AVCC), U6.21 (VCC), U6.22 (~TEST), U7.14 (VCCB), U8.14 (VCCB), U9.8 (VCC), U11.5 (VDD), U12.3 (VI), U13.3 (VI), U14.3 (VI), U15.4 (FB), U17.14 (VCC), U18.14 (VCC)
VCC1_2: C8.1, C12.1, C16.1, C20.1, R61.2, U1.5 (VCCINT), U1.29 (VCCINT), U1.37 (VCCD_PLL1), U1.45 (VCCINT), U1.61 (VCCINT), U1.78 (VCCINT), U1.102 (VCCINT), U1.109 (VCCD_PLL2), U1.116 (VCCINT), U1.134 (VCCINT), U14.2 (VO)
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

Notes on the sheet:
Optional for VGA 0 Ohm for HDMI-VGA 200 Ohm for SCART
Optional Tape In/Out unit Warning: in this case please do not solder pullup resistors R49, R50 and SW3 switch
Optional terminators, mostly required for 3.5" floppy drives

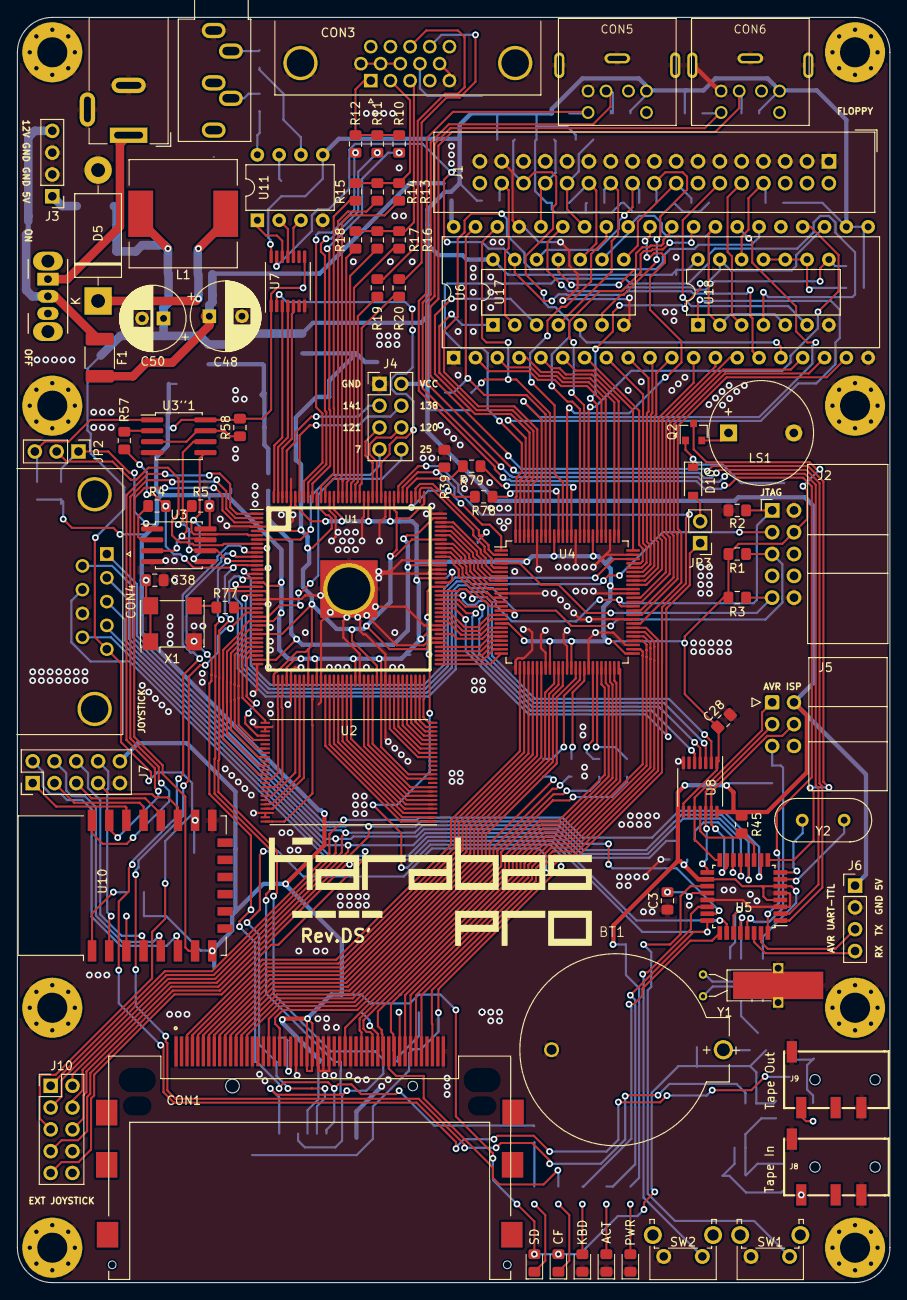
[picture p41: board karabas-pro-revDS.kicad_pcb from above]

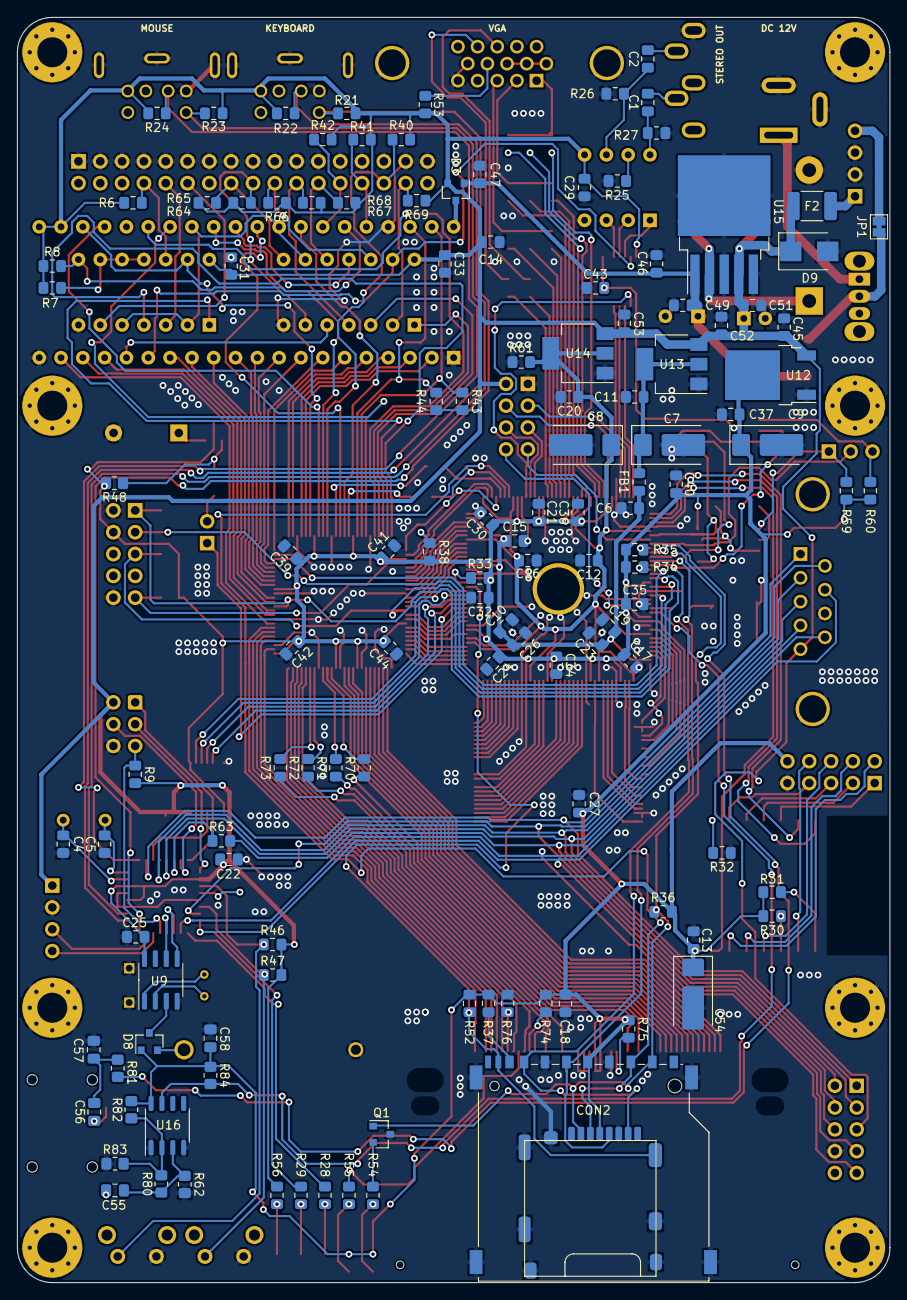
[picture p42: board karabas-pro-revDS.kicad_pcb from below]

Board: 2 copper layers, 101.6 x 147.3 mm, 212 parts (126 on the bottom side), 272 nets.

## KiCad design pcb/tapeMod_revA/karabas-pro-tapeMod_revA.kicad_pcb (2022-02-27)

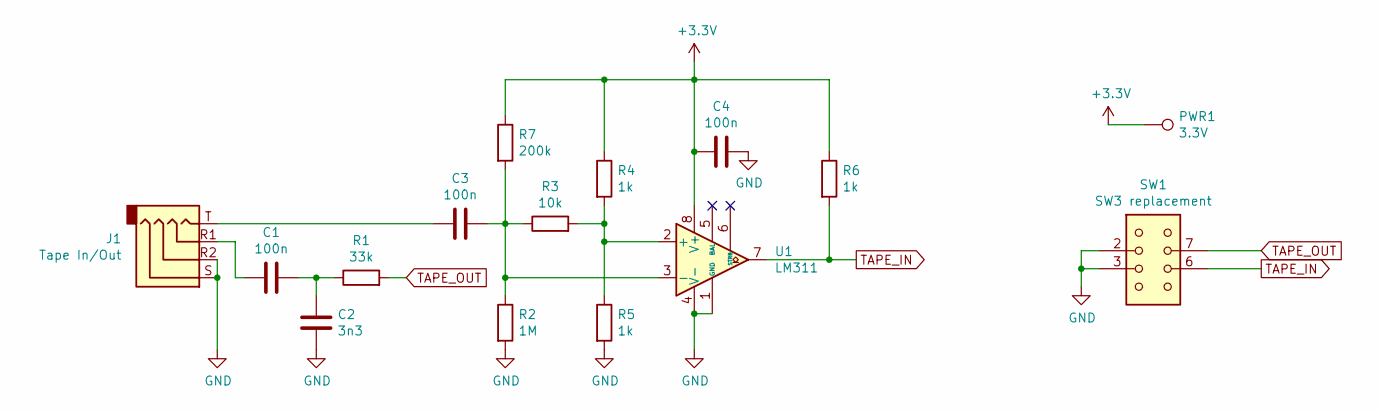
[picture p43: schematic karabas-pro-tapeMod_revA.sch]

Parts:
C1, C3, C4: 100n; C_0805_2012Metric_Pad1.18x1.45mm_HandSolder
C2: 3n3; C_0805_2012Metric_Pad1.18x1.45mm_HandSolder
J1: Tape In/Out; AUDIO_JACK_3.5MM_SMD_TRRS
PWR1: 3.3V; TestPoint_Pad_2.0x2.0mm
R1: 33k; R_0805_2012Metric_Pad1.20x1.40mm_HandSolder
R2: 1M; R_0805_2012Metric_Pad1.20x1.40mm_HandSolder
R3: 10k; R_0805_2012Metric_Pad1.20x1.40mm_HandSolder
R4, R5, R6: 1k; R_0805_2012Metric_Pad1.20x1.40mm_HandSolder
R7: 200k; R_0805_2012Metric_Pad1.20x1.40mm_HandSolder
SW1: SW3 replacement; SW_DIP_SPSTx04_Piano_TAPE_MOD
U1: LM311; SO-8_3.9x4.9mm_P1.27mm

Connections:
+3V3: C4.1, PWR1.1, R4.1, R6.1, R7.1, U1.8 (V+); also elsewhere on the board
GND: C2.1, C4.2, J1.R2, J1.S, R2.2, R5.2, SW1.2, SW1.3, U1.1 (GND), U1.4 (V-)
unnamed: C1.1, J1.R1
unnamed: C1.2, C2.2, R1.1
unnamed: C3.1, J1.T
unnamed: C3.2, R2.1, R3.1, R7.2, U1.3 (-)
unnamed: R3.2, R4.2, R5.1, U1.2 (+)
TAPE_IN: R6.2, SW1.6, U1.7
TAPE_OUT: R1.2, SW1.7

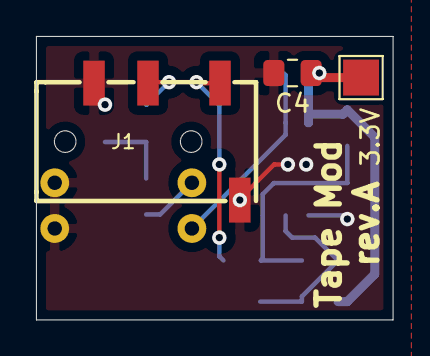
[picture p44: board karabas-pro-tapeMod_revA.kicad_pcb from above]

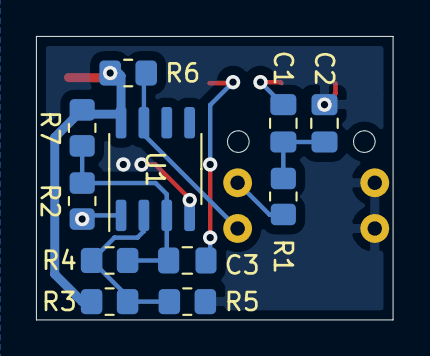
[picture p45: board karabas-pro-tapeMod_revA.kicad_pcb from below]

Board: 2 copper layers, 19.8 x 15.7 mm, 15 parts (11 on the bottom side), 9 nets.

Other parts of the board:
3.3V: 3.3V; TestPoint_Pad_2.0x2.0mm

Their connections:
+3V3: 3.3V.1; also elsewhere on the board

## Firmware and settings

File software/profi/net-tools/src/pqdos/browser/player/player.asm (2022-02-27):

;Universal PT2'n'PT3 Turbo Sound player for ZX Spectrum
;(c)2004-2007 S.V.Bulba <vorobey@mail.khstu.ru>
;Specially for AlCo
;http://bulba.untergrund.net/ (http://bulba.at.kz/)
	MODULE VTPL
;Release number
Release EQU "0"
;Conditional assembly
;1) Current position counters at (Vars1+0) and (Vars2+0)
CurPosCounter=0
;2) Allow channels allocation bits at (START+10)
ACBBAC=0
;3) Allow loop checking and disabling
LoopChecker=1
;4) Insert official identificator
Id=0
;5) Set IY for correct return to ZX Basic
Basic=1

;Features
;--------
;-Can be compiled at any address (i.e. no need rounding ORG
; address).
;-Variables (VARS) can be located at any address (not only after
; code block).
;-INIT subprogram checks PT3-module version and rightly
; generates both note and volume tables outside of code block
; (in VARS).
;-Two portamento (spc. command 3xxx) algorithms (depending of
; PT3 module version).
;-New 1.XX and 2.XX special command behaviour (only for PT v3.7
; and higher).
;-Any Tempo value are accepted (including Tempo=1 and Tempo=2).
;-TS modes: 2xPT3, 2xPT2 and PT v3.7 TS standard.
;-Fully compatible with Ay_Emul PT3 and PT2 players codes.
;-See also notes at the end of this source code.

;Limitations
;-----------
;-Can run in RAM only (self-modified code is used).
;-PT2 position list must be end by #FF marker only.

;Warning!!! PLAY subprogram can crash if no module are loaded
;into RAM or INIT subprogram was not called before.

;Call MUTE or INIT one more time to mute sound after stopping
;playing 

;Test codes (commented)
;	LD A,32 ;SinglePT3(TS if TSPT3.7),ABC,Looped
;	LD (START+10),A
;	LD HL,#8000 ;Mod1
;	LD DE,#A000 ;Mod2 (optional)
;	CALL START+3
;	EI
;_LP	HALT
;	CALL START+5
;	XOR A
;	IN A,(#FE)
;	CPL
;	AND 15
;	JR Z,_LP
;	JR START+8

TonA	EQU 0
TonB	EQU 2
TonC	EQU 4
Noise	EQU 6
Mixer	EQU 7
AmplA	EQU 8
AmplB	EQU 9
AmplC	EQU 10
Env	EQU 11
EnvTp	EQU 13

;Entry and other points
;START initialize playing of modules at MDLADDR (single module)
;START+3 initialization with module address in HL and DE (TS)
;START+5 play one quark
;START+8 mute
;START+10 setup and status flags

START:
	LD HL,outputBuffer ;DE - address of 2nd module for TS
	JR INIT
	JP PLAY
	JR MUTE
SETUP	DB 0 ;set bit0, if you want to play without looping
	     ;(optional);
	     ;set bit1 for PT2 and reset for PT3 before
	     ;calling INIT;
	     ;bits2-3: %00-ABC, %01-ACB, %10-BAC (optional);
	     ;bits4-5: %00-no TS, %01-2 modules TS, %10-
	     ;autodetect PT3 TS-format by AlCo (PT 3.7+);
	     ;Remark: old PT3 TS-format by AlCo (PT 3.6) is not
	     ;documented and must be converted to new standard.
	     ;bit6 is set each time, when loop point of 2nd TS
	     ;module is passed (optional).
	     ;bit7 is set each time, when loop point of 1st TS
	     ;or of single module is passed (optional).

;Identifier
	IF Id
	DB "=UniPT2/PT3/TS-Player r.",Release,"="
	ENDIF

	IF LoopChecker
CHECKLP	LD HL,SETUP
	BIT 0,(IY-100+VRS.ModNum)
	JR Z,CHL1
	SET 6,(HL)
	JR CHL2
CHL1	SET 7,(HL)
CHL2	BIT 0,(HL)
	RET Z
	POP HL
	INC (IY-100+VRS.DelyCnt)
	INC (IY-100+VRS.ChanA+CHP.NtSkCn)
	XOR A
	LD (IY-100+VRS.AYREGS+AmplA),A
	LD (IY-100+VRS.AYREGS+AmplB),A
	LD (IY-100+VRS.AYREGS+AmplC),A
	RET
	ENDIF

MUTE: XOR A
	LD H,A
	LD L,A
	LD (VARS1+VRS.AYREGS+AmplA),A
	LD (VARS1+VRS.AYREGS+AmplB),HL
	LD (VARS2+VRS.AYREGS+AmplA),A
	LD (VARS2+VRS.AYREGS+AmplB),HL
	JP ROUT

INIT:
;HL - AddressOfModule
;DE - AddresOf2ndModule
	PUSH DE
	PUSH HL
	LD HL,VARS
	LD (HL),0
	LD DE,VARS+1
	LD BC,VAR0END-VARS-1
	LDIR
	INC HL
	LD (VARS1+VRS.AdInPtA),HL ;ptr to zero
	LD (VARS2+VRS.AdInPtA),HL

	POP HL
	LD IY,VARS1+100
	LD A,(START+10)
	AND 2
	JP NZ,I_PT2

	CALL INITPT3
	LD HL,(e_-SamCnv-2)*256+#18
	LD (SamCnv),HL
	LD A,#BA
	LD (OrnCP),A
	LD (SamCP),A
	LD A,#7B
	LD (OrnLD),A
	LD (SamLD),A
	LD A,#87
	LD (SamClc2),A
	POP HL
	;Use version and ton table of 1st module
	LD A,(IX+13-100) ;EXTRACT VERSION NUMBER
	SUB #30
	JR C,L20
	CP 10
	JR C,L21
L20	LD A,6
L21	LD (Version),A
	PUSH AF ;VolTable version
	CP 4
	LD A,(IX+99-100) ;TONE TABLE NUMBER
	RLA
	AND 7
	PUSH AF ;NoteTable number

	LD IY,VARS2+100
	LD A,(START+10)
	AND 48
	JR Z,NOTS
	CP 16
	JR Z,TwoPT3s
	LD A,(Version)
	CP 7
	JR C,NOTS
	LD A,(IX+98-100) ;ALCO TS MARKER
	CP #20
	JR Z,NOTS
	LD HL,VARS1
	LD DE,VARS2
	LD BC,VRS
	LDIR
	SET 1,(IY-100+VRS.ModNum)
	LD C,A
	ADD A,A
	ADD A,C
	SUB 2
	LD (TSSub),A
	JR AlCoTS_
TwoPT3s	CALL INITPT3
AlCoTS_	LD A,1
	LD (is_ts),A
	SET 0,(IY-100+VRS.ModNum)

NOTS	LD BC,PT3PD
	LD HL,0
	LD DE,PT3EMPTYORN
	JR INITCOMMON

I_PT2	CALL INITPT2
	LD HL,#51CB
	LD (SamCnv),HL
	LD A,#BB
	LD (OrnCP),A
	LD (SamCP),A
	LD A,#7A
	LD (OrnLD),A
	LD (SamLD),A
	LD A,#80
	LD (SamClc2),A
	POP HL
	LD A,5
	LD (Version),A
	PUSH AF
	LD A,2
	PUSH AF

	LD A,(START+10)
	AND 48
	JR Z,NOTS2

	LD IY,VARS2+100
	LD A,1
	LD (is_ts),A
	SET 0,(IY-100+VRS.ModNum)
	CALL INITPT2

NOTS2	LD BC,PT2PD
	LD HL,#8687
	LD DE,PT2EMPTYORN

INITCOMMON

	IF Basic
	LD IY,#5C3A
	ENDIF

	LD (PTDEC),BC
	LD (PsCalc),HL
	PUSH DE

;note table data depacker
;(c) Ivan Roshin
	LD DE,T_PACK
	LD BC,T1_+(2*49)-1
TP_0	LD A,(DE)
	INC DE
	CP 15*2
	JR NC,TP_1
	LD H,A
	LD A,(DE)
	LD L,A
	INC DE
	JR TP_2
TP_1	PUSH DE
	LD D,0
	LD E,A
	ADD HL,DE
	ADD HL,DE
	POP DE
TP_2	LD A,H
	LD (BC),A
	DEC BC
	LD A,L
	LD (BC),A
	DEC BC
	SUB #F8*2
	JR NZ,TP_0

	INC A
	LD (VARS1+VRS.DelyCnt),A
	LD (VARS2+VRS.DelyCnt),A
	LD HL,#F001 ;H - CHP.Volume, L - CHP.NtSkCn
	LD (VARS1+VRS.ChanA+CHP.NtSkCn),HL
	LD (VARS1+VRS.ChanB+CHP.NtSkCn),HL
	LD (VARS1+VRS.ChanC+CHP.NtSkCn),HL
	LD (VARS2+VRS.ChanA+CHP.NtSkCn),HL
	LD (VARS2+VRS.ChanB+CHP.NtSkCn),HL
	LD (VARS2+VRS.ChanC+CHP.NtSkCn),HL
	POP HL
	LD (VARS1+VRS.ChanA+CHP.OrnPtr),HL
	LD (VARS1+VRS.ChanB+CHP.OrnPtr),HL
	LD (VARS1+VRS.ChanC+CHP.OrnPtr),HL
	LD (VARS2+VRS.ChanA+CHP.OrnPtr),HL
	LD (VARS2+VRS.ChanB+CHP.OrnPtr),HL
	LD (VARS2+VRS.ChanC+CHP.OrnPtr),HL

	POP AF

;NoteTableCreator (c) Ivan Roshin
;A - NoteTableNumber*2+VersionForNoteTable
;(xx1b - 3.xx..3.4r, xx0b - 3.4x..3.6x..VTII1.0)

	LD HL,NT_DATA
	LD D,0
	ADD A,A
	LD E,A
	ADD HL,DE
	LD E,(HL)
	INC HL
	SRL E
	SBC A,A
	AND #A7 ;#00 (NOP) or #A7 (AND A)
	LD (L3),A
	EX DE,HL
	LD BC,T1_
	ADD HL,BC

	LD A,(DE)
	ADD A,T_
	LD C,A
	ADC A,T_/256
	SUB C
	LD B,A
	PUSH BC
	LD DE,NT_
	PUSH DE

	LD B,12
L1	PUSH BC
	LD C,(HL)
	INC HL
	PUSH HL
	LD B,(HL)

	PUSH DE
	EX DE,HL
	LD DE,23
	LD IXH,8

L2	SRL B
	RR C
L3	DB #19	;AND A or NOP
	LD A,C
	ADC A,D	;=ADC 0
	LD (HL),A
	INC HL
	LD A,B
	ADC A,D
	LD (HL),A
	ADD HL,DE
	DEC IXH
	JR NZ,L2

	POP DE
	INC DE
	INC DE
	POP HL
	INC HL
	POP BC
	DJNZ L1

	POP HL
	POP DE

	LD A,E
	CP TCOLD_1
	JR NZ,CORR_1
	LD A,#FD
	LD (NT_+#2E),A

CORR_1	LD A,(DE)
	AND A
	JR Z,TC_EXIT
	RRA
	PUSH AF
	ADD A,A
	LD C,A
	ADD HL,BC
	POP AF
	JR NC,CORR_2
	DEC (HL)
	DEC (HL)
CORR_2	INC (HL)
	AND A
	SBC HL,BC
	INC DE
	JR CORR_1

TC_EXIT

	POP AF
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

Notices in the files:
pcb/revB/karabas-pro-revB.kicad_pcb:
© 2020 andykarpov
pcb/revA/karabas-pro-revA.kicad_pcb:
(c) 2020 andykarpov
